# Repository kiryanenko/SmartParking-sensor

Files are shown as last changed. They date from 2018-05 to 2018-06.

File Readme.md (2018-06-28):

Система мониторинга парковочных мест
====================================
МК-подсистема регистрации свободных парковочных мест
----------------------------------------------------

### АННОТАЦИЯ

Дипломный проект посвящен разработке системы мониторинга парковочных
мест. При выполнении дипломного проекта, было проведено исследование IoT
технологий в сфере транспортной инфраструктуры. В рамках исследования
был проведен анализ существующих систем. На основании этого был
спроектирован недорогой относительно конкурентов аппаратно-программный
прототип системы мониторинга парковочных мест. Основное назначение
системы заключается в определении наличия свободных парковочных мест и
отображении этих данных пользователям. Данная система позволит
пользователям (водителям) в режиме реального времени получать актуальную
информацию о состоянии парковочных мест.

### ABSTRACT

The diploma project is devoted to the development of a monitoring system
for parking places. When carrying out the diploma project, was conducted
research IoT technologies in the field of transport infrastructure. As
part of the research, existing systems were analyzed. Based on this, the
hardware-software prototype of a monitoring system for parking places
was designed inexpensive with respect to competitors. The main purpose
of the system is to determine the availability of parking spaces and
display data for users. This system allows users (drivers) to receive
up-to-date information about status of parking places in real time.

РЕФЕРАТ
-------

Разработан проект «Система мониторинга парковочных мест». Основное
назначение системы заключается в определении наличия свободных
парковочных мест и отображении этих данных пользователям. Данная система
позволит пользователям (водителям) в режиме реального времени получать
актуальную информацию о состоянии парковочных мест. Данная система
состоит из: «МК-подсистемы регистрации свободных парковочных мест»,
вычислительного хаба и сервера.

«МК-подсистема регистрации свободных парковочных мест» фиксирует наличие
свободных парковочных мест. К микроконтроллеру подключаются сенсоры,
каждый из которых следит за своим парковочным местом. Через радиомодуль
RFM95W информация о состоянии парковочных мест (свободно / занято)
передается в вычислительный хаб, для последующей обработки. Реализована
функция оплаты парковочного места, с отображением на дисплее и
подтверждением оплаты с клавиатуры.

Основное назначение вычислительного хаба, состоит в осуществлении
взаимодействия сервера, датчиков «МК-подсистема регистрации свободных
парковочных мест» и других компонентов системы.

Сервер осуществляет сбор данных с датчиков «МК-подсистема регистрации
свободных парковочных», управление всеми компонентами системы и вывод
данных пользователям об актуальном состоянии парковочных мест

Материалы по дипломному проекту представлены в виде графической части,
приложения с отлаженным программным кодом и расчетно-пояснительной
записки.

ОПРЕДЕЛЕНИЯ, ОБОЗНАЧЕНИЯ И СОКРАЩЕНИЯ
-------------------------------------

- БС - беспроводная сеть
- БД - база данных
- МК - микроконтроллер
- МКПМ - модуль контроля парковочного места
- МКПРСПМ - МК-подсистема регистрации свободных парковочных мест
- ОС - операционная система
- ПМ - парковочное место
- ПО - программное обеспечение
- СМПМ - система мониторинга парковочных мест
- СУБД - система управления базами данных
- ТС - транспортное средство
- УГО - условно графическое обозначение.
- EEPROM - энергонезависимая перезаписываемая память
- IoT - internet of things
- LoRa - Long Range, метод модуляции в беспроводных сетях
- MQTT - message queue telemetry transport

СОДЕРЖАНИЕ
----------

[ВВЕДЕНИЕ](#ВВЕДЕНИЕ)

[Анализ требований к СМПМ](#Анализ-требований-к-СМПМ)

[Разработка диаграммы вариантов использований](#Разработка-диаграммы-вариантов-использований)

[Описание и структура СМПМ](#Описание-и-структура-СМПМ)

[Описание функциональной схемы СМПМ](#Описание-функциональной-схемы-СМПМ)

[Разработка МКПРСПМ](#Разработка-МКПРСПМ)

[Анализ требований к разрабатываемому устройству](#Анализ-требований-к-разрабатываемому-устройству)

[Разработка структурной схемы МКПРСПМ](#Разработка-структурной-схемы-МКПРСПМ)

[Разработка функциональной схемы МКПМ](#Разработка-функциональной-схемы-МКПМ)

[Разработка функциональной схемы МКПРСПМ](#Разработка-функциональной-схемы-МКПРСПМ)

[Разработка принципиальной схемы](#Разработка-принципиальной-схемы)

[Выбор элементной базы](#Выбор-элементной-базы)

[Микроконтроллер ATMEGA328](#Микроконтроллер-atmega328)

[Радиочастотный приёмопередатчика RFM95W](#Радиочастотный-приёмопередатчика-rfm95w)

[Расширитель портов PCF8574](#Расширитель-портов-pcf8574)

[Сравнение сенсоров присутствия автомобиля](#Сравнение-сенсоров-присутствия-автомобиля)

[Ультразвуковой датчик расстояния HC-SR04](#Ультразвуковой-датчик-расстояния-hc-sr04)

[Часы реального времени DS3231SN](#Часы-реального-времени-ds3231sn)

[Описание принципиальной схемы МКПМ](#Описание-принципиальной-схемы-МКПМ)

[Описание принципиальной схемы МКПРСПМ](#Описание-принципиальной-схемы-МКПРСПМ)

[Расчет потребляемой мощности](#Расчет-потребляемой-мощности)

[Описание разработанного программного обеспечения](#Описание-разработанного-программного-обеспечения)

[Описание схемы алгоритма](#Описание-схемы-алгоритма)

[Описание диаграммы классов](#Описание-диаграммы-классов)

[Описание системы сообщений МКПРСПМ](#Описание-системы-сообщений-МКПРСПМ)

[Тестирование СМПМ](#Тестирование-СМПМ)

[ЗАКЛЮЧЕНИЕ](#ЗАКЛЮЧЕНИЕ)

[Приложение В. Тестирование](/docs/Приложение%20В.%20Тестирование%20СMПМ.pdf)

[Приложение Е. Графическая документация](/docs/Приложение%20Е.%20Графическая%20документация.pdf)

ВВЕДЕНИЕ
--------

Дипломный проект «Система мониторинга парковочных мест» выполняется на
основании учебного плана кафедры ИУ6 с исходными данными, заданными в
техническом задании. Целью работы является проектирование системы
мониторинга парковочных мест.

Формирование специализированных зон для стоянки автотранспорта началось
почти одновременно с появлением первых автомобилей. Число машин
стремительно растет и для решения возникнувшей проблемы ограниченности
парковочных мест начали внедрять современные технологии.

Основным направлением развития являются «умные» датчики парковки. Такие
датчики встраиваются в дорожное полотно на места парковок и отслеживают
свободно ли машиноместо над ними, отдавая данные в общую систему.
Используя сеть таких датчиков, формируется карта парковок, состояния
которых рассылается пользователям на улицах с помощью специальных табло
или мобильного приложения.

Такая система позволяет решить следующие задачи:
-   сокращение очередей и времени поиска свободного места на парковке;
-   организация оптимального движения транспортных средств и пешеходов
    на парковке;
-   визуальное оповещение о количестве свободных мест в реальном времени
    с помощью информационных табло или на веб-портале;
-   оптимизация работы парковочного пространства.

В ходе данной работы была спроектирована «Система мониторинга
парковочных мест». Основное назначение системы заключается в определении
наличия свободных парковочных мест и отображении этих данных
пользователям. Данная система позволит пользователям (водителям) в
режиме реального времени получать актуальную информацию о состоянии
парковочных мест. Данная система состоит из: «МК-подсистемы регистрации
свободных парковочных мест», вычислительного хаба и сервера.

Анализ требований к СМПМ
========================

Разработка диаграммы вариантов использований
--------------------------------------------

Основное назначение СМПМ заключается в определении наличия свободных
парковочных мест и отображении этих данных пользователям. Данная система
позволяет пользователям (водителям) в режиме реального времени получать
актуальную информацию о состоянии парковочных мест.

Для уточнения требований к функционированию системы необходимо
определить варианты её использования при помощи диаграммы вариантов
использования. Система взаимодействует с двумя видами действующих лиц:
пользователь (водитель) и владелец стоянки. Соответствующие диаграммы
для этих лиц показаны на рисунках 5 и 6.

Диаграмма вариантов использований для пользователя

Рисунок 5 - Диаграмма вариантов использований для пользователя

Диаграмма вариантов использований для владельца стоянки

Рисунок 6 - Диаграмма вариантов использований для владельца стоянки

Описание и структура СМПМ
-------------------------

На рисунке 7 представлена структурная схема системы мониторинга
парковочных мест. Система мониторинга парковочных мест состоит из
следующих блоков:
-   МК-подсистема регистрирования свободных парковочных мест (МКПРСПМ),
-   вычислительный хаб,
-   сервер.

Датчики МКПРСПМ служат для фиксации наличия свободных парковочных мест и
оплаты. МКПРСПМ формирует пакеты с информацией о свободных парковочных
местах и передаёт их на вычислительный хаб по беспроводной сети LoRaWAN.

Вычислительный хаб, представленный в виде микрокомпьютера Raspberry Pi,
необходим для осуществления взаимодействия сервера, МКПРСПМ и других
компонентов системы. Хаб выполняет приём пакетов, переданных с МКПРСПМ,
формирует пакеты MQTT и передает их на сервер по сети интернет. Обратно
от сервера хаб получает команды управления МКПРСПМ, которые также
передаются по сети LoRaWAN, на МК-подсистемы.

Пользователь с мобильного устройства на платформе Android с
установленным приложением сможет посмотреть карту с указанием
местоположений свободных парковочных мест. Мобильное приложение получает
данные о парковочных местах с помощью API-сервисов, предоставляемых
сервером.

Структурная схема системы мониторинга парковочных мест

Рисунок 7 - Структурная схема системы мониторинга парковочных мест

Веб-клиент, предоставляет карту со свободными парковочными местами.
Также для владельцев стоянок, предоставляется возможность для управления
за парковочными местами: изменение тарифного плана, настройка параметров
МКПСРСПМ.

Описание функциональной схемы СМПМ
----------------------------------

На рисунке Рисунок 8 показана функциональная схема СМПМ. Система
работает следующим образом. В МКПРСПМ сигнал о состоянии парковочного
места приходит от сенсора присутствия автомобиля, после чего МК
ATMEGA328 формирует пакеты и отправляет их через радиомодуль RFM95 по
сети LoRaWAN на вычислительный хаб. Также по сети LoRaWAN МКРСППМ может
принять команды для изменения настроечных параметров.

Вычислительный хаб служит для осуществления взаимодействия сервера,
МКПРСПМ и других компонентов системы. Хаб через радиомодуль RFM95
принимает пакеты, переданные с МКПРСПМ, формирует MQTT пакеты и передает
их на сервер и на другие компоненты системы. Данные внутри MQTT пакетов
передаются в формате JSON. Обратно от сервера хаб получает команды
управления МКПРСПМ, которые также передаются по сети LoRaWAN, на
МК-подсистемы. ПО для вычислительного хаба написано с использованием
фреймворка Qt. На вычислительном хабе может быть установлено серверное
ПО, тем самым хаб сформирует локальную сеть, внутри которой сможет
работать как сервер. MQTT - это легкий протокол для передачи данных,
который идеально подходит для взаимодействия большого количества IoT
устройств. Таким образом, к вычислительному хабу возможно подключить
множество других устройств (например, табло индикации количества
свободных парковочных мест), позволяющие взаимодействовать по протоколу
MQTT.

Функциональная схема СМПМ

Рисунок 8 - Функциональная схема СМПМ

Сервер взаимодействует с вычислительным хабом по протоколу MQTT. Для
этого на сервере установлен MQTT брокер Mosquitto. Приложение на
фреймворке Ruby on Rails принимает данные о состоянии ПМ через MQTT
брокер и сохраняет в БД PostgreSQL. Также сервер может управлять
датчиками МКПРСПМ, отправляя команды по протоколу MQTT на вычислительный
хаб. Сервер Nginx является Frontend сервером, он осуществляет раздачу
статики и проксирование запросов на веб-сервер Puma, который уже
взаимодействует с веб-приложением на Ruby on Rails. Веб-приложение для
кэширования использует сервис кэширования Memcached. Для работы Action
Cable, который осуществляет взаимодействие с веб-клиентами по WebSocket,
необходима «key - value» хранилище данных Redis. Чтобы веб-клиент в
режиме реального времени получал данные о состоянии парковочных мест,
данные о парковочных местах в формате JSON периодически отправляются по
протоколу WebSocket.

Разработка МКПРСПМ
==================

Анализ требований к разрабатываемому устройству
-----------------------------------------------

Согласно техническому заданию, необходимо разработать МК-подсистему
регистрации свободных парковочных мест, выполненный на основе
микроконтроллера ATMEGA328. Данный регистратор фиксирует наличие
свободных парковочных мест. К микроконтроллеру подключаются сенсоры,
каждый из которых следит за своим парковочным местом. Через радиомодуль
информация о состоянии парковочных мест (свободно / занято) передается в
вычислительный хаб Raspberry Pi для последующей обработки. Должна быть
реализована функция оплаты парковочного места.

Проанализировав задание, можно заключить, что разрабатываемая система
должна представлять собой аппаратно-программный модуль, содержащий
непосредственно микроконтроллер ATMEGA328, запрограммированный
исполняющей программой. К микроконтроллеру через расширители портов
PCF8574 подключаются сенсоры, следящие за парковочными местами. Также,
расширитель портов PCF8574 используется для вывода информации о
состоянии закрепленного за ним парковочного места. Для коммуникации с
вычислительным хабом Raspberry Pi используется радиомодуль LoRa. Для
реализации функции оплаты парковочного места используется терминал
оплаты, состоящий из дисплея и клавиатуры. Работа с терминалом построена
в диалоговом режиме.

Разработка структурной схемы МКПРСПМ
------------------------------------

МКПРСПМ служит для фиксации наличия свободных парковочных мест и оплаты.
Данная подсистема состоит из следующих элементов (Рисунок 9):
-   микроконтроллер ATMEGA328,
-   модули контроля парковочного места (МКПМ),
-   терминал оплаты,
-   радиомодуль RFM95W.
-   Часы реального времени DS3231

Каждое парковочное место оборудовано МКПМ, состоящем из сенсора, который
определяет свободно ли парковочное место, и расширителем портов PCF8574,
для подсоединения сенсора к МК. Выводами «Free» и «Booked» служат для
отображения информации о текущем состоянии данного парковочного места.
Логическая «1» на выводе «Free» означает, что данное парковочное место
свободно, а «0» - занято. Логическая «1» на выводе «Booked» означает,
что данное место забронировано, а «0» - нет.

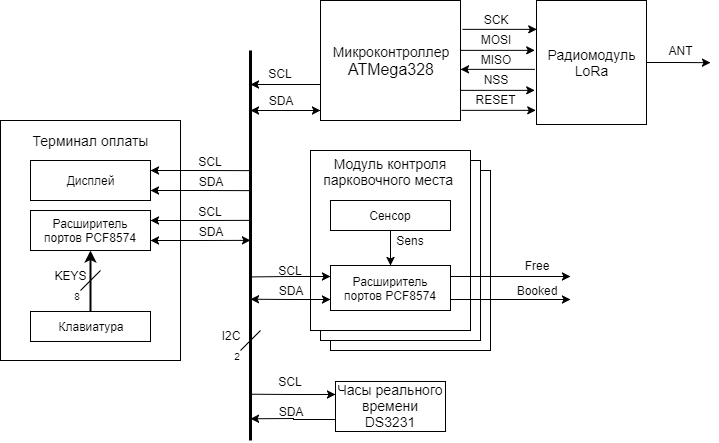
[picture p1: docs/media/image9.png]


Рисунок 9 - Структурная схема МКПРСПМ

Микроконтроллер ATMEGA328 с помощью модулей МКПМ считывает информацию о
состоянии парковочных мест и устанавливает на индикаторах МКПМ
соответствующие состояния. Далее микроконтроллер формирует пакеты с
информацией о свободных парковочных местах для передачи на
вычислительный хаб по беспроводной сети LoRaWAN.

Радиомодуль LoRa осуществляет приём / передачу данных по сети LoRaWAN.
Данный модуль подключён к МК по шине SPI.

Терминал оплаты осуществляет оплату парковочного места по заданному
тарифу. Он состоит из дисплея, для отображения информации для
пользователя, клавиатуры для ввода данных и расширителем портов PCF8574
для соединения клавиатуры с МК по шине I2C.

Часы реального времени DS3231 необходимы для постоянного учёта
хронометрических данных (дата, время) на микроконтроллере. Это позволяет
изменять тариф для оплаты парковочного места в зависимости от времени
суток. А также позволяет отображать текущее время на дисплее. Установка
заданного времени на часах происходит при приходе соответствующего
сообщения «Изменить время» (Описание системы сообщений МКПРСПМ).

Разработка функциональной схемы МКПМ
------------------------------------

Каждое парковочное место оборудованы МКПМ, который определяет свободно
ли данное парковочное место и выводит информацию о состоянии этого
парковочного места.

Была разработана функциональная схема МКПМ, представленная на рисунке Е.5. 
Данная схема описывает функциональный блок «PPCM» (Рисунок 10),
который используется при построении функциональной схемы МКПРСПМ.

УГО функционального блока PPCM

Рисунок 10 - УГО функционального блока PPCM

Ниже на рисунке Рисунок 11, показана функциональная схема МКПМ.

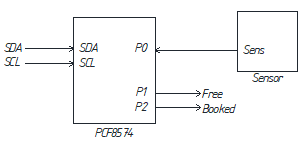
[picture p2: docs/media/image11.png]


Рисунок 11 - Функциональная схема МКПМ

Схема состоит из двух блоков:
-   Сенсор, который определяет свободно ли данное парковочное место.
-   Расширитель портов PCF8574, осуществляющий связь сенсора с МК, а
    также через выводы P1 и P2 выводит информацию о состоянии
    парковочного места. Расширитель подключен к МК по шине I2C. К выводу
    P0 подключается сенсор. Выход P1 выводит сигнал «Free», логическая
    «1» которого означает, что данное парковочное место свободно, а «0» - занято. 
    Выход P2 выводит сигнал «Booked», логическая «1» которого
    означает, что данное парковочное место забронировано, а «0» - нет.

Разработка функциональной схемы МКПРСПМ
---------------------------------------

Исходя из результатов анализа требований, можно выделить следующие функциональные блоки МКПРСПМ:
-   микроконтроллер ATMEGA328;
-   радиомодуль LoRa BEE;
-   USB-UART драйвер ATMEGA16U2
-   модулей МКПМ (PPCM) в количестве до 15 штук, устанавливаемых на каждое парковочное место;
-   клавиатура;
-   расширитель портов PCF8574 для подключения клавиатуры к микроконтроллеру;
-   дисплей;
-   часы реального времени DS3231.

В результате проведенного анализа, была спроектирована функциональная
схема взаимодействия элементов, приведенная на рисунке Е.6.

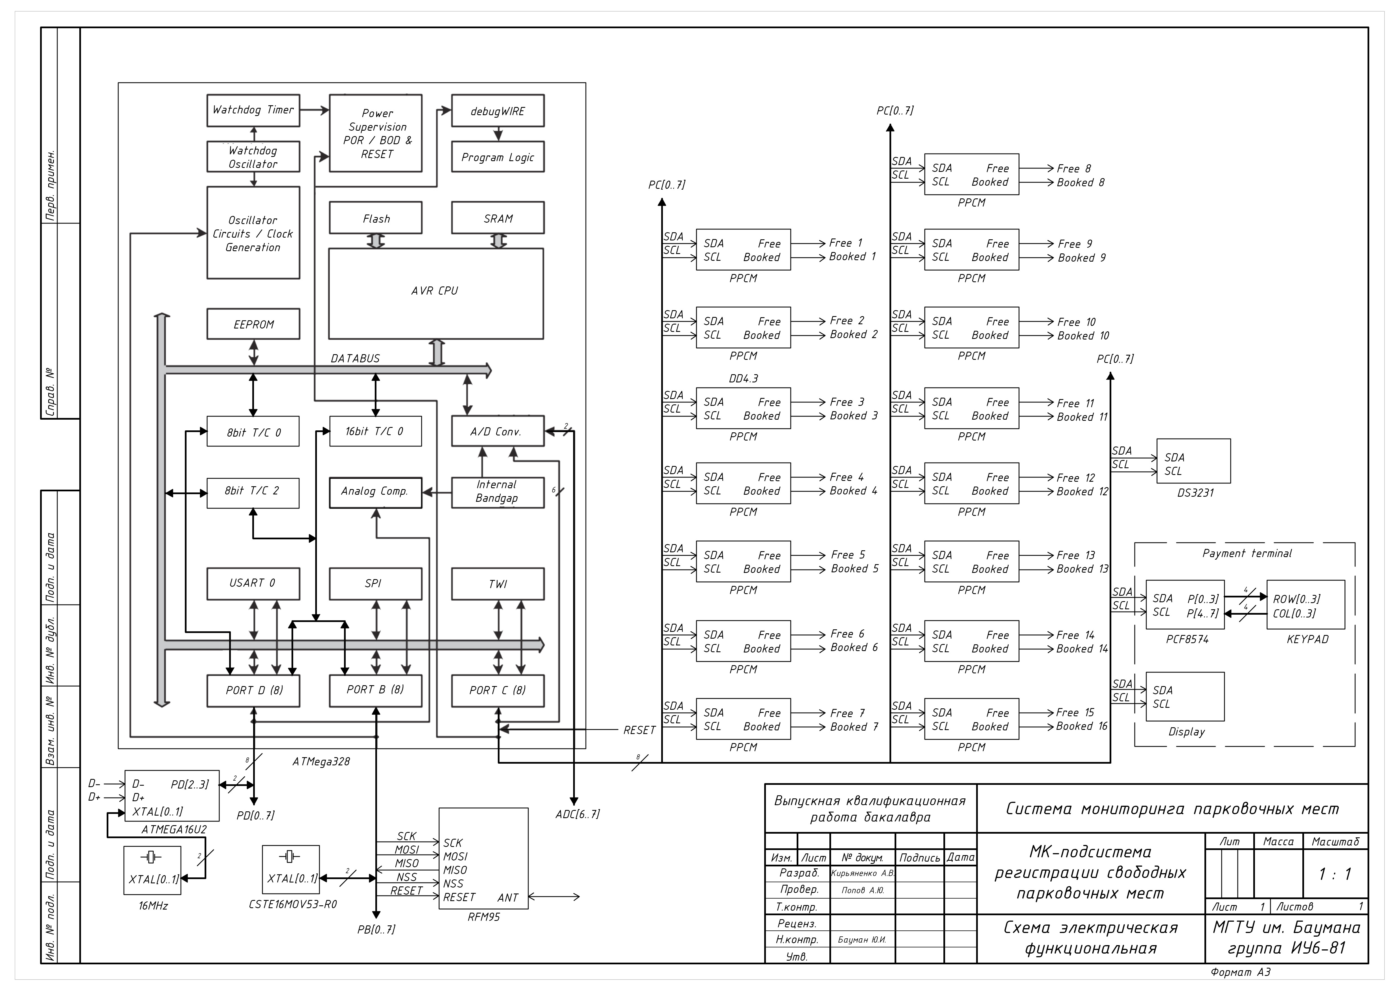
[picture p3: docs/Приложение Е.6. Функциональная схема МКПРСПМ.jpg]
Функциональная схема МКПРСПМ


Разберем структуру взаимодействия элементов на функциональной схеме. На
каждое парковочное место устанавливается МКПМ. Микроконтроллер ATMEGA328
с помощью модулей МКПМ, подключенных к МК по шине I2C, считывает
информацию о состоянии парковочных мест. После обработки данных,
микроконтроллер изменяет состояние парковочного места (свободно /
занято), установив выводы МКПМ в соответствующие состояния. Далее,
микроконтроллер формирует пакет с информацией о состоянии парковочного
места и отправляет его через шину SPI на радиомодуль LoRa BEE, который,
в последствии, передаёт на вычислительный хаб Raspberry Pi, для
последующей обработки.

Для осуществления оплаты заданного парковочного места используется
терминал оплаты, состоящий из дисплея, матричной клавиатуры и
расширителя портов PCF8574 для соединения клавиатуры с МК по шине I2C.
Дисплей подключается к МК по шине I2C. В диалоговом режиме на нём
отображается информация о текущем состоянии оплаты. МК через расширитель
портов опрашивает клавиатуру и определяет нажатые клавиши. Для опроса
клавиатуры подаются на выходы расширителя, подключенные к столбцам
клавиатуры, сканирующие импульсы, а на входах, подключенных к строкам,
определяется, какая клавиша из соответствующего столбца нажата. Далее МК
соответствующе обрабатывает нажатые клавиши и отображает результат
обработки на дисплей.

Разработка принципиальной схемы
-------------------------------

### Выбор элементной базы

#### Микроконтроллер ATMEGA328

В данной работе решено было использовать микроконтроллер семейства AVR,
так как он: широко распространен, имеет развитую систему команд,
удовлетворяет всем современным технологическим требованиям. Данное
семейство восьмиразрядных микроконтроллеров имеет обширное количество
различных моделей. Было решено использовать ATMEGA328 как широко
распространенный и недорогой микроконтроллер, позволяющий реализовать
все поставленные задачи. УГО данного МК показано на рисунке Рисунок 12.

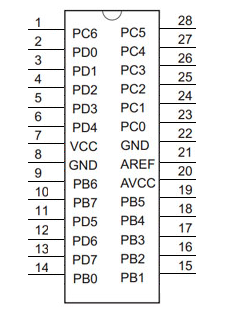
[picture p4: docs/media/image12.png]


Рисунок 12 - УГО ATMEGA328

Описание выводов микроконтроллера приведено в таблице 1.

Таблица 1 - Описание выводов МК ATMEGA328

| № вывода | Мнемоника | Назначение вывода |
|---|---|---|
| 7 | VCC | Питание +5В |
| 8 | GND | Земля |
| 17 | MOSI | Вход ведомого. Служит для передачи данных от ведущего устройства ведомому  |
| 18 | MISO | Выход ведомого. Служит для передачи данных от ведомого устройства ведущему |
| 19 | SCK | Последовательный тактовый сигнал |
| 3-6, 11-19 | PD1-PD6, PB0-PB5 | Цифровые входы/выходы |
| 23-28 | PC0-PC5 | Аналоговые входы/выходы |
| 1 | PC6 | Перезапуск МК |
| 2 | PD0 | Чтение (разъем для программатора) |
| 9 | PB6 | Подключение внешнего резонатора (вход) |
| 10 | PB7 | Подключение внешнего резонатора (выход) |

Микроконтроллер ATMEGA328 обладает следующими особенностями и
техническими характеристиками:
1.  расширенная архитектура RISC:
    -   мощная система команд со 131 инструкцией, большинство из которых выполняются за один машинный цикл,
    -   32 восьмиразрядных регистра общего назначения,
    -   производительность до 20 млн. оп./с на частоте 20МГц,
    -   встроенное умножение за 2 цикла;
2.  высокая износостойкость энергонезависимых сегментов памяти:
    -   32 КБ встроенной самопрограммируемой flash-памяти,
    -   1 КБ энергонезависимой памяти (EEPROM),
    -   2 КБ статической памяти (SRAM),
    -   10000/100000 циклов перезаписи для Flash/EEPROM,
    -   хранение данных в течение 20 лет при температуре 25${^\circ}$С,
3.  системы ввода-вывода: 23 программируемые линии ввода-вывода;
4.  рабочее напряжение: от 1.8 до 5.5 В;
5.  рабочая температура: от -40${^\circ}$ до 85${^\circ}$ С;
6.  рабочая частота (4.5 - 5.5В): 20 МГц;
7.  энергопотребление (1МГц, 1.8 В, 25${^\circ}$ С):
    -   активный режим: 0.2 мА,
    -   режим пониженного энергопотребления: 0.1 мкА.

#### Радиочастотный приёмопередатчика RFM95W

RFM95W - модуль радиочастотного приёмопередатчика, работающий на
частоте 868/915 МГц Работа приёмопередатчика основана на технологии
LoRa, которая позволяет добиться широкополосной передачи данных при
крайне низком энергопотреблении, а также высокой помехоустойчивости. 
Описание выводов RFM95W представлено в таблице 3.

Таблица 3 - Описание выводов RFM95W

  № Вывода                | Мнемоника                            | Описание
  ----------------------- | ------------------------------------ | --------------------------------------------
  1, 8, 10                | GND                                  | Земля
  2                       | MISO                                 | SPI выход последовательной передачи данных
  3                       | MOSI                                 | SPI вход последовательного приема данных
  4                       | SCK                                  | SPI вход синхронизации приема данных
  5                       | NSS                                  | SPI вход выбора подчиненного
  6                       | RESET                                | Вход сброса
  7, 11, 12, 14, 15, 16   | DIO5, DIO3, DIO4, DIO0, DIO1, DIO2   | Цифровой вход / выход конфигурации
  9                       | ANT                                  | Вход / выход на антенну
  13                      | 3,3V                                 | Питание 3,3В

**Технические характеристики:**
-   Максимальный размер канала связи 168 дБ.
-   Режим повышенной мощности, +20дБм/100мВт.
-   Стандартный режим +14 дБм.
-   Программируемая скорость передачи данных до 300 кбит / с.
-   Высокая чувствительность: до -148 дБм.
-   Низкий ток потребления пи приёме 10,3 мА.
-   Полностью интегрированный синтезатор с разрешением 61 Гц.
-   FSK, GFSK, MSK, GMSK, LoRaTM и OOK модуляции.
-   127 дБ динамический диапазон RSSI.
-   Пакетный движок до 256 байтов с CRC.
-   Встроенный датчик температуры и индикатор разряда батареи.
-   Размер модуля: 16x16 мм

#### Расширитель портов PCF8574

PCF8574 - кремневая ИС, выполненная по CMOS-технологии.
Посредством двухлинейной двунаправленной шины I2C она обеспечивает
дистанционное расширение порта ввода - вывода общего назначения в
большинстве серий микроконтроллеров. Устройство состоит из 8-битного
квазипорта ввода-вывода и интерфейса I2C-шины. PCF8574 имеет низкий
потребляемый ток. В устройстве установлена линия прерывания (INT),
которая может быть подключена к логике прерывания микроконтроллера.
Посылая сигнал прерывания по этой линии, дистанционный ввод - вывод
сообщает микроконтроллеру о поступающих на его порты данных, без
необходимости поддерживать связь через I2C-шину. Это значит, что PCF8574
может оставаться простым \"подчиненным\" устройством. На рисунке 14 приведено УГО модификаций PCF8574P и PCF8574AP.

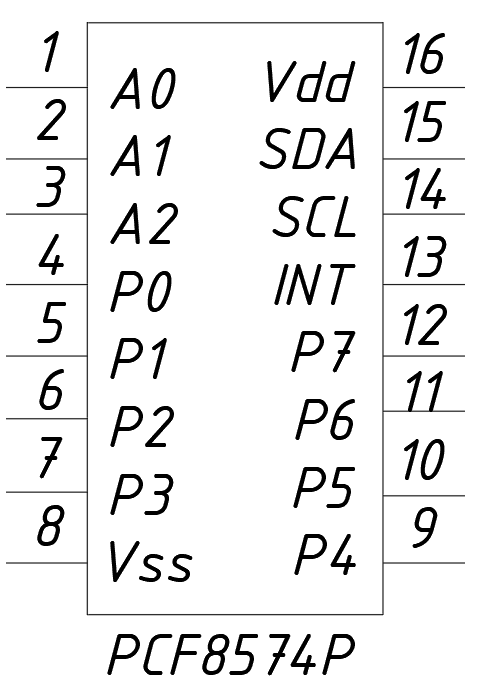
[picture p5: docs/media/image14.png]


Рисунок 14 - УГО расширителя портов PCF8574P и PCF8574AP

В таблице 4 приведено описание выводов PCF8574.

Таблица 4 - Описание выводов PCF8574P / PCF8574AP

  № Вывода          | Мнемоника            | Описание
  ----------------- | -------------------- | --------------------------------------
  1 - 3             | A0 - A2              | Адресные входы
  4 - 7, 9 - 12     | P0 - P3, P4 - P7     | Квази-двунаправленный ввод / вывод
  8                 | Vss                  | Земля
  13                | INT                  | Вывод прерывания
  14                | SCL                  | Последовательная линия синхронизации
  15                | SDA                  | Последовательная линия данных
  16                | Vdd                  | Питание 5 В

У данной микросхемы PCF8574 можно задавать адрес, под которым она будет
обозначаться на шине I2C. Всего имеется 8 вариантов адресации т.е. можно
подключить 8 модулей, что в сумме позволяет нарастить 64 входа/выхода,
используя 2 вывода контроллера. Для изменения адресации необходимо
установить на выводах A0, A1, A2 потенциал, соответствующий логическому «0» или «1».

Модификация PCF8574AP отличается от PCF8574P только базовым адресом: у
PCF8574P - 0x20, а у PCF8574AP - 0x38. Сделано это для того, чтобы к
одной шине можно было подключить до 16-ти расширителей с разными
адресами - максимум 8 штук PCF8574 и 8 штук PCF8574A.

**Технические характеристики:**
-   Рабочий режим питания - от 2.5 до 6 В
-   Низкий ток покоя - максимум 10 мА
-   I^2^C-шина для расширителя параллельного порта
-   Выход прерывания с открытым стоком
-   Дистанционный 8-битный расширитель ввода - вывода I^2^C-шины
-   Адресация на 3 вывода аппаратных адресов для использования до 8
    устройств (до 16 устройств при использовании PCF8574A)

В данной работе каждый расширитель портов закреплен за своим парковочным
местом. Они используются для считывания данных с сенсоров и для вывода
информации о состоянии парковочного места. Был выбран расширитель портов
PCF8574, представленный в форм-факторе PCF8574P и PCF8574АP.

#### Сравнение сенсоров присутствия автомобиля

Ниже в таблице Таблица 5 приведено сравнение сенсоров присутствия автомобиля:

Таблица 5 - Сравнение сенсоров присутствия автомобиля

Свойство                                               | HC-SR04           | E18-D80NK            | US-015            | JSN-SR04T
------------------------------------------------------ | ----------------- | -------------------- | ----------------- | -----------------
Тип                                                    | Ультразвук-овой   | Фотоэлектр-ический   | Ультразвук-овой   | Ультразвук-овой
Обнаружение прозрачных объектов                        | +                 | -                    | +                 | +
Невосприимчивость к бликам                             | +                 | -                    | +                 | +
Работоспособность в условиях недостаточной видимости   | +                 | -                    | +                 | +
Дальность обнаружения                                  | 500 см            | 80 см                | 700 см            | 450 см
Нижний порог обнаружения                               | 3 см              | 3 см                 | 2 см              | 25 см
Цена                                                   | 90 руб            | 280 руб              | 160 руб           | 730 руб

В результате проведенного сравнения (Таблица 5) В качестве сенсора,
следящего за состоянием парковочного места, был выбран ультразвуковой
датчик расстояния HC-SR04, т.к. данный ультразвуковой датчик имеет
следующие преимущества:
-   обнаружение прозрачных объектов;
-   невосприимчивость к световым вспышкам и бликам;
-   работоспособность в сложных условиях (туман, пыль, пар);
-   низкая цена.

#### Ультразвуковой датчик расстояния HC-SR04

Бесконтактный направленный датчик HC-SR04, используя
ультразвуковые волны, измеряет расстояние до объекта. На плате модуля
размещены пьезоизлучатель ультразвука и воспринимающий отраженную волну
микрофон. В отличие от инфракрасных дальномеров на ультразвуковой датчик
HC-SR04 не влияют источники света или цвет препятствия. 
Внешний вид данного датчика показан на рисунке 15.

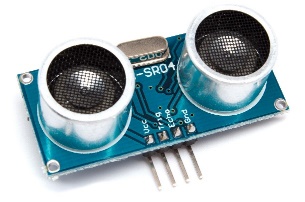
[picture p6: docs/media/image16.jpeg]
Внешний вид ультразвукового датчика расстояния HC-SR04 http://edusnab.ru/upload/iblock/d09/d09faf9a969df7717f0798c8ba945372.jpg


Рисунок 15 - Внешний вид ультразвукового датчика расстояния HC-SR04

Ниже в таблице Таблица 6 приводится описание выводов данного датчика.

Таблица 6 - Описание выводов ультразвукового датчика расстояния HC-SR04

  № Вывода   | Мнемоника   | Описание
  ---------- | ----------- | --------------------------------------------------------------------------------------------------------------------------------------------
  1          | VCC         | Питание +5В
  2          | GND         | Земля
  3          | Trig        | Цифровой вход для включения измерения
  4          | Echo        | Цифровой выход. После завершения измерения, на этот выход будет подана логическая единица на время, пропорциональное расстоянию до объекта

Технические характеристики:
-   Напряжение питания 5 В
-   Ток потребления в режимах
-   ожидания до 2 мА
-   работы 15 мА
-   Частота ультразвука 40 кГц
-   Угол обзора 15 градусов
-   Измеряемое расстояние
-   от 0,03 до 0,6 м с разрешающей способностью 3 мм
-   от 0,6 до 5 м погрешность увеличивается

**Принцип работы:**
1.  Подается импульс продолжительностью 10 мкс, на вывод `Trig`.
2.  Внутри дальномера входной импульс преобразуется в 8 импульсов
    частотой 40 КГц и посылается вперед через \"T глазик\"
3.  Дойдя до препятствия, посланные импульсы отражаются и принимаются
    \"R глазиком\" (Рисунок 17). Получаем выходной сигнал на выводе `Echo`.
4.  Непосредственно на стороне контроллера переводим полученный сигнал в
    расстояние.

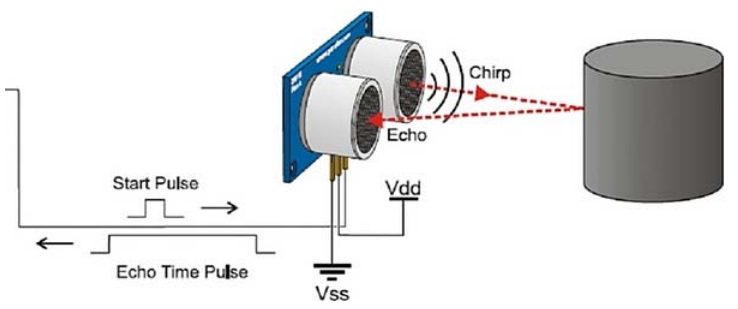
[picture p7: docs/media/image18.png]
Принцип работы ультразвукового датчика расстояния HC-SR04


Рисунок 17 - Принцип работы ультразвукового датчика расстояния HC-SR04

#### Часы реального времени DS3231SN

Для постоянного учёта хронометрических данных (дата, время) на
микроконтроллере используются часы реального времени DS3231SN. Внешний
вид модуля часов реального времени представлен на рисунке 18.

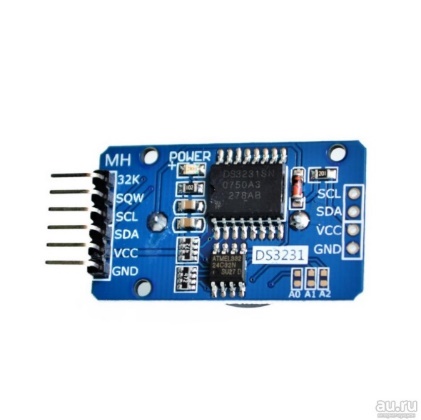
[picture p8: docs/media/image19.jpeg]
Внешний вид модуля часов реального времени DS3231SN https://media2.24aul.ru/imgs/583aea12231ede39d8a435ef/modul-chasov-realnogo-vremeni-zs042-arduino-rtc-2-8614799.jpg


Рисунок 18 - Внешний вид модуля часов реального времени DS3231SN

В таблице 7 приводится описание выводов часов.

Таблица 7 - Описание выводов часов реального времени DS3231SN

  № Вывода   | Мнемоника   | Описание
  ---------- | ----------- | -------------------------------------------
  1          | 32kHz       | Тактовый вывод с частотой 32кГц
  2          | VCC         | Питание +5В
  3          | SQW         | Программируемый выход Square-Wave сигнала
  4          | RST         | Сброс
  5 - 12     | N.C.        | Не соединения
  13         | GND         | Земля
  14         | V~BAT~      | Питание от батареи 3,3В
  15         | SDA         | Последовательная линия данных
  16         | SCL         | Последовательная линия синхронизации

**Технические характеристики:**
-   Рабочая температура -40°C \~ 85°C
-   Напряжение питания, батареи 2,3 V \~ 5,5 V
-   Напряжение питания 2,3 V \~ 5,5 V
-   Интерфейс подключения I²C

Микросхема DS3231 представляет собой высокоточные часы реального времени
RTC, которая обладает встроенным кварцевым генератором с температурной
компенсацией, благодаря чему уход времени составляет всего ±2 минуты за
год. Дополнительно реализована функция будильника, также имеется выход прерываний.

Микросхема использует интерфейс передачи данных I2C. Адрес микросхемы (7 бит) на шине I2C равен `1101000`.

### Описание принципиальной схемы МКПМ

Были спроектированы принципиальные схемы МКПМ на базе PCF8574P и
PCF8574АP, которые представлены на рисунках Е.8 и Д10 соответственно.
Данные схемы соответственно описывают блоки `PPCM` и `PPCM_A`. 
Данные модули отличаются от друг драга - модификацией расширителя порта PCF8574, на которой они построены.
Модуль PPCM построен на базе расширителя порта PCF8574P, а `PPCM_A` - на
базе PCF8574АP. Функциональная схема данных модулей представлена на
рисунке Е.5 и была описана в п.п. 0. В таблице Таблица 8 приведено
описание выводов МКПМ.

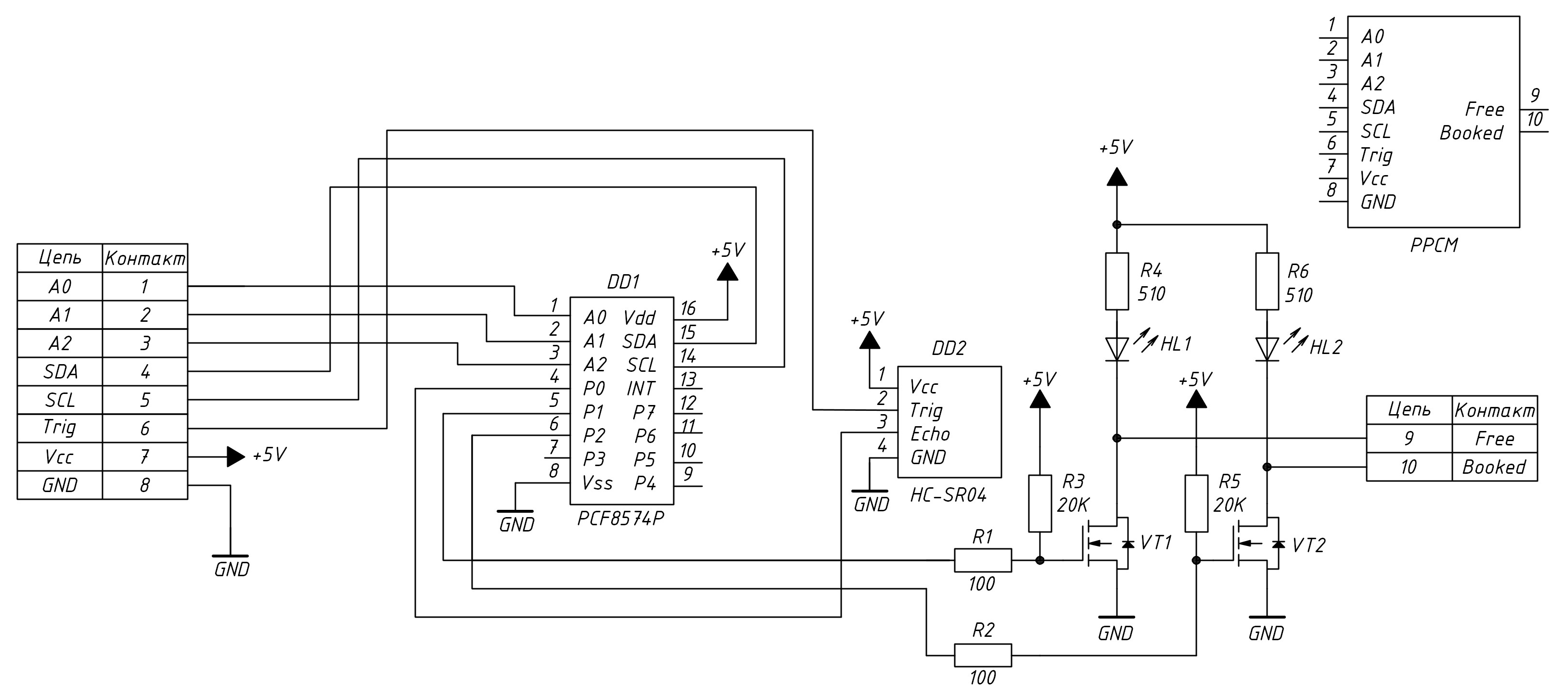
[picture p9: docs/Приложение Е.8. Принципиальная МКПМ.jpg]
Принципиальная схема МКПМ


Таблица 8 - Описание выводов модулей PPCM / PPCM_A

  № Вывода   | Мнемоника   | Описание
  ---------- | ----------- | ----------------------------------------------------------------------------------------------------------
  1 - 3      | A0 - A2     | Адресные входы
  4          | SDA         | Последовательная линия данных
  5          | SCL         | Последовательная линия синхронизации
  6          | Trig        | Цифровой вход для включения измерения
  7          | VCC         | Питание +5В
  8          | GND         | Земля
  9          | Free        | Выводит сигнал «Free» логическая «1» означает, что данное парковочное место свободно, а «0» - занято
  10         | Booked      | Выводит сигнал «Booked» логическая «1» означает, что данное парковочное место забронировано, а «0» - нет

За каждым парковочным местом закреплен свой МКПМ, состоящий из
расширителя портов PCF8574 (DD1) и сенсора HC-SR04 (DD2). Расширитель
портов осуществляет связь МК с сенсором и выводит информацию о состоянии
парковочного места. К выводам P1 и P2 расширителя соответственно
подключены светодиоды VD1 и VD2, которые наглядно показывают состояние
данного парковочного места. Данный расширитель портов подключены к МК по
шине I2C. PCF8574 имеет 3 адресных входа, таким образом, можно
подключить до 8 таких устройств, следовательно, МКПРСПМ может
обслуживать до 8 парковочных мест. Модификация PCF8574AP имеет другой
базовый адрес, следовательно, параллельно можно подключить еще 8
устройств PCF8574AP, тогда разрабатываемое устройство сможет обслуживать
до 15 парковочных мест + 1 расширитель для подключения клавиатуры к МК.
В таблице 9 приведено описание ролей выводов расширителя портов PCF8574 (DD2).

Таблица 9 - Роли выводов расширителя портов PCF8574P / PCF8574AP

  Контакт                 | Роль
  ----------------------- | ---------------------------------------------------------------------------------------
  1, 2, 3 - A0, A1, A2    | Адресные входы
  4 - P0                  | Выход на вывод Trig сенсора HC-SR04 для включения измерения
  5 - P1                  | Выводится логическая «1», в случае если парковочное место свободно, иначе - «0»
  6 - P2                  | Выводится логическая «1», в случае если парковочное место забронировано, иначе - «0»
  8 - Vss                 | Земля
  14 - SCL                | Последовательная линия синхронизации
  15 - SDA                | Последовательная линия данных
  16 - Vdd                | Питание +5В

Сенсор HC-SR04 (DD2) осуществляет мониторинг занятости данного
парковочного места. Вход Trig сенсора соединен с выводом P0 расширителя
портов PCF8574 (DD1). Для включения измерения сенсора МК подаёт сигнал
на вывод P0 соответствующего расширителя портов. После завершения
измерения на выходе Echo сенсора HC-SR04 будет подана логическая единица
на время, пропорциональное расстоянию до объекта. Выход Echo сенсора
соединён с МК через вход PD3. В таблице 10 приведено описание
ролей выводов данного сенсора.

Таблица 10 - Роли выводов сенсора HC-SR04

  Контакт     | Роль
  ----------- | -------------------------------------------------------------------------------------------------------------------------
  1 - VCC     | Питание +5В
  2 - GND     | Земля
  3 - Echo    | Цифровой вход для включения измерения.
  4 - Trig    | Цифровой выход, после завершения измерения, будет подана логическая единица на время, пропорциональное расстоянию до ТС

Расширители портов PCF8574 (DD1) выдают очень низкий ток 100 мкА,
поэтому были добавлены MOSFET-транзисторы (VT1, VT2) для усиления
выходных сигналов «Free» и «Booked». В цепь затвора транзисторов были
добавлены подтягивающие резисторы (R3, R5), чтобы гарантированно
удерживать высокий уровень на затворе мосфета при отсутствии сигнала
низкого уровня от расширителя (DD1). Это исключает самопроизвольное
выключение транзистора. В разрыв цепи затвора также установлены
резисторы (R1, R2) номиналом 100 Ом, для предотвращения кратковременных
выбросов тока и защиты вывода PCF8574.

### Описание принципиальной схемы МКПРСПМ

На основе описанной элементной базы была разработана
принципиальная схема МКПРСПМ для 15 парковочных мест, которая доступна
для ознакомления на рисунке Е.13.

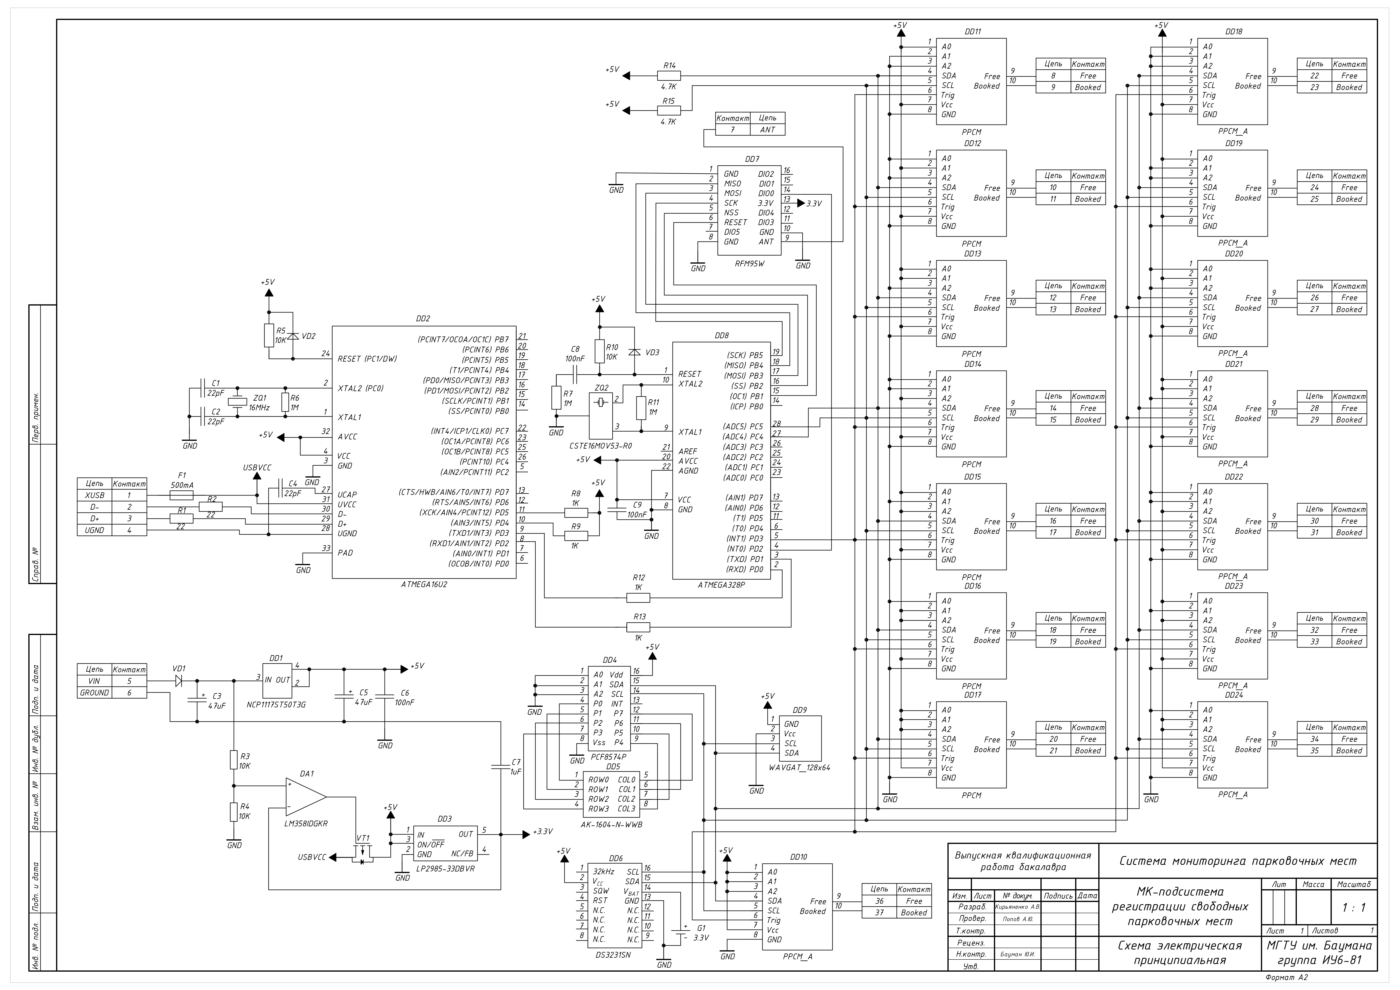
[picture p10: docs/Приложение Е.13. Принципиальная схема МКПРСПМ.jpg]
Принципиальная схема МКПРСПМ


Модуль RFM95W (DD7), осуществляющий передачу и приём данных по сети
LoRa, подключен к МК ATMEGA328P-PU (DD8) шине SPI. В таблице 11
приведено описание подключения модуля RFM95W к МК.

Таблица 11 - Подключение модуля RFM95W к МК ATMEGA328P

  Контакт RFM95W    | Контакт МК         | Роль
  ----------------- | ------------------ | -----------------------------------------------------------------------------------
  1, 8, 10 - GND    | -                  | Земля
  2 - MISO          | 18 - PB4 (MISO)    | Приём данных от модуля на МК
  3 - MOSI          | 17 - PB3 (MOSI)    | Передача данных от МК на модуль
  4 - SCK           | 19 - PB5 (SCK)     | Синхронизация передачи данных
  5 - NSS           | 16 - PB2 (SS)      | Выбор подчиненного устройства
  6 - RESET         | 15 - PB1           | Перезапуск модуля
  9 - ANT           | -                  | Вывод на антенну
  13 - 3,3V         | -                  | Питание +3,3В
  14 - DIO0         | 4 - PD2 (INT0)     | Возникновение прерывание на МК при успешном приёме / передачи пакета по сети LoRa

Микроконтроллер Arduino Uno R3 содержит встроенный драйвер USART-USB,
выполненный на ATMEGA16U2 (DD2), необходимый для передачи и приёма
данных на ПЭВМ по последовательному интерфейсу. Таким образом, с помощью
данного модуля можно, как альтернатива модулю RFM95, осуществлять приём / передачу данных.

Для работы шины I2C необходима внешняя подтяжка к питанию, состоящая из
двух резисторов. В данном проекте такими резисторами являются R14 и R15,
номинал которых равен 4,7КОм.

За каждым парковочным местом закреплен свой модуль МКПМ (DD10 - DD24),
которые разделяются на две модификации PPCM (DD11 - DD17) и PPCM_A
(DD10, DD18 - DD24). Данные модули подключаются к МК по шине I2C. PPCM
отличается от PPCM\_A только базовым адресом: у PPCM - `0x20`, а у
PPCM_A - `0x38`. Таким образом, можно подключить до 15 таких устройств,
что позволит МКПРСПМ обслуживать 15 парковочных мест. В таблице 12 приведено описание подключения модулей МКПМ к МК.

Таблица 12 - Подключение модуля PPCM / PPCM\_A к МК ATMEGA328P

  Контакт МКПМ            | Контакт МК   | Роль
  ----------------------- | ------------ | -----------------------------------------------------------------------------------------------------------
  1, 2, 3 - A0, A1, A2    | -            | Адресные входы
  4 - SDA                 | 27 - PC4     | Последовательная линия данных
  5 - SCL                 | 28 - PC5     | Последовательная линия синхронизации
  6 - Trig                | 5 - PD3      | Цифровой вход для включения измерения
  7 - V~CC\ ~             | -            | Питание +5В
  8 - GND                 | -            | Земля
  9 - Free                | -            | Выводит сигнал «Free» логическая «1» означает, что данное парковочное место свободно, а «0» - занято
  10 - Booked             | -            | Выводит сигнал «Booked» логическая «1» означает, что данное парковочное место забронировано, а «0» - нет

Часы реального времени DS3231SN (DD6), используются для учета
хронометрических параметров. Они подключаются к МК по шине I2C. Чтобы
при отключении питания МКПРСПМ время на часах не сбрасывалось, часы
дополнительно питаются от гальванического элемента G1, напряжение
питания которого равно +3,3В. В таблице 13 описывается подключение часов к МК.

Таблица 13 - Подключение часов реального времени DS3231SN к МК ATMEGA328P

  Контакт DS3231SN   | Контакт МК   | Роль
  ------------------ | ------------ | --------------------------------------
  2 - V~CC~          | -            | Питание +5В
  13 - GND           | -            | Земля
  14 - V~BAT~        | -            | Питание от батареи +3,3В
  15 - SDA           | 27 - PC4     | Последовательная линия данных
  16 - SCL           | 28 - PC5     | Последовательная линия синхронизации

Клавиатура AK-1604-N-WWB (DD5) подключается к МК посредством расширителя
портов PCF8574P (DD4). Строки клавиатуры (ROW0 - ROW3) подключаются к
выводам расширителя P0 - P3, а столбцы (COL0 - COL3) - к выводам P4 - P7. Таким образом, для подключения клавиатуры используются не 8
выводов МК, а 2, т.е. линии шины I2C. В таблице 14 приводится
описание подключения данного расширителя PCF8574P (DD4) к микроконтроллеру.

Таблица 10 - Подключение расширителя портов PCF8574P, отвечающего за клавиатуру, к МК ATMEGA328P

| Контакт PCF8574P | Контакт МК | Роль |
|---|---|---|
| 1, 2, 3 - A0, A1, A2 | - | Адресные входы |
| 4, 5, 6, 7 - P0, P1, P2, P3 | - | Выводы для подключения строк клавиатуры |
| 8 - Vss | - | Земля |
| 9, 10, 11, 12 - P4, P5, P6, P7 | - | Выводы для подключения столбцов клавиатуры |
| 14 - SCL | 28 - PC5 | Последовательная линия синхронизации |
| 15 - SDA | 27 - PC4 | Последовательная линия данных |
| 7 - VDD | - | Питание +5В |

Дисплей WAVGAT_128x64 (DD9) подключается к МК по шине I2C. Ниже в
таблице приведено описание подключения этого дисплея к МК.

Таблица 11 - Подключение дисплея WAVGAT\_128x64 к МК ATMEGA328P

  Контакт WAVGAT_128x64    | Контакт МК  | Роль
  ------------------------ | ----------- | --------------------------------------
  1 - GND                  | -           | Земля
  2 - V~CC~                | -           | Питание +5В
  3 - SCL                  | 28 - PC5    | Последовательная линия синхронизации
  4 - SDA                  | 27 - PC4    | Последовательная линия данных

В качестве драйвера USB-UART используется микроконтроллер ATMEGA16U2
(DD2), обеспечивающий связь микроконтроллера с USB-портом ПЭВМ. При
подключении к ПК Arduino UNO определяется как виртуальный COM-порт.
Заводская прошивка ATMEGA16U2 использует стандартные драйвера USB-COM - установка внешних драйверов не требуется, 
что делает принцип работы микросхемы удобным в эксплуатации. 
В таблице 12 приведено описание подключения драйвера к МК.

Таблица 12 - Описание выводов ATMEGA16U2

  Контакт ATMEGA16U2   | Мнемоника   | Назначение вывода
  -------------------- | ----------- | --------------------------------------------
  4 - VCC              | -           | Питание +5В
  3 - GND              | -           | Земля
  32 - AVCC            | -           | Питание для всех аналоговых устройств
  8 - PD2              | 2 - PD0     | Приём данных на МК
  8 - PD3              | 3 - PD1     | Передача данных от МК
  30 - D-              | -           | Порт USB с отрицательной обратной связью
  29 - D+              | -           | Порт USB с положительной обратной связью
  28 - UGND            | -           | USB земля
  27 - UCAP            | -           | USB регулятор выходного напряжения питания
  1 - XTAL1            | -           | Подключение внешнего резонатора (вход)
  2 - XTAL2            | -           | Подключение внешнего резонатора (выход)

USB-разъем, помимо предоставления интерфейса для последовательной
передачи данных к ПЭВМ, позволяет использовать компьютер, как источник
питания. Для токовой защиты установлен самовосстанавливающийся
предохранитель MF-MSMF050-2 (F1), защищающий порт USB компьютера от
токов короткого замыкания и сверхтоков. Хотя практически все компьютеры
имеют подобную защиту, тем не менее, данный предохранитель обеспечивает
дополнительный барьер. Предохранитель срабатывает при прохождении тока
более 500 мА через USB порт и размыкает цепь до тех пор, пока нормальные
значения токов не будут восстановлены.

Расчет потребляемой мощности
----------------------------

Суммарная мощность, которую потребляет устройство - есть сумма
мощностей элементов, из которых это устройство состоит. 
Мощность - произведение напряжения питания и тока, который протекает через микросхему.

Для расчета потребляемой мощности используем информацию из документации
используемых микросхем и других элементов. Информация о токах и
соответственно мощности, потребляемых микросхемами, приведена в таблице 17.

Таблица 17 - Расчет мощности компонентов

  **Наименование микросхемы**   | **Ток потребления, мА**   | **Напряжение питания**   | **Потребляемая мощность, мВт**
  ----------------------------- | ------------------------- | ------------------------ | --------------------------------
  **ATMEGA328P**                | 16                        | 5                        | 80
  **ATMEGA16U2**                | 50                        | 5                        | 250
  **LoRa BEE**                  | 10,3                      | 3,3                      | 40
  **PCF8574P**                  | 80                        | 5                        | 400
  **HC-SR04**                   | 15                        | 5                        | 75
  **DS3231SN**                  | 3                         | 5                        | 15
  **WAVGAT\_128x64**            | 16                        | 5                        | 80

Используя информацию из таблицы, рассчитаем суммарную потребляемую
мощность, для МКПРСПМ обслуживающего одно парковочное место:

    P = 80 + 250 + 40 + 400 + 75 + 400 + 15 + 80 = 1340 мВт

Для МКПРСПМ обслуживающего 15 парковочных мест, потребляющая мощность
будет составлять:

    P = 80 + 250 + 40 + ( 400 + 75 )*15 + 400 + 15 + 80 = 8710 мВт

Описание разработанного программного обеспечения
------------------------------------------------

### Описание схемы алгоритма

Для реализации указанных в задании функций было разработано программное
обеспечение, обеспечивающее взаимодействие элементов микроконтроллерной
системы и обработку поступающих данных.

Схема алгоритма основной программы представлена на рисунке 21.
Первоначально выполняется настройка и инициализация всех используемых
элементов, после чего программа переходит в бесконечный цикл опроса.

Схема алгоритма основной программы

Рисунок 21 - Схема алгоритма основной программы

Блок «Обработчик входящих сообщений» является составным для компактности
основной блок схемы. Блок схема этой процедуры представлена на рисунке 22.

Схема алгоритма процедуры «Обработчик входящих сообщений»

Рисунок 22 - Схема алгоритма процедуры «Обработчик входящих сообщений»

Ниже на рисунке 23 представлена блок схема процедуры «Обработчик платёжного терминала».

Схема алгоритма процедуры «Обработчик платёжного терминала»

Рисунок 23 - Схема алгоритма процедуры «Обработчик платёжного терминала»

### Описание диаграммы классов

При разработке программы применялся преимущественно объектный подход,
так как данный подход является наиболее удобным для дальнейшей
разработки и поддержки проекта. На рисунке Е.14 представлена диаграмма
классов разработанной программы. Как можно видеть из диаграммы классов
было реализовано два паттерна «Стратегия» и один «Одиночка».

Диаграмма классов

Паттерн «Стратегия» позволяет выбирать алгоритм путём определения
соответствующего класса. Класс `ReceiverTransmitter` является
интерфейсом для классов `RadioModule` и `SerialModule`. Это позволило в
основной программе реализовать процедуру выбора драйвера для приёма и
передачи данных. В случае отсутствия радиомодуля LoRa, то в качестве
драйвера будет выбран драйвер USB-UART.

При создании объекта класса `ReceiverTransmitter` в конструктор
передаётся обработчик входящих сообщений - объект, принадлежащий
абстрактному классу `AbstractReceiveMessageHandler`. Это позволяет
задавать различные обработчики входящих сообщений. Например, операция по
изменению ID устройства является небезопасной, и было принято решение
запретить выполнять данную операцию при приёме сообщений по беспроводной
связи, однако при подключении по UART интерфейсу операция разрешена.

Паттерн «Одиночка» - шаблон проектирования, гарантирующий, что в
однопроцессном приложении будет единственный экземпляр некоторого
класса, и предоставляющий глобальную точку доступа к этому экземпляру.
«Одиночкой» является класс `Parameters`, который содержит в себе
настроечные параметры, и осуществляющий запись параметров память EEPROM.
Определив этот класс «Одиночкой», позволило иметь доступ к единственному
экземпляру данного класса из любого места программы.

Описание системы сообщений МКПРСПМ
----------------------------------

Реализована система сообщений для приёма и передачи информации между
МКПРСПМ и вычислительным хабом. Каждое принимаемое и отправляемое
сообщение состоит из заголовка и тела сообщения.

Структура заголовка:
1.  1 байт - Тип сообщения
2.  4 байта - Идентификатор МКПРСПМ

Далее рассматривается структура тела сообщения для каждого типа
сообщений, отправляемых с МКПРСПМ
-   Инициализация МКПРСПМ:
    1.  2 байта - Период опроса датчиков
    2.  2 байта - Период отправки сообщений о состоянии парковочного места
    3.  2 байта - Дневной тариф
    4.  2 байта - Ночной тариф
    5.  4 байта - Время начала дневного тарифа
    6.  4 байта - Время начала ночного тарифа
    
    * **Пакет:**  
        ```
        uint8_t type | uint32_t ID | uint16_t samplingPeriod | uint16_t sendingPeriod | uint16_t dayCost | uint16_t nightCost | uint32_t dayStartTime | uint32_t nightStartTime
        \x49\x00\x00\x00\x01\x00\xFF\x10\x00\x00\xFF\x00\xFF\x00\x00\x00\xFF\x00\x00\x00\xFF
        ```
    * **UART пакет:**
        ```
        uint8_t len | uint8_t type | uint32_t ID | uint16_t samplingPeriod | uint16_t sendingPeriod | uint16_t dayCost | uint16_t nightCost | uint32_t dayStartTime | uint32_t nightStartTime
        \x15\x49\x00\x00\x00\x01\x00\xFF\x10\x00\x00\xFF\x00\xFF\x00\x00\x00\xFF\x00\x00\x00\xFF
        ```

-   Состояние парковочного места:
    1.  1 байт - Идентификатор парковочного места
    2.  1 байт - Булевое значение свободно ли парковочное место

    * **Пакет:**  
        ```
        uint8_t type | uint32_t ID | uint8_t placeId | uint8_t free  
        \x53\x00\x00\x00\x01\x01\x01
        ```
    * **UART пакет:**  
        ```
        uint8_t len | uint8_t type | uint32_t ID | uint8_t placeId | uint8_t free
        \x07\x53\x00\x00\x00\x01\x01\x01
        ```

-   Оплата парковочного места:
    1.  1 байт - Идентификатор парковочного места
    3.  4 байта - Время бронирования
    4.  2 байта - Внесенная сумма
    5.  2 байта - Итоговая стоимость
    
    * **Пакет:**  
        ```
        uint8_t type | uint32_t ID | uint8_t placeId | uint32_t time | uint16_t payment | uint16_t totalCost
        \x50\x00\x00\x00\x01\x01\x00\x00\x00\xFF\x00\xFF\x00\xFF
        ```
    * **UART пакет:**  
        ```
        uint8_t len | uint8_t type | uint32_t ID | uint8_t placeId | uint32_t time | uint16_t payment | uint16_t totalCost
        \x0E\x50\x00\x00\x00\x01\x01\x00\x00\x00\xFF\x00\xFF\x00\xFF
        ```

Структура тела сообщения для основных типов принимаемых сообщений:

-   Изменить идентификатор МКПРСПМ.
    1.  4 байта - Новый идентификатор МКПРСПМ
    
    * **Пакет:**  
        ```
        uint32_t ID | uint8_t type | uint32_t newID`  
        \x00\x00\x00\x01\x69\x00\x00\x00\x02`
        ```
    * **UART пакет:**  
        ```
        uint8_t len | uint32_t ID | uint8_t type | uint32_t newID`  
        \x09\x00\x00\x00\x01\x69\x00\x00\x00\x02`
        ```
    
-   Изменить период опроса сенсоров
    * **Пакет:**  
        ```
        uint32_t ID | uint8_t type | uint16_t period
        \x00\x00\x00\x01\x73\x00\x64
        ```
    * **UART пакет:**  
        ```
        uint8_t len | uint32_t ID | uint8_t type | uint16_t
        \x07\x00\x00\x00\x01\x73\x00\x64
        ```

-   Изменить период отправки сообщений о состоянии парковочного места:
    1.  2 байт - Период отправки сообщений о состоянии парковочного места
    * **Пакет:**
        ```
        uint32_t ID | uint8_t type | uint16_t period 
        \x00\x00\x00\x01\x70\x03\x00
        ```
    * **UART пакет:**  
        ```
        uint8_t len | uint32_t ID | uint8_t type | uint16_t period
        \x07\x00\x00\x00\x01\x70\x03\x00
        ```

-   Изменить время на часах реального времени:
    1.  4 байта - Время

-   Изменить дневной тариф
    1.  2 байта - Стоимость 1 часа в рублях
    
    * **Пакет:**  
        ```
        uint32_t ID | uint8_t type | uint16_t cost
        \x00\x00\x00\x01\x71\x01\x00
        ```
    * **UART пакет:**
        ```
        uint8_t len | uint32_t ID | uint8_t type | uint16_t cost
        \x07\x00\x00\x00\x01\x71\x01\x00
        ```

- Изменить ночной тариф
    * **Пакет:**  
        ```
        uint32_t ID | uint8_t type | uint16_t cost
        \x00\x00\x00\x01\x77\x01\x00
        ```
    * **UART пакет:**  
        ```
        uint8_t len | uint32_t ID | uint8_t type | uint16_t cost
        \x07\x00\x00\x00\x01\x77\x01\x00
        ```
        
-   Изменить параметры настройки
    1.  2 байта - Период опроса датчиков
    2.  2 байта - Период отправки сообщений о состоянии парковочного места
    3.  2 байта - Дневной тариф
    4.  2 байта - Ночной тариф
    5.  4 байта - Время начала дневного тарифа
    6.  4 байта - Время начала ночного тарифа
    
    * **Пакет:**  
        ```
        uint8_t type | uint32_t ID | uint16_t samplingPeriod | uint16_t sendingPeriod | uint16_t dayCost | uint16_t nightCost | uint32_t dayStartTime | uint32_t nightStartTime
        \x73\x00\x00\x00\x01\x00\xFF\x10\x00\x00\xFF\x00\xFF\x00\x00\x00\xFF\x00\x00\x00\xFF
        ```
    * **UART пакет:**  
        ```
        uint8_t len | uint8_t type | uint32_t ID | uint16_t samplingPeriod | uint16_t sendingPeriod | uint16_t dayCost | uint16_t nightCost | uint32_t dayStartTime | uint32_t nightStartTime
        \x15\x73\x00\x00\x00\x01\x00\xFF\x10\x00\x00\xFF\x00\xFF\x00\x00\x00\xFF\x00\x00\x00\xFF
        ```

-   Бронирование парковочного места
    1.  1 байт - Идентификатор парковочного места
    2.  2 байта - Время бронирования
    
    * **Пакет:**  
        ```
        uint32_t ID | uint8_t type | uint8_t placeId | uint32_t period 
        \x72\x00\x00\x00\x01\x01\x00\x00\x00\x14
        ```
    * **UART пакет:**  
        ```
        uint8_t len | uint32_t ID | uint8_t type | uint8_t placeId | uint32_t period
        \x08\x72\x00\x00\x00\x01\x01\x00\x00\x00\x14
        ```

-   Отмена бронирования парковочного места
    1.  1 байт - Идентификатор парковочного места
    
    * **Пакет:**  
        ```
        uint32_t ID | uint8_t type | uint8_t placeId
        \x00\x00\x00\x01\x63\x01
        ```
    * **UART пакет:**  
        ```
        uint8_t len | uint32_t ID | uint8_t type | uint8_t placeId
        \x06\x00\x00\x00\x01\x63\x01
        ```

При отправке сообщения через UART интерфейс перед заголовком добавляется
еще 1 байт - длина сообщения.

Тестирование СМПМ
=================

Для проверки требований, предъявленных в техническом задании, в
разработанной системе мониторинга парковочных мест были протестированы
все компоненты системы, а также было проведено комплексное тестирование
системы (Приложение В). Для тестирования МКПРСПМ был собран отладочный
макет, внешний вид которого изображен на рисунке 30.

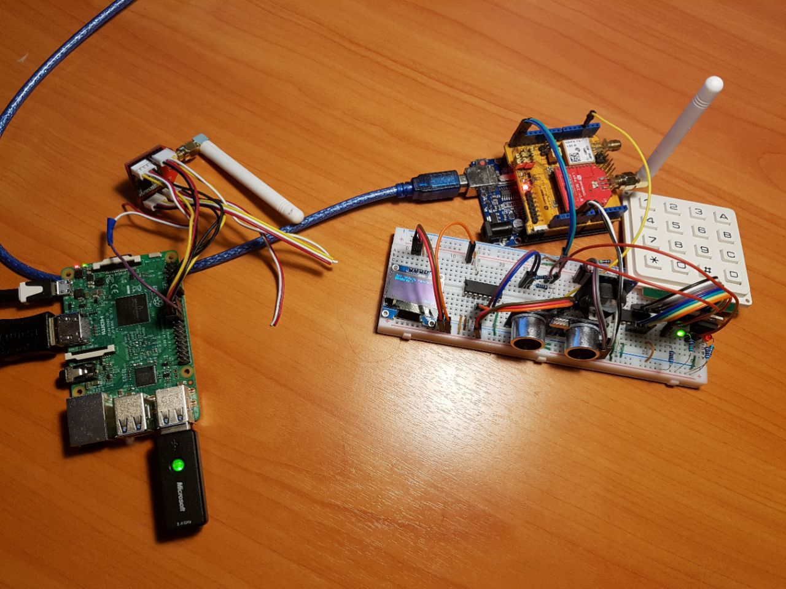
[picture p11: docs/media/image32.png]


Рисунок 30 - Внешний вид отладочного макета

Также для проверки и анализа данных работоспособности при большой
нагрузки было проведено нагрузочное тестирование. Так, например, RPS для
выдачи парковочных мест (п.п. 5.4) при заполненной БД (13582 записи)
составила 846 запросов в секунду (более подробнее см. в Приложение В).

Для обеспечения качества в ходе дальнейшей разработки для веб-приложения
были написаны 60 автоматизированных теста, покрывающие весь функционал.
Из них 14 модульных теста, 6 интеграционных теста и 40 функциональных
тестов контроллеров.

Результатом проведенного тестирования было установлено, что были
выполнены все предъявляемые требования к разработанному прототипу
системы мониторинга парковочных мест.

ЗАКЛЮЧЕНИЕ
==========

В результате выполнения выпускной квалификационной работы бакалавра был
спроектирован и реализован аппаратно-программный прототип «Системы
мониторинга парковочных мест». Такая система для водителей будет в
режиме реального времени предоставлять актуальные данные о состоянии
парковочных мест. Данная система состоит из МК-подсистемы регистрации
свободных парковочных мест, вычислительного хаба и центрального сервера.

Программное обеспечение для компонентов системы написано преимущественно
в объектном стиле, который обеспечивает интеграцию и удобство для
дальнейшей разработки командой разработчиков.

В ходе выполнения работы было проведено исследование IoTтехнологий в
транспортной инфраструктуре, а также анализ существующих систем.
Разработанная система экономически более выгодна относительно
конкурентных систем.

Все компоненты системы были отлажены и протестированы. Для
разработанного серверного ПО были написаны автоматизированные тесты для
обеспечения качества в ходе дальнейшей разработки. Также был проведен
анализ безопасности системы. Таким образом, разработанная система
соответствует всем требованиям, заявленных в техническом задании.

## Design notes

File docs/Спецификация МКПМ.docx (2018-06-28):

Система мониторинга парковочных мест

2

2

2

2

2

1

1

STP16NF06

Транзисторы

Резистор, 510 Ом

Резистор, 20 КОм

Резистор, 100 Ом

Резисторы

GNL-5013HD

Светодиоды

HC-SR04

PCF8574P

Схемы интегральные

Схема электрическая принципиальная

Документация

VT1, VT2

R4, R6

R1, R2

HL1, HL2

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
Приме-

чание

Наименование

Обозначение

А4

Кол.

Поз.

Формат

Зона

Модуль контроля парковочного места на базе PCF8574P

МГТУ им. Н.Э. Баумана, группа ИУ6-81

Инв. № дубл

Взаим. инв. №

2

1

Бауман

Попов

Кирьяненко

Подп. и дата

Инв. № подл.

Подп. и дата

Подп.

Листов

Лист

Лит.

Дата.

№ докум.

Лист.

Изм.

Утв.

Н.контр.

Пров.

Разраб.

R3, R5

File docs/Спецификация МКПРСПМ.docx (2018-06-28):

Система мониторинга парковочных мест

C1, C2, C4

Конденсатор, 22 пФ

1N4007

Конденсаторы

Транзисторы

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
Конденсатор, 1 мкФ

Конденсатор, 100 нФ

Конденсатор, 47 мкФ

КТ3102Е

Диоды

CSTCE16M0V53-R0

Кварцевые резонатор, 16 МГц

Кварцевые резонаторы

LM358IDGKR

Операционный усилители

PPCM_A

PPCM

WAVGAT_128x64

ATMEGA328P-PU

RFM95W

DS3231SN

AK-1604-N-WWB

NCP1117ST50T3G

PCF8574P

LP2985-33DBVR

ATMEGA16U2-MU (R)

Схемы интегральные

Схема электрическая принципиальная

Документация

C7

C6, C8, C9

C3, С5

VT1

VD1 – VD3

ZQ2

ZQ1

DA1

DD10, DD18 – DD24

DD11 – DD17

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
Приме-

чание

Наименование

Обозначение

А2

Кол.

Поз.

Формат

Зона

МК-подсистема регистрации свободных парковочных мест

МГТУ им. Н.Э. Баумана, группа ИУ6-81

Инв. № дубл

Взаим. инв. №

2

1

Бауман

Попов

Кирьяненко

Подп. и дата

Инв. № подл.

Подп. и дата

Подп.

Листов

Лист

Лит.

Дата.

№ докум.

Лист.

Изм.

Утв.

Н.контр.

Пров.

Разраб.

F1

Система мониторинга парковочных мест

1

1

2

4

3

4

2

MF-MSMF050-2

Предохранители

LIR2032

Гальванический элемент

Резистор, 4,7 КОм

Резистор, 1 КОм

Резистор, 1 МОм

Резистор, 10 КОм

Резистор, 22 Ом

Резисторы

G1

R14, R15

R8, R9, R12, R13

R6, R7, R11

R3 – R5, R10

R1, R2

1

1

5

4

3

2

1

Приме-

чание

Наименование

Обозначение

Кол.

Поз.

Формат

Зона

МК-подсистема регистрации свободных парковочных мест

МГТУ им. Н.Э. Баумана, группа ИУ6-81

Инв. № дубл

Взаим. инв. №

2

2

Попов

Кирьяненко

Подп. и дата

Инв. № подл.

Подп. и дата

Подп.

Листов

Лист

Лит.

Дата.

№ докум.

Лист.

Изм.

Утв.

Н.контр.

Пров.

Разраб.

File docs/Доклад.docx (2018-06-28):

# Доклад

# Лист 1. Цели и задачи

Здравствуйте, уважаемые члены государственной аттестационной комиссии. Вашему вниманию представляется выпускная квалификационная работа на тему «Система мониторинга парковочных мест». Данная система позволит пользователям в режиме реального времени получать актуальную информацию о состоянии парковок. А также реализована функция онлайн бронирования парковочного места. Владельцы же стоянок смогут удалённо управлять установленными датчиками МК-подсистемы.

В ходе выполнения работы были выполнены следующие задачи:

- Проведено исследование IoT технологий в сфере транспортной инфраструктуры. А также проведен анализ существующих систем.
- Спроектирована архитектура системы. А также разработана принципиальная схема МК-подсистемы.
- Разработано программное обеспечение для компонентов системы.
- А также проведено тестирование работоспособности всей системы.

Здесь показана структурная схема системы. Она состоит из: МК-подсистемы, вычислительного хаба и центрального сервера.

МК-подсистема представляет из себя микроконтроллер, которому подключаются до 15 сенсоров, каждый из которых следит за своим парковочным местом. Сенсоры крепятся к дорожному полотну под парковочным местом. Через радиомодуль LoRa информация о состоянии парковок передается в вычислительный хаб, для последующей обработки.

Основное назначение вычислительного хаба, состоит в осуществлении взаимодействия сервера, датчиков МК-подсистемы и других компонентов системы. Он с множества датчиков собирает дынные и отправляет центральному серверу.

Сервер осуществляет сбор данных с датчиков, управляет всеми компонентами системы и выводит данные пользователям о состоянии парковок.

# Лист 2. Исследование

В рамках ВКР было проведено исследование IoT технологий в сфере транспортной инфраструктуры.

Архитектура интернет вещей состоит из 4х уровней: уровня сети сенсоров, уровня шлюзов и сетей, сервисного уровня и уровня приложений.

Для передачи данных между вычислительном хабом и сервером использовался протокол MQTT. MQTT организован по принципу издатель/подписчик: издатель является отправителем сообщения, которое публикуется в брокере сообщений, а подписчик получает сообщение из брокера. Данный протокол обладает небольшими накладными расходами на стороне устройства, что позволяет сократить расход батареи и увеличивает количество передаваемых в единицу времени сообщений.

Данные от датчиков передаются по сети LoRaWAN. У LoRaWAN имеется преимущества:

- большая дальность передачи радиосигнала до 10 — 15 км.
- Низкое энергопотребление.
- Высокая проникающая способность радиосигнала.

Но имеет недостатки:

- Низкую пропускную способность.
- Большую задержку передачи данных.

# Лист 3. Функциональная схема системы

Здесь показана функциональная схема системы. Данные от датчиков о состоянии парковочных мест передаются по сети LoRaWAN на вычислительный хаб. Хаб преобразует принятый пакет в формат JSON и передаёт серверу по MQTT. Сервер принимает и сохраняет эти дынные в БД. Веб-приложение периодически отправляет данные о состояниях парковок пользователю по протоколу WebSockets.

Для реализации веб-приложения использовался фреймворк Ruby on Rails с веб-сервером Puma. Фронтенд-сервер Nginx осуществляет раздачу статики и проксирования запросов на веб-сервер. Данные о парковках хранятся в СУБД PostgreSQL. Для кэширования используется сервис Memcached. Key-value хранилище Redis применяется для реализации механизма Action Cable, позволяющий раздавать данные о парковках пользователям по протоколу WebSockets.

# Лист 4. Принципиальная схема

Здесь показана реализованная принципиальная схема МК-подсистемы. Она состоит из:

- радиомодуля LoRa, подключаемый по шине SPI
- множества сенсоров подключаемые по шине I2C через расширитель портов PCF8574
- терминала оплаты состоящего из дисплея и клавиатуры

# Лист 5. Диаграмма классов

Здесь показаны реализованные диаграммы классов для МК-подсистемы и вычислительного хаба. При разработке были использованы такие паттерны проектировании как СТРАТЕГИЯ и СИНГЛТОН. Например, абстрактный класс «Driver» у вычислительного хаба является базовым классом для «LoRaConnection» и «SerialConnection» и является интерфейсом для взаимодействия с датчиками. Потомки данного класса реализовывают подключение и приём-передачу данных, определяя соответствующие методы.

# Лист 6. Схема БД и алгоритмы

Здесь показана разработанная схема базы данных PostgreSQL для хранения данных о состояниях парковочных мест на сервере. Для работы с картографическими данными используется расширение PostGIS. В целях оптимизации производительности на каждое поле участвующее в запросах были созданы соответствующие индексы, а также была применена денормолизация данных.

Ниже показан алгоритм выдачи парковок. Т.к. проектируемая система является высоконагруженной, карта была поделена на взаимно пересекающиеся квадраты, число которых ограничено. Размеры их определяются экспоненциальной функцией относительно масштаба. Таким образом, появляется возможность для кэширования данных.

# Лист 7. Тестирование

Серверное ПО для тестирования было развернуто на облаке Heroku. Для нагрузочного тестирования была развернута соответствующая инфраструктура на облачной платформе Google Cloud, схема сети которой показана здесь. Она состоит из балансировщика Nginx, который распределяет нагрузку между множеством бекэнд-серверов.

На этих графиках показана распределение нагрузки при падении одного из бекэнд-сервера.

По результатам нагрузочного тестирования было выяснено, что при заполненной БД с 13 тыс. записями RPS для алгоритма выдачи парковок составил 846 запросов в секунду.

Для обеспечения качества для дальнейшей разработки были написаны 60 автоматизированных тестов серверного ПО.

Также было проведено комплексное тестирование системы, в ходе которого было выяснено, что все требования к системе были выполнены.

Спасибо за внимание!

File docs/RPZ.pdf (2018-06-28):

Министерство образования и науки Российской Федерации Федеральное государственное бюджетное образовательное учреждение высшего образования
«Московский государственный технический университет имени Н.Э. Баумана (национальный исследовательский университет)» (МГТУ им. Н.Э. Баумана)

ФАКУЛЬТЕТ «Информатика и системы управления»

КАФЕДРА «Компьютерные системы и сети»

# РАСЧЕТНО-ПОЯСНИТЕЛЬНАЯ ЗАПИСКА

## К ВЫПУСКНОЙ КВАЛИФИКАЦИОННОЙ РАБОТЕ

## НА ТЕМУ:

## Система мониторинга парковочных мест

Студент ___ИУ6(81)___ | ________________ | ___А.В. Кирьяненко__
(Группа) | (Подпись, дата) | (И.О.Фамилия)
Руководитель ВКР | ________________ | _____А.Ю. Попов____
| (Подпись, дата) | (И.О.Фамилия)
Консультант | ________________ | ____________________
| (Подпись, дата) | (И.О.Фамилия)
Нормоконтролер | ________________ | _____Ю.И. Бауман____
| (Подпись, дата) | (И.О.Фамилия)

2018 г.

АННОТАЦИЯ

Дипломный проект посвящен разработке системы мониторинга парковочных мест. При

выполнении дипломного проекта, было проведено исследование IoT технологий в сфере

транспортной инфраструктуры. В рамках исследования был проведен анализ существующих

систем. На основании этого был спроектирован недорогой относительно конкурентов

аппаратно-программный прототип системы мониторинга парковочных мест. Основное

назначение системы заключается в определении наличия свободных парковочных мест и

отображении этих данных пользователям. Данная система позволит пользователям

(водителям) в режиме реального времени получать актуальную информацию о состоянии

парковочных мест.

ABSTRACT

The diploma project is devoted to the development of a monitoring system for parking places.

When carrying out the diploma project, was conducted research IoT technologies in the field of

transport infrastructure. As part of the research, existing systems were analyzed. Based on this, the

hardware-software prototype of a monitoring system for parking places was designed inexpensive

with respect to competitors. The main purpose of the system is to determine the availability of parking

spaces and display data for users. This system allows users (drivers) to receive up-to-date information

about status of parking places in real time.

РЕФЕРАТ

Записка 70 с., 30 рис., 18 табл., 7 лист., 15 источников, 6 прил.

МКРОКОТРОЛЛЕР, МК-СИСТЕМА, ОПРОС ДАТЧИКОВ, ЭЛЕКТРОПРИБОР,

БЕСПРОВОНАЯ СЕТЬ, МОНИТОРИНГ, ПАРКОВОЧНЫЕ МЕСТА, IOT, ИНТЕРНЕТ ВЕЩЕЙ, РАНСПОРТ, ТРАНСПОРТНАЯ ИНФРАСТРУКТУРА, MQTT

Разработан проект «Система мониторинга парковочных мест». Основное назначение

системы заключается в определении наличия свободных парковочных мест и отображении

этих данных пользователям. Данная система позволит пользователям (водителям) в режиме

реального времени получать актуальную информацию о состоянии парковочных мест. Данная

система состоит из: «МК-подсистемы регистрации свободных парковочных мест»,

вычислительного хаба и сервера.

«МК-подсистема регистрации свободных парковочных мест» фиксирует наличие

свободных парковочных мест. К микроконтроллеру подключаются сенсоры, каждый из

которых следит за своим парковочным местом. Через радиомодуль RFM95W информация о

состоянии парковочных мест (свободно / занято) передается в вычислительный хаб, для

последующей обработки. Реализована функция оплаты парковочного места, с отображением

на дисплее и подтверждением оплаты с клавиатуры.

Основное назначение вычислительного хаба, состоит в осуществлении взаимодействия

сервера, датчиков «МК-подсистема регистрации свободных парковочных мест» и других

компонентов системы.

Сервер осуществляет сбор данных с датчиков «МК-подсистема регистрации свободных

парковочных», управление всеми компонентами системы и вывод данных пользователям об

актуальном состоянии парковочных мест

Материалы по дипломному проекту представлены в виде графической части,

приложения с отлаженным программным кодом и расчетно-пояснительной записки.

ОПРЕДЕЛЕНИЯ, ОБОЗНАЧЕНИЯ И СОКРАЩЕНИЯ

БС – беспроводная сеть

БД – база данных

МК – микроконтроллер

МКПМ – модуль контроля парковочного места

МКПРСПМ – МК-подсистема регистрации свободных парковочных мест

ОС – операционная система

ПМ – парковочное место

ПО – программное обеспечение

ПЭВМ – персональная электронно-вычислительная машина

СМПМ – система мониторинга парковочных мест

СУБД – система управления базами данных

ТС – транспортное средство

УГО – условно графическое обозначение.

EEPROM – энергонезависимая перезаписываемая память

IoT – internet of things

ITS – intelligent transportation system

LoRa – Long Range, метод модуляции в беспроводных сетях

MQTT – message queue telemetry transport

PPCM – parking place control module

RoR – Ruby on Rails

СОДЕРЖАНИЕ

3.5.1.2 Радиочастотный приёмопередатчика RFM95W | 30
3.5.1.3 Расширитель портов PCF8574 | 31
3.5.1.4 Сравнение сенсоров присутствия автомобиля | 33
3.5.1.5 Ультразвуковой датчик расстояния HC-SR04 | 33
3.5.1.6 Часы реального времени DS3231SN | 35
3.5.2 Описание принципиальной схемы МКПМ | 36
3.5.3 Описание принципиальной схемы МКПРСПМ | 39
3.6 Расчет потребляемой мощности | 42
3.7 Описание разработанного программного обеспечения | 43
3.7.1 Описание схемы алгоритма | 43
3.7.2 Описание диаграммы классов | 47
3.8 Описание системы сообщений МКПРСПМ | 47
4 Разработка вычислительного хаба | 49
4.1 Анализ требований | 49
4.2 Подключение радиомодуля RFM95 | 50
4.3 Описание диаграммы классов | 50
4.4 Описание файла настроек | 51
5 Разработка сервера | 52
5.1 Анализ задания и выбор технологий | 52
5.2 Анализ способа хранения данных | 54
5.3 Формы интерфейса | 55
5.4 Алгоритм выдачи парковочных мест | 56
5.5 Автоматизация развертывания серверного ПО | 60
5.6 Балансировка нагрузки | 62
6 Обеспечение безопасности в СМПМ | 65
6.1 Обеспечение защищённой передачи данных между узлами | 65
6.2 Защита от межсайтового скриптинга (XSS) | 66
6.3 Защита от SQL-инъекции | 66
6.4 Защита от межсайтовой подделки запрос (CSRF) | 66
7 Тестирование СМПМ | 68
ЗАКЛЮЧЕНИЕ | 69
СПИСОК ИСПОЛЬЗОВАННЫХ ИСТОЧНИКОВ | 70
Приложение А. Техническое задание | 71
Приложение Б. Формы интерфейсов | 84

Приложение В. Тестирование системы.. | 99
Приложение Г. Руководство пользователя | 124
Приложение Д. Листинг программного кода | 135
Приложение Е. Графическая документация | 158

ВВЕДЕНИЕ

Дипломный проект «Система мониторинга парковочных мест» выполняется на

основании учебного плана кафедры ИУ6 с исходными данными, заданными в техническом

задании. Целью работы является проектирование системы мониторинга парковочных мест.

Формирование специализированных зон для стоянки автотранспорта началось почти

одновременно с появлением первых автомобилей. Число машин стремительно растет и для

решения возникнувшей проблемы ограниченности парковочных мест начали внедрять

современные технологии.

Основным направлением развития являются «умные» датчики парковки. Такие датчики

встраиваются в дорожное полотно на места парковок и отслеживают свободно ли

машиноместо над ними, отдавая данные в общую систему. Используя сеть таких датчиков,

формируется карта парковок, состояния которых рассылается пользователям на улицах с

помощью специальных табло или мобильного приложения.

Такая система позволяет решить следующие задачи:

- сокращение очередей и времени поиска свободного места на парковке;
- организация оптимального движения транспортных средств и пешеходов на

парковке;

- визуальное оповещение о количестве свободных мест в реальном времени с

помощью информационных табло или на веб-портале;

- оптимизация работы парковочного пространства.

В ходе данной работы была спроектирована «Система мониторинга парковочных

мест». Основное назначение системы заключается в определении наличия свободных

парковочных мест и отображении этих данных пользователям. Данная система позволит

пользователям (водителям) в режиме реального времени получать актуальную информацию о

состоянии парковочных мест. Данная система состоит из: «МК-подсистемы регистрации

свободных парковочных мест», вычислительного хаба и сервера.

### 1 Исследование IoT технологий в сфере транспортной

инфраструктуры

### 1.1 Интернет вещей

### 1.1.1 Базовые принципы IoT

Интернет вещей базируется на 3-х базовых принципах:

1) повсеместно распространенную коммуникационную инфраструктуру,
2) глобальную идентификацию любого объекта,
3) возможность любого объекта отправлять и принимать данные через персональную

сеть или через сеть Интернет.

Наиболее важными отличиями Интернета вещей от существующего интернета людей

являются:

- фокус на вещах, а не на человеке;
- существенно большее число подключенных объектов;
- существенно меньшие размеры объектов и невысокие скорости;
- фокус на считывании данных, а не на коммуникациях;
- потребность формирования новой инфраструктуры и новых стандартов.

Официальное определение Интернета вещей приведено в Рекомендации МСЭ-ТY.2060

[1], согласно которому IoT – глобальная инфраструктура информационного общества,

обеспечивающая передовые услуги за счет организации связи между вещами (физическими

или | виртуальными) | на | основе | существующих | и | развивающихся | совместимых

информационных и коммуникационных технологий. Под «вещами» (things) здесь понимается

физический объект или же виртуальный объект (например, мультимедийный контент или

прикладная программа), которые идентифицированы и связаны через сеть. МСЭ-Т использует

понятие «устройство» (device) – часть оборудования с обязательным требованием по

коммуникации и необязательным возможностью по сбору, обработке и хранению данных.

Любой узел сети интернет-вещей предоставляет свой сервис, оказывающий некую

услугу поставки данных. Также узел может принимать команды от других узлов. Таким

образом, все интернет-вещи могут взаимодействовать друг с другом и решать совместные

вычислительные задачи. [2]

### 1.1.2 Архитектура IoT

Архитектура интернет вещей во многом схожа с четырехслойной архитектурой NGN.

Она включает четыре функциональных уровня (Рисунок 1):

1) Приложения
2) Сервисный
3) Шлюзы и сети
4) Сеть датчиков

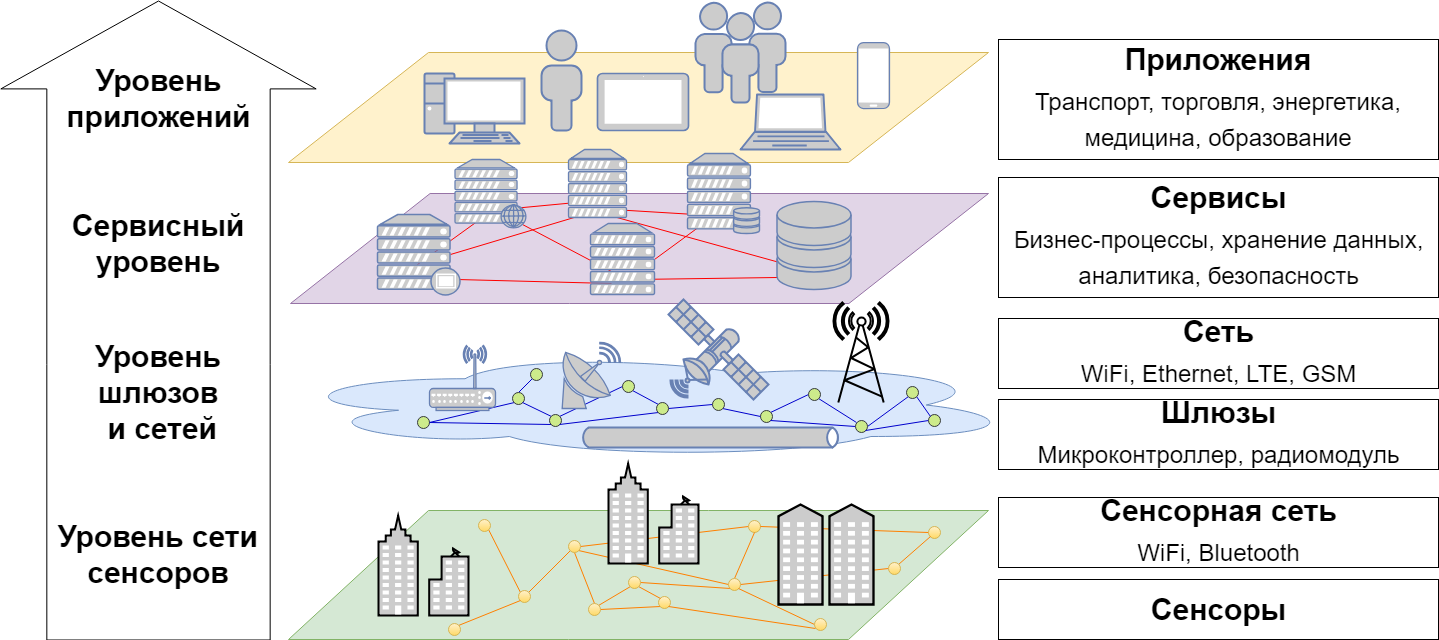
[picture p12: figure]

Рисунок 1 – Архитектура IoT

Далее снизу-вверх идёт описание каждого уровня IoT архитектуры [2].

1.1.2.1 Уровень сенсоров и сенсорных сетей.

Нижний уровень архитектуры IoT состоит из «умных» (smart) объектов,

интегрированных с сенсорами. Сенсоры обеспечивают сбор и обработку данных в реальном

времени. Существуют различные типы сенсоров для соответствующих задач, например, для

измерения температуры, давления, скорости, местоположения и др. Как правило, сенсоры

требуют соединения с агрегатором сенсоров (шлюзом), которые реализуются с

использованием локальной сети (LAN, Local Area Network), таких как Ethernet и Wi-Fi или

персональной | сети | (PAN, | Personal | Area | Network), | таких | как | Bluetooth | и

ультраширокополосной беспроводной связи на малых расстояниях (UWB, Ultra-Wide Band).

Для сенсоров, не требующих подключения к агрегатору, их связь с серверами/приложениями

может предоставляться с использованием глобальных беспроводных сетей WAN, таких как

GSM, GPRS и LTE.

Сенсоры с низким энергопотреблением и низкой скоростью передачи данных,

образуют беспроводные сенсорные сети (WSN, Wireless Sensor Network). WSN набирают все

большую популярность, т. к. они могут содержать огромное количество сенсоров и

охватывают большие площади.

1.1.2.2 Уровень шлюзов и сетей.

Огромный объем данных, создаваемых на нижнем уровне IoT множеством сенсоров,

требует надежной и высокопроизводительной проводной или беспроводной сетевой

инфраструктуры в качестве транспортной среды. Для реализации широкого спектра услуг и

приложений в IoT необходимо обеспечить совместную работу множества сетей различных

технологий и протоколов доступа. Эти сети должны обеспечивать требуемые значения

качества передачи информации, и прежде всего по задержке пропускной способности и

безопасности. Этот уровень состоит из сетевой инфраструктуры, реализуемой с помощью

интеграции разнородных сетей в единую сетевую платформу. Абстрактный сетевой уровень в

IoT позволяет через соответствующие шлюзы нескольким клиентам использовать ресурсы в

одной сети независимо и совместно без ущерба для конфиденциальности, безопасности и

производительности.

### 1.1.2.3 Сервисный уровень

Сервисный уровень содержит набор информационных услуг для автоматизации

технологических и бизнес операции в IoT: поддержка операционной и бизнес деятельности

различной | аналитической | обработки | информации, | хранения данных, | обеспечения
информационной | безопасности, | управления | бизнес-правилами, | управления | бизнес-

процессами и др.

### 1.1.2.4 Уровень приложений

На верхнем уровне архитектуры IoT существуют различные типы приложений для

соответствующих сфер деятельности (транспорт, торговля, энергетика, медицина,

образование и др.).

### 1.2 Протокол MQTT

MQTT (Message Queue Telemetry Transport) – упрощенный протокол сетевого уровня

для обмена сообщениями между устройствами. Этот протокол работает поверх стека TCP/IP

и разработан для преодоления проблем, связанных с подключением быстро растущего числа

датчиков, микрокомпьютеров, приводов, телефонов, планшетов. В настоящее время MQTT

является наиболее распространенным протоколом для организации IoT инфраструктуры. [3]

MQTT организован по принципу издатель/подписчик (publisher/subscriber): издатель

(устройства типа publishers) является отправителем сообщения, которое публикуется в

централизованном сервисе (брокере сообщений), а подписчик (устройства типа subscriber)

получает сообщение из брокера. Для использования брокера MQTT необходимо пройти

процедуру подписки на определенные темы публикуемых сообщений (Рисунок 2).

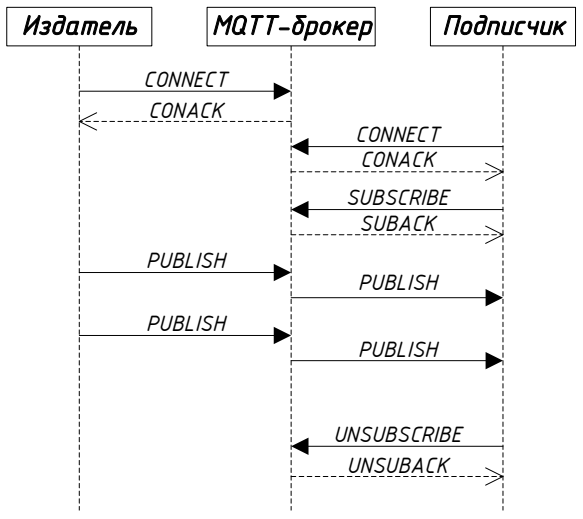
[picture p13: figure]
Издатель; MQTT-брокер; Подписчик; CONNECT; CONACK; CONNECT CONACK; SUBSCRIBE SUBACK; PUBLISH; UNSUBSCRIBE; UNSUBACK

Рисунок 2 – Диаграмма последовательностей MQTT протокола

В процессе работы издатель передает данные с указанной темой сообщения, которое

сопоставляется брокером с темами подписчиков. В случае совпадения, каждый из них

получает экземпляр данных.

Таблица 1 – Сравнение протоколов MQTT и HTTPS

| 3G | WiFi
HTTP | MQTT | HTTP | MQTT
Приём | Сообщения / час | 1,708 | 160,278 | 3,628 | 263,314
| % батареи / сообщение | 0.01709 | 0.0001 | 0,00095 | 0,00002
Отдача | Сообщения / час | 1,926 | 21,685 | 5,229 | 23,184
| % батареи / сообщение | 0,00975 | 0,00082 | 0,00104 | 0,00016

Небольшие накладные расходы, связанные с хорошо продуманным форматом

заголовков, позволяют эффективно применять этот протокол для решений Интернета вещей.

В таблице 1 показаны результаты экспериментального сравнения протоколов MQTT и HTTP

[3]. Эксперименты показывают, что данный протокол обладает небольшими накладными

расходами на стороне устройства, что позволяет сократить расход энергии аккумуляторной

батареи и увеличивает количество передаваемых в единицу времени сообщений.

### 1.3 Архитектора сетей LoRa

Модуляция LoRa [4] определяет физический уровень, который может использоваться в

сетях с различной архитектурой – mesh-сети, звезда, точка-точка и другие. Благодаря своей

высокой чувствительности (-148dbm) LoRa идеально подходит к устройствам с требованиями

низкого потребления электроэнергии и высокой устойчивости связи на больших расстояниях

до 20 км.

LoRaWAN – это открытый протокол для высокоёмких (до 1 000 000 устройств в одной

сети) сетей с большим радиусом действия и низким энергопотреблением. Сеть LoRaWAN

состоит из следующих элементов (Рисунок 3): конечное устройство, шлюзы, сетевой сервер и

сервер приложений.

Конечное устройство – предназначено для осуществления управляющих или

измерительных функций. Содержит набор необходимых датчиков и управляющих элементов.

Шлюз – устройство, принимающее данные от конечных устройств с помощью

радиоканала и передающее их в транзитную сеть (например, Ethernet или WiFi). Шлюз и

конечные устройства образуют сетевую топологию типа звезда. Обычно данное устройство

содержит многоканальные приёмопередатчики для обработки сигналов в нескольких каналах

одновременно или даже, нескольких сигналов в одном канале. Соответственно, несколько

таких устройств обеспечивает зону радиопокрытия сети и двунаправленную передачу данных

между конечными устройствами и сервером.

Сетевой сервер - предназначен для управления сетью.

Сервер приложений - может удаленно контролировать работу конечных устройств и

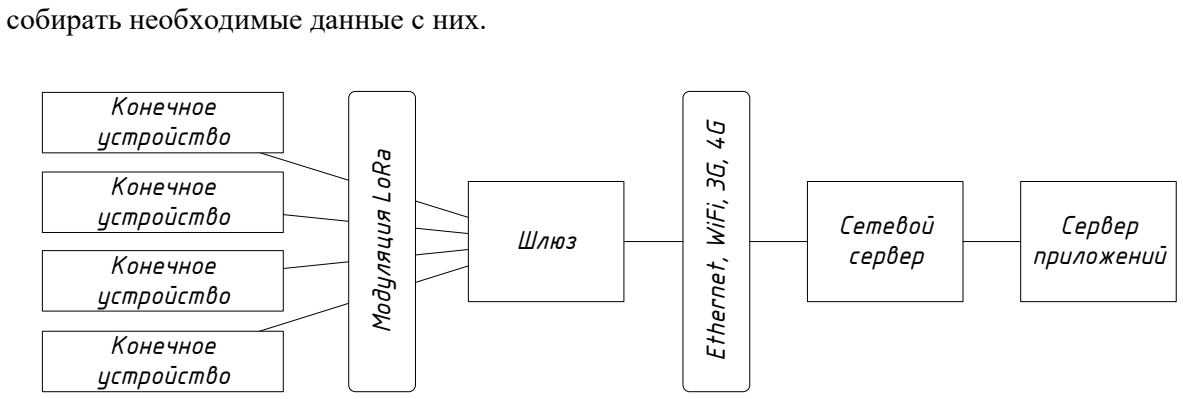
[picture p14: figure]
собирать необходимые данные с них.; Ethernet, WiFi, 3G, 4G; Сетевой сервер; Сервер приложений; Конечное устройство; Конечное; устройство; Модуляция LoRa; Шлюз

Рисунок 3 – Архитектура сети LoRaWAN

Преимущества LoRaWAN:

- Большая дальность передачи радиосигнала достигает 10 — 15 км.
- Низкое энергопотребление у конечных устройств, благодаря минимальным

затратам энергии на передачу небольшого пакета данных.

- Высокая проникающая способность радиосигнала в городской застройке.
- Высокая масштабируемость сети на больших территориях.
- Отсутствие необходимости получения частотного разрешения и платы за

радиочастотный спектр, из-за использования нелицензируемых частот (ISM band).

Недостатки LoRaWAN:

- Низкая пропускная способность, составляет от нескольких сотен бит/с до

нескольких десятков кбит/с.

- Задержка передачи данных от датчика до конечного приложения, связанная с

временем передачи радиосигнала, может достигать от нескольких секунд до

нескольких десятков секунд.

- Отсутствие единого стандарта, который определяет физический слой и управление

доступом к среде для беспроводных LPWAN-сетей.

- Риски зашумленности спектра нелицензированного диапазона частот.
- Проприетарная технология модуляции LoRa, «закрытая» патентом Semetech.
- Ограничение мощности сигнала.

### 1.4 Умный транспорт

Интеллектуальные транспортные системы ITS на основе IoT технологий дают

возможность | реализовывать | автоматическое | взаимодействие | между | объектами

инфраструктуры и ТС V2I (Vehicle to Infrastructure) или между различными ТС V2V (Vehicle

to Vehicle). Системы V2V реализовывают обмен данными по беспроводной связи между ТС

на дистанции до нескольких сот метров. Системы V2I реализовывают обмен между ТС и

центрами управления дорожным движением. | Информация, переданная | объектами

инфраструктуры, отправляется в общую систему и передаётся близлежащим ТС. Технологии

обеих групп могут существенно повысить безопасность и эффективность транспорта.

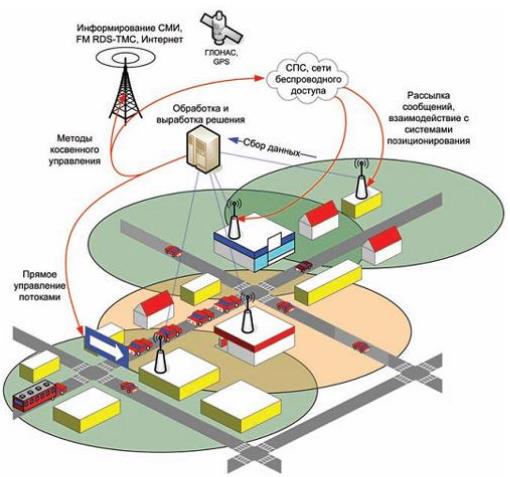
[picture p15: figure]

Рисунок 4 – Система интеллектуального управления транспортом

Как пример использования IoT технологий в населенных пунктах можно привести

систему управления авто трафиком (Рисунок 4), которая, анализируя пропускную способность

дорог, самостоятельно управляет трафиком с помощью перенастройки светофоров и в

реальном времени публикует информацию о текущем состоянии, которая доступна другим

устройствам и сервисам, например, ГЛОНАСС/GPS-навигатор, мобильный телефон или

специализированные веб-сайты.

Применение IoT технологий в транспортной сфере позволяет отслеживать оповещения

об опасных ситуациях, а также перенаправлять маршруты движения в режиме реального

времени. Помимо этого, благодаря установленным на улицах датчикам появится возможность

публикации информации об загруженности дорог и автострад. Например, среди таких

«умных» транспортных систем IoT можно упомянуть:

- системы предотвращения столкновений;
- системы «боковой поддержки», указывающие водителю на пересечение дорожных

полос или опасные маневры;

- системы ночного видения;
- системы автоматического управления автомобилем и движения в группах

автомобилей

- системы мониторинга авто трафика
- системы мониторинга парковочных мест
- системы, контролирующие состояние водителя (например, не позволяющие ему

заснуть);

- системы превентивного реагирования на аварийную ситуацию (в частности,
системы, | которые | осуществляют | предварительное | натягивание | ремней

безопасности перед неизбежным столкновением).

Система информирования водителей при помощи встраиваемых в машины устройств

VICS (Vehicle Information and Communication System) [5] собирает информацию с сенсоров,

установленных на объектах дорожной инфраструктуры (дорожном полотне, камерах

наблюдения и пр.), с использованием «машин-зондов» (мобильных пунктов наблюдения за

дорожным движением), а также с уже установленных бортовых систем, собирающие данные

о скорости движения транспортного потока. Эти данные системой VICS обрабатывается и

рассылается по бортовым навигационным системам. Пользователи системы могут получать

информацию в различных видах - в виде текста, простой графики, карт. Бортовые системы

динамически обрабатывают данные и предлагают водителю оптимальный маршрут.

### 1.5 Обзор существующих СМПМ

Система мониторинга парковочных мест предоставляет в режиме реального времени

все необходимые данные о работоспособности парковок, наличии свободных мест участникам

дорожного движения (водителям и операторам), позволяет организовать контроль времени

парковки автомобилей. В данном направлении сейчас активно ведутся разработки. Например,

сейчас работают такие сервисы как: «Яндекс. Парковки» и «Парковки Москвы». Рассмотри их

более подробно.

«Яндекс. Парковки» [6] – это мобильное приложение, которое показывает на карте,

свободные парковочные места, помогает построить удобный маршрут до ближайшего из них

и узнать о степени загруженности парковок. Также имеется возможность оплаты на городские

и некоторые коммерческие парковки. Данный сервис работает только на территории Москвы.

«Московский паркинг» [7] – это сервис, который содержит базу парковок при торговых

центрах, вокзалах и аэропортах, а также платных и бесплатных стоянок Москвы. Проект

призван справиться с проблемой «хаотичного паркования» на улицах Москвы и создать

возможность для комфортного передвижения пешеходов, средств общественного транспорта

и автомобилей. Имеется возможность оплаты парковки через мобильное приложение.

Как правило СМПМ содержит подсистему фотовидеофиксации ТС и подсистему

мониторинга занятости парковочного пространства, при этом система также содержит

центральный сервер, отвечающий за синхронизацию и обрабатывание данных от обеих

подсистем. Подсистема фотовидеофиксации включает, как минимум, одну видеокамеру,

модуль памяти и сервер обработки фотовидеоинформации, соединенный каналами передачи

данных с центральным сервером системы. А подсистема мониторинга занятости парковочного

пространства включает минимум один детектор занятости парковочного места и сервер

мониторинга занятости ПМ, соединенный каналами передачи данных с центральным

сервером системы. [8]

Известна система определения занятости парковочных мест (патент RU 103120 U1,

МПК: E04H 6/00) [9], включающая по меньшей мере одну камеру, установленную рядом с

парковочными местами и средство отображения информации о занятости парковочных мест.

Отличается тем, что в качестве камеры используют стереокамеру, установленную с

возможностью получения стереоизображения зоны ее наблюдения, включающей несколько

парковочных мест. При этом камера снабжена вычислительным модулем, выполненным с

возможностью определения занятости парковочных мест по стереоизображению указанной

зоны наблюдения и передачи сигнала на средство отображения информации о занятости

парковочных мест.

Минусом системы является ее ограниченная функциональность и потребность в

установки в зоне парковки большого количества стереокамер, что существенно увеличивает

стоимость установки и обслуживания, кроме того потребуются дополнительные технические

средства для обрабатывания огромного объема видеоинформации от множества стереокамер.

Это делает низкоэффективным использование такой системы в масштабах крупного города с

большим количеством парковочных мест.

### 1.6 Выбор сенсора присутствия автомобиля

Датчик присутствия — электронный прибор, регистрирующий бесконтактными

методами объекты определенного класса на территории своего контроля. В зависимости от

результатов регистрации он может коммутировать электрические импульсы, по сигналам

которых другие устройства выполняют различного рода действия. [10]

По принципу действия различают датчики присутствия:

- ультразвуковые: барьерные, диффузионные;
- фотоэлектрические;
- емкостные;

- датчики нагрузки;
- комбинированные.

Рассмотрим подробно каждый из видов, определим области их применения, оценим

достоинства и недостатки.

### 1.6.1 Ультразвуковые датчики присутствия

Ультразвуковые сенсоры присутствия испускают и принимают волны, не

улавливаемые человеческим ухом (частотой порядка 200 кГц).

Возможны два режима работы:

- Барьерный: между датчиками, расположенными друг напротив друга, проходит

ультразвуковая волна. Она не попадет в приемник, если в зоне действия появится

посторонний предмет (барьер).

- Диффузионный: с использованием датчика, который испускает волну, а затем

улавливает её, отраженную от объекта, оказавшегося на пути луча.

В обоих случаях при появлении постороннего предмета коммутируется сигнал,

передаваемый на исполняющие устройства.

Преимущества:

- обнаружение прозрачных объектов;
- невосприимчивость к световым вспышкам и бликам;
- работоспособность в сложных условиях (туман, пыль, пар).

Недостатки:

- низкая дальность (верхний порог) фиксации;
- ненадежность регистрации объектов из мягких материалов;
- наличие “слепой зоны” (нижнего порога обнаружения).
Примеры | использования | ультразвуковых | датчиков: | парковочные | системы

современных автомобилей, подсчет количества единиц готовой продукции на конвейере.

### 1.6.2 Фотоэлектрические датчики присутствия

Фотоэлектрические датчики работают по схожей с ультразвуковой схемы. Отличие

заключается в использовании оптического излучения вместо ультразвукового.

Преимущества:

- высокий порог фиксации (до 150 метров у барьерных датчиков);

- быстродействие;
- отсутствие слепой зоны.

Недостатки:

- невозможность регистрации прозрачных объектов;
- сбои в условиях тумана, пыли, при проявлении световых вспышек и бликов.

Фотоэлектрические датчики используются для контроля за упаковочными и

производственными | линиями, | проверки | уровня | наполнения | прозрачной | тары,

предотвращения несанкционированного доступа на закрытые территории, остановки

промышленного оборудования при попадании человека в опасные зоны.

### 1.6.3 Ёмкостные датчики присутствия

Конструктивно представляют собой цилиндрические или плоскопараллельные

конденсаторы. При появлении объекта в зоне действия изменяется их диэлектрическая

проницаемость, а значит и емкость, что вызывает срабатывание.

Преимущества:

- низкая инерционность;
- высокий порог чувствительности.

Недостаток — вероятность сбоев в работе под влиянием внешних электромагнитных

полей.

Приборы применяются для контроля за заполнением резервуаров жидкостями и

сыпучими материалами, как счетчики единиц готовой продукции и элементы противоугонных

систем автомобилей.

### 1.6.4 Датчики нагрузки

Это конвертеры, преобразовывающие механическое усилие в электрический ток.

Конструктивно датчик представляет собой тензорезистор в виде тонкой проволоки,

зигзагообразно закрепленный на эластичной подложке. Как упругий элемент используется

ткань, резина, полимерная пленка. Под действием силы проводник деформируется,

сопротивление его меняется, что генерирует электрический сигнал.

Преимущества:

- малая толщина, обеспечивающая скрытую установку;
- легкость монтажа.

Недостатки:

- необходимость использования усилителя сигнала;
- подверженность многократно повторяющимся механическим нагрузкам, что

приводит к выходу из строя;

- снижение чувствительности при перепадах температур

### 1.7 Выводы

Согласно проведенному исследованию IoT технологии идеально подходят для

реализаций в проектах в сфере транспортной инфраструктуры. Это позволит:

- развить новые подходы по планированию и управлению транспортных потоков;
- повысить эффективность системы хранения ТС в городе;
- анализировать огромные массивы данных, и на их основании делать города более

удобными, экономичными и прекрасными.

Внедрение высоких технологий в паркинг городов поможет:

- сократить очередь и время поиска свободного места на парковке;
- организации оптимального движения ТС и пешеходов;
- оптимизации работы парковочного пространства.

Были рассмотрены существующие СМПМ (п.п. 1.5.), основными недостатками

которых являются: ограниченная область действия, высокая стоимость внедрения.

На основании этого принято решение проектирования системы мониторинга

парковочных мест. Данная система должна состоять из «МК-подсистемы регистрации

свободных парковочных мест», вычислительного хаба и центрального сервера.

### 2 Анализ требований к СМПМ

### 2.1 Разработка диаграммы вариантов использований

Основное назначение СМПМ заключается в определении наличия свободных

парковочных мест и отображении этих данных пользователям. Данная система позволяет

пользователям (водителям) в режиме реального времени получать актуальную информацию о

состоянии парковочных мест.

Для уточнения требований к функционированию системы необходимо определить

варианты её использования при помощи диаграммы вариантов использования. Система взаимодействует с двумя видами действующих лиц: пользователь (водитель) и владелец

стоянки. Соответствующие диаграммы для этих лиц показаны на рисунках 5 и 6.

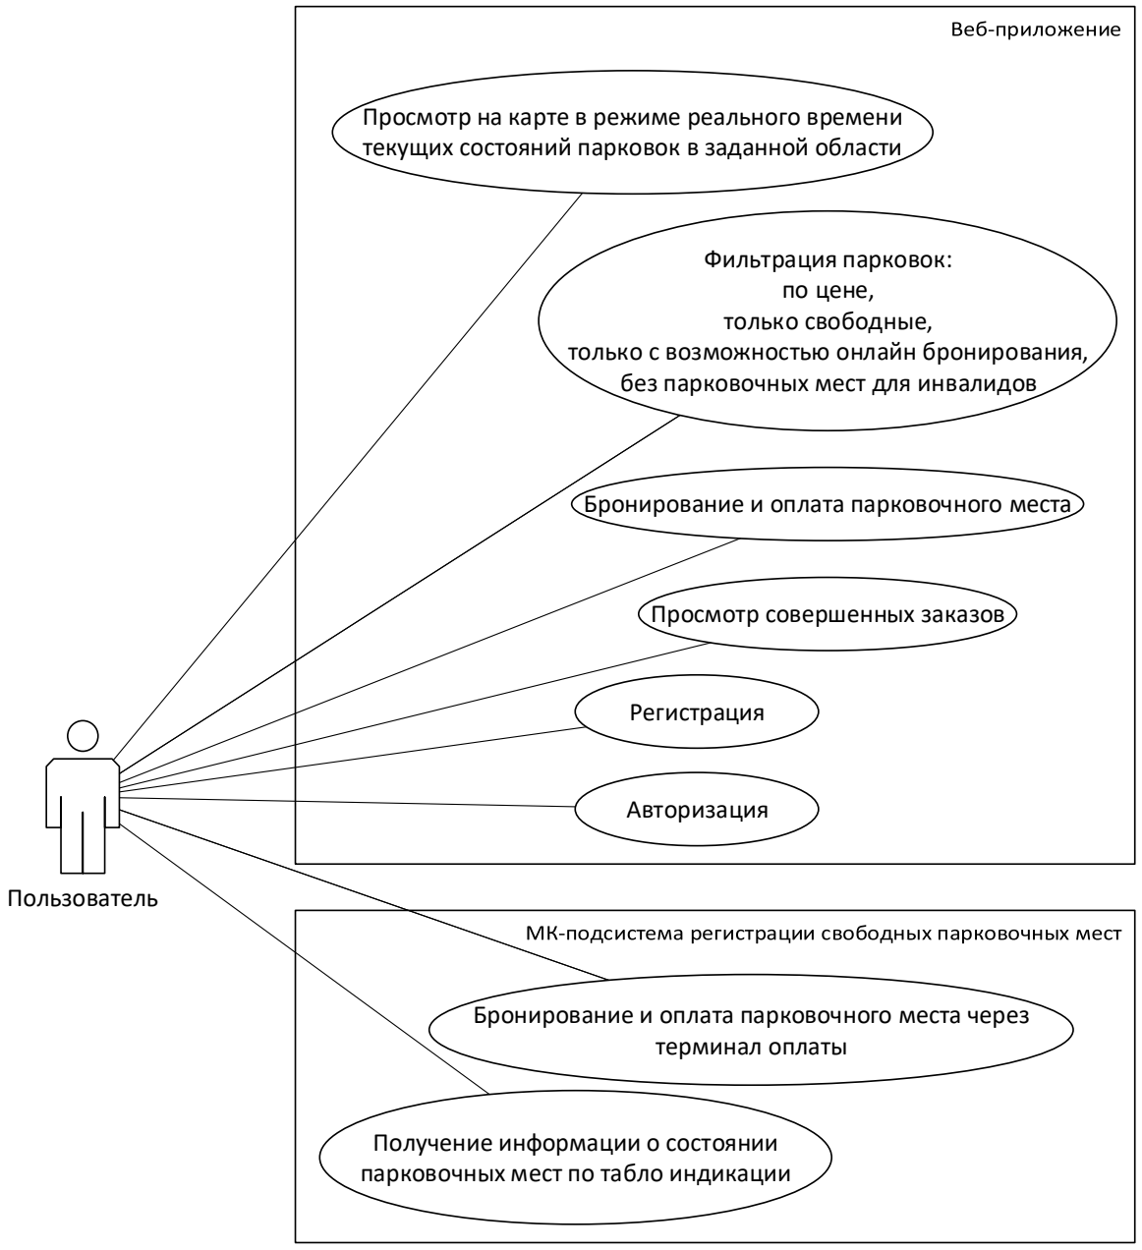
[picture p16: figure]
Пользователь; Фильтрация парковок: по цене, только свободные, только с возможностью онлайн бронирования, без парковочных мест для инвалидов; Бронирование и оплата парковочного места; Регистрация; Авторизация; Просмотр совершенных заказов; терминал оплаты; Получение информации о состоянии парковочных мест по табло индикации

Просмотр на карте в режиме реального времени текущих состояний парковок в заданной области

Бронирование и оплата парковочного места через

Рисунок 5 – Диаграмма вариантов использований для пользователя

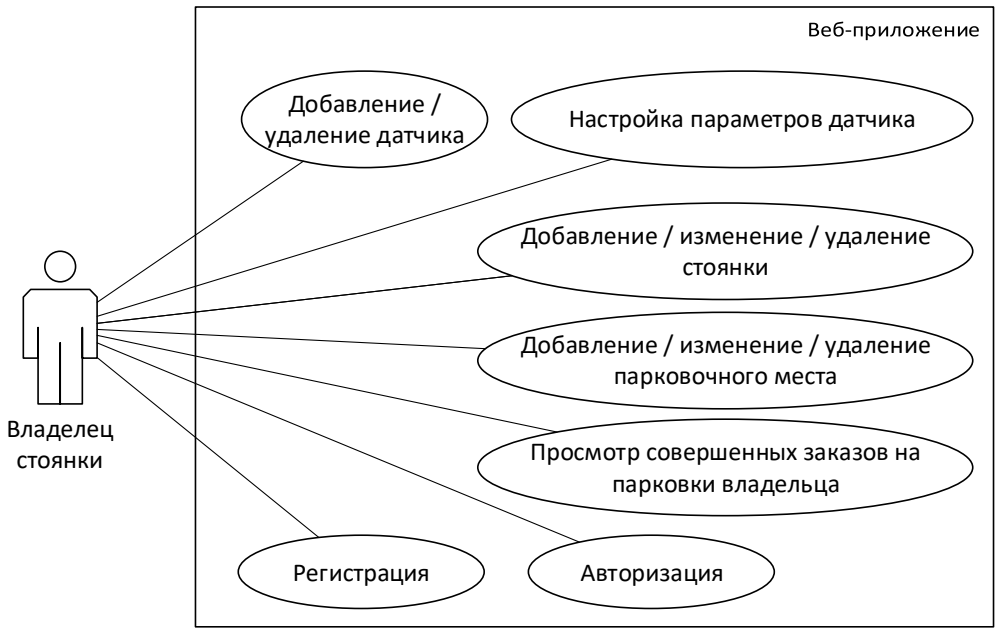
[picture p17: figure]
Владелец стоянки; Добавление / удаление датчика; Добавление / изменение / удаление стоянки; Добавление / изменение / удаление парковочного места; Регистрация; Авторизация; Просмотр совершенных заказов на парковки владельца; Настройка параметров датчика

Рисунок 6 – Диаграмма вариантов использований для владельца стоянки

### 2.2 Описание и структура СМПМ

На рисунке 7 представлена структурная схема системы мониторинга парковочных

мест. Система мониторинга парковочных мест состоит из следующих блоков:

- МК-подсистема регистрирования свободных парковочных мест (МКПРСПМ),
- вычислительный хаб,
- сервер.

Датчики МКПРСПМ служат для фиксации наличия свободных парковочных мест и

оплаты. МКПРСПМ формирует пакеты с информацией о свободных парковочных местах и

передаёт их на вычислительный хаб по беспроводной сети LoRaWAN (Описание системы

сообщений МКПРСПМ п.п. 3.8.).

Вычислительный хаб, представленный в виде микрокомпьютера Raspberry Pi,

необходим для осуществления взаимодействия сервера, МКПРСПМ и других компонентов

системы. Хаб выполняет приём пакетов, переданных с МКПРСПМ, формирует пакеты MQTT

и передает их на сервер по сети интернет. Обратно от сервера хаб получает команды

управления МКПРСПМ, которые также передаются по сети LoRaWAN, на МК-подсистемы.

Пользователь с мобильного устройства на платформе Android с установленным

приложением сможет посмотреть карту с указанием местоположений свободных парковочных

мест. Мобильное приложение получает данные о парковочных местах с помощью API-

сервисов, предоставляемых сервером.

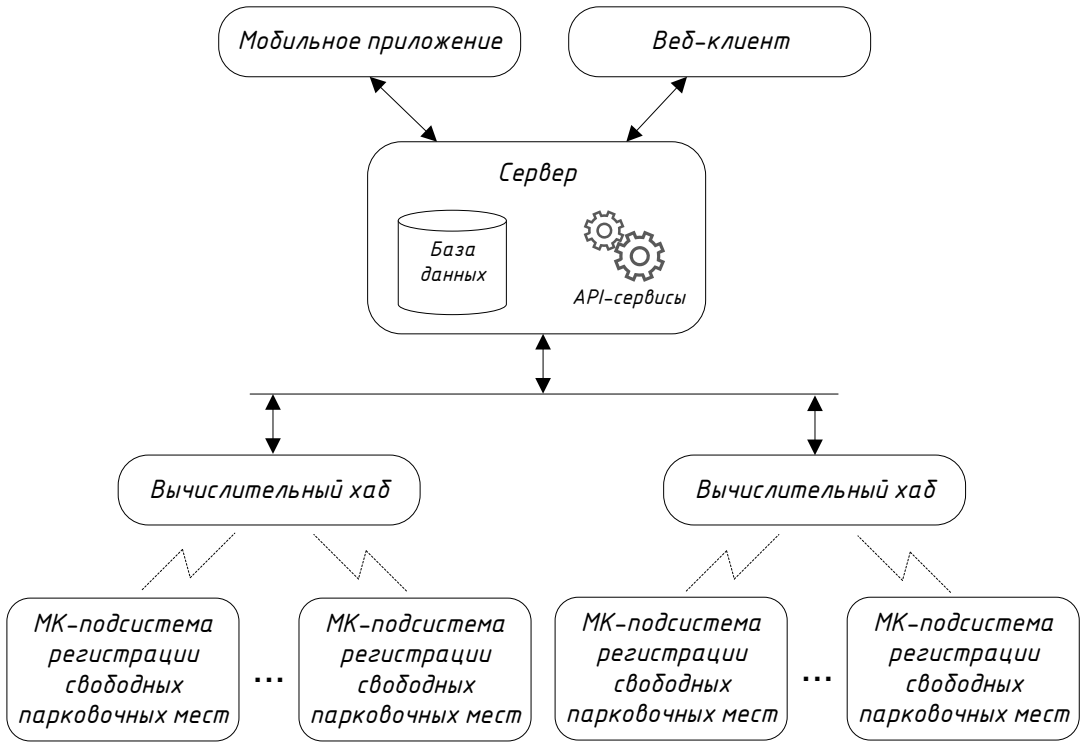
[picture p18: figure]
Мобильное приложение; Веб-клиент; База данных; Сервер; API-сервисы; Вычислительный хаб; МК-подсистема регистрации свободных парковочных мест

Рисунок 7 – Структурная схема системы мониторинга парковочных мест

Веб-клиент, предоставляет карту со свободными парковочными местами. Также для

владельцев стоянок, предоставляется возможность для управления за парковочными местами:

изменение тарифного плана, настройка параметров МКПСРСПМ.

### 2.3 Описание функциональной схемы СМПМ

На рисунке 8 показана функциональная схема СМПМ. Система работает следующим

образом. В МКПРСПМ сигнал о состоянии парковочного места приходит от сенсора

присутствия автомобиля, после чего МК ATMEGA328 формирует пакеты и отправляет их

через радиомодуль RFM95 по сети LoRaWAN на вычислительный хаб. Также по сети

LoRaWAN МКРСППМ может принять команды для изменения настроечных параметров.

Вычислительный хаб служит для осуществления взаимодействия сервера, МКПРСПМ

и других компонентов системы. Хаб через радиомодуль RFM95 принимает пакеты,

переданные с МКПРСПМ, формирует MQTT пакеты и передает их на сервер и на другие

компоненты системы. Данные внутри MQTT пакетов передаются в формате JSON. Обратно

от сервера хаб получает команды управления МКПРСПМ, которые также передаются по сети

LoRaWAN, на МК-подсистемы. ПО для вычислительного хаба написано с использованием

фреймворка Qt. На вычислительном хабе может быть установлено серверное ПО, тем самым

хаб сформирует локальную сеть, внутри которой сможет работать как сервер. MQTT – это легкий протокол для передачи данных, который идеально подходит для взаимодействия

большого количества IoT устройств. Таким образом, к вычислительному хабу возможно

подключить множество других устройств (например, табло индикации количества свободных

парковочных мест), позволяющие взаимодействовать по протоколу MQTT.

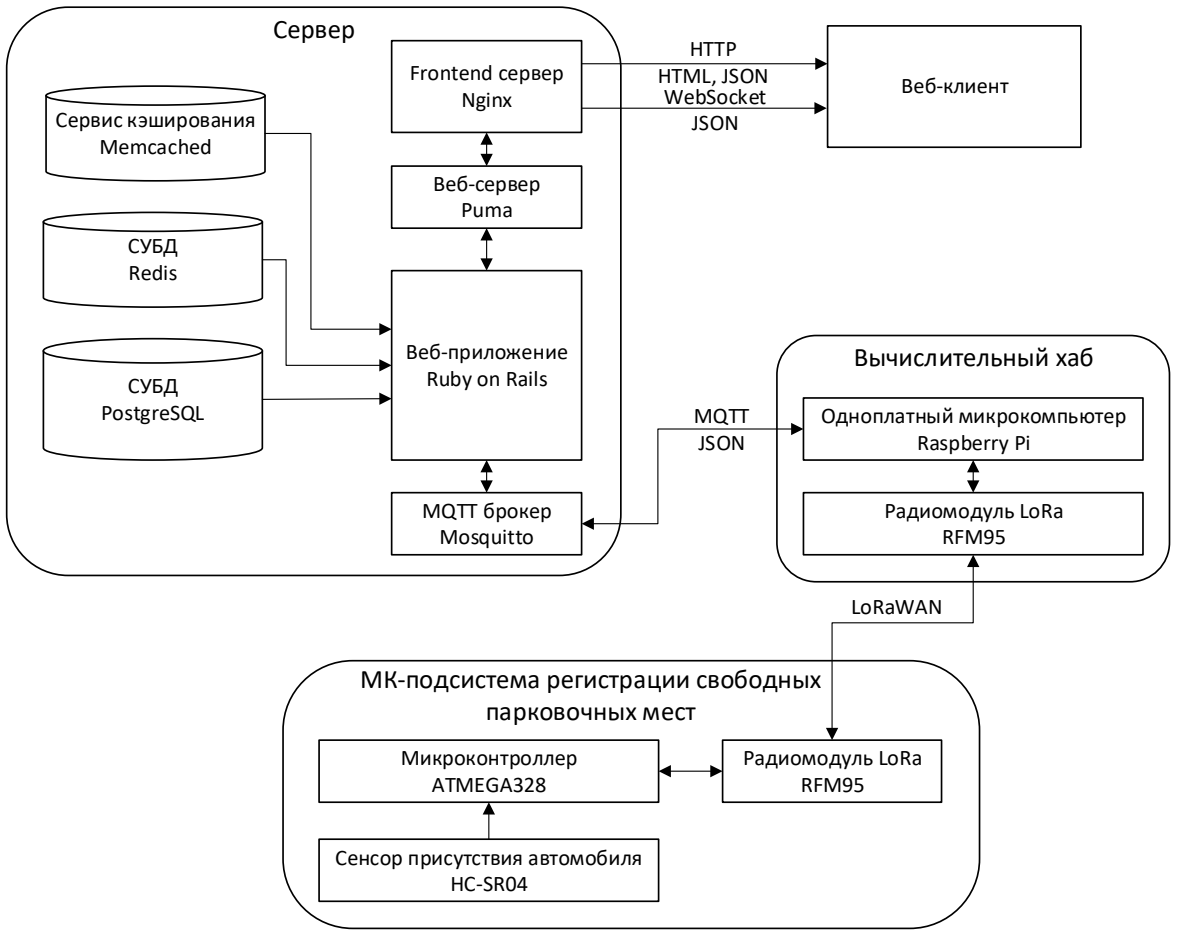
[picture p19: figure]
Frontend сервер Nginx; Веб-сервер Puma; Веб-приложение Ruby on Rails СУБД; PostgreSQL; СУБД Redis; Сервис кэширования Memcached; MQTT брокер Mosquitto; Веб-клиент; HTTP HTML, JSON WebSocket JSON; Сервер; Одноплатный микрокомпьютер Raspberry Pi; Радиомодуль LoRa RFM95; Вычислительный хаб; MQTT JSON; Микроконтроллер ATMEGA328; Сенсор присутствия автомобиля HC-SR04; МК-подсистема регистрации свободных парковочных мест; LoRaWAN

Рисунок 8 – Функциональная схема СМПМ

Сервер взаимодействует с вычислительным хабом по протоколу MQTT. Для этого на

сервере установлен MQTT брокер Mosquitto. Приложение на фреймворке Ruby on Rails

принимает данные о состоянии ПМ через MQTT брокер и сохраняет в БД PostgreSQL. Также

сервер может управлять датчиками МКПРСПМ, отправляя команды по протоколу MQTT на

вычислительный хаб. Сервер Nginx является Frontend сервером, он осуществляет раздачу

статики и проксирование запросов на веб-сервер Puma, который уже взаимодействует с веб-

приложением на Ruby on Rails. Веб-приложение для кэширования использует сервис

кэширования Memcached. Для работы Action Cable, который осуществляет взаимодействие с

веб-клиентами по WebSocket, необходима «key - value» хранилище данных Redis. Чтобы веб-

клиент в режиме реального времени получал данные о состоянии парковочных мест, данные

о парковочных местах в формате JSON периодически отправляются по протоколу WebSocket.

### 3 Разработка МКПРСПМ

### 3.1 Анализ требований к разрабатываемому устройству

Согласно | техническому | заданию, | необходимо | разработать | МК-подсистему

регистрации свободных парковочных мест, выполненный на основе микроконтроллера

ATMEGA328. Данный регистратор фиксирует наличие свободных парковочных мест. К

микроконтроллеру подключаются сенсоры, каждый из которых следит за своим парковочным

местом. Через радиомодуль информация о состоянии парковочных мест (свободно / занято)

передается в вычислительный хаб Raspberry Pi для последующей обработки. Должна быть

реализована функция оплаты парковочного места.

Проанализировав задание, можно заключить, что разрабатываемая система должна

представлять собой аппаратно-программный модуль, содержащий непосредственно

микроконтроллер ATMEGA328, запрограммированный исполняющей программой. К

микроконтроллеру через расширители портов PCF8574 подключаются сенсоры, следящие за

парковочными местами. Также, расширитель портов PCF8574 используется для вывода

информации о состоянии закрепленного за ним парковочного места. Для коммуникации с

вычислительным хабом Raspberry Pi используется радиомодуль LoRa. Для реализации

функции оплаты парковочного места используется терминал оплаты, состоящий из дисплея и

клавиатуры. Работа с терминалом построена в диалоговом режиме.

### 3.2 Разработка структурной схемы МКПРСПМ

МКПРСПМ служит для фиксации наличия свободных парковочных мест и оплаты.

Данная подсистема состоит из следующих элементов (Рисунок 9):

- микроконтроллер ATMEGA328,
- модули контроля парковочного места (МКПМ),
- терминал оплаты,
- радиомодуль RFM95W.
- Часы реального времени DS3231

Каждое парковочное место оборудовано МКПМ, состоящем из сенсора, который

определяет свободно ли парковочное место, и расширителем портов PCF8574, для

подсоединения сенсора к МК. Выводами «Free» и «Booked» служат для отображения

информации о текущем состоянии данного парковочного места. Логическая «1» на выводе

«Free» означает, что данное парковочное место свободно, а «0» – занято. Логическая «1» на

выводе «Booked» означает, что данное место забронировано, а «0» – нет.

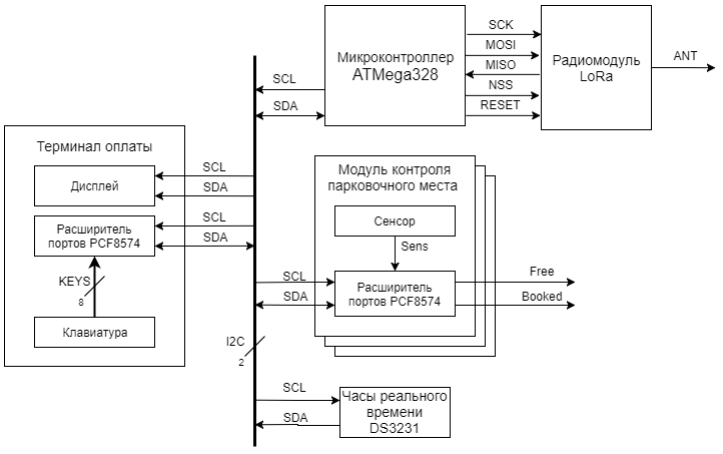
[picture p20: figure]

Рисунок 9 – Структурная схема МКПРСПМ

Микроконтроллер ATMEGA328 с помощью модулей МКПМ считывает информацию о

состоянии парковочных мест и устанавливает на индикаторах МКПМ соответствующие

состояния. Далее микроконтроллер формирует пакеты с информацией о свободных

парковочных местах для передачи на вычислительный хаб по беспроводной сети LoRaWAN.

Радиомодуль LoRa осуществляет приём / передачу данных по сети LoRaWAN. Данный

модуль подключён к МК по шине SPI.

Терминал оплаты осуществляет оплату парковочного места по заданному тарифу. Он

состоит из дисплея, для отображения информации для пользователя, клавиатуры для ввода

данных и расширителем портов PCF8574 для соединения клавиатуры с МК по шине I2C.

Часы | реального | времени | DS3231 | необходимы | для | постоянного | учёта

хронометрических данных (дата, время) на микроконтроллере. Это позволяет изменять тариф

для оплаты парковочного места в зависимости от времени суток. А также позволяет

отображать текущее время на дисплее. Установка заданного времени на часах происходит при

приходе соответствующего сообщения «Изменить время» (Описание системы сообщений

МКПРСПМ п.п. 3.8.).

### 3.3 Разработка функциональной схемы МКПМ

Каждое парковочное место оборудованы МКПМ, который определяет свободно ли

данное парковочное место и выводит информацию о состоянии этого парковочного места.

Была разработана функциональная схема МКПМ, представленная на рисунке Е.5.

Данная схема описывает функциональный блок «PPCM» (Рисунок 10), который используется

при построении функциональной схемы МКПРСПМ (п.п. 3.4.).

Free
Booked

SDA
SCL

PPCM
Рисунок 10 – УГО функционального блока PPCM

Ниже на рисунке 11, показана функциональная схема МКПМ.

P0

P1
P2

SDA
SCL

Sens

PCF8574

Sensor
Free
Booked

SDA
SCL

Рисунок 11 – Функциональная схема МКПМ

Схема состоит из двух блоков:

- Сенсор, который определяет свободно ли данное парковочное место.
- Расширитель портов PCF8574, осуществляющий связь сенсора с МК, а также через

выводы P1 и P2 выводит информацию о состоянии парковочного места.

Расширитель подключен к МК по шине I2C. К выводу P0 подключается сенсор.

Выход P1 выводит сигнал «Free», логическая «1» которого означает, что данное

парковочное место свободно, а «0» – занято. Выход P2 выводит сигнал «Booked»,

логическая «1» которого означает, что данное парковочное место забронировано, а

«0» – нет.

### 3.4 Разработка функциональной схемы МКПРСПМ

Исходя из результатов анализа требований (п.п. 3.1.), можно выделить следующие

функциональные блоки МКПРСПМ:

- микроконтроллер ATMEGA328;
- радиомодуль LoRa BEE;
- USB-UART драйвер ATMEGA16U2
- модулей МКПМ (PPCM) в количестве до 15 штук, устанавливаемых на каждое

парковочное место;

- клавиатура;
- расширитель портов PCF8574 для подключения клавиатуры к микроконтроллеру;
- дисплей;
- часы реального времени DS3231.

В результате проведенного анализа, была спроектирована функциональная схема

взаимодействия элементов, приведенная на рисунке Е.6.

Разберем структуру взаимодействия элементов на функциональной схеме. На каждое

парковочное место устанавливается МКПМ. Микроконтроллер ATMEGA328 с помощью

модулей МКПМ, подключенных к МК по шине I2C, считывает информацию о состоянии

парковочных мест. После обработки данных, микроконтроллер изменяет состояние

парковочного места (свободно / занято), установив выводы МКПМ в соответствующие

состояния. Далее, микроконтроллер формирует пакет с информацией о состоянии

парковочного места и отправляет его через шину SPI на радиомодуль LoRa BEE, который, в

последствии, передаёт на вычислительный хаб Raspberry Pi, для последующей обработки.

Для осуществления оплаты заданного парковочного места используется терминал

оплаты, состоящий из дисплея, матричной клавиатуры и расширителя портов PCF8574 для

соединения клавиатуры с МК по шине I2C. Дисплей подключается к МК по шине I2C. В

диалоговом режиме на нём отображается информация о текущем состоянии оплаты. МК через

расширитель портов опрашивает клавиатуру и определяет нажатые клавиши. Для опроса

клавиатуры подаются на выходы расширителя, подключенные к столбцам клавиатуры,

сканирующие импульсы, а на входах, подключенных к строкам, определяется, какая клавиша

из соответствующего столбца нажата. Далее МК соответствующе обрабатывает нажатые

клавиши и отображает результат обработки на дисплей.

### 3.5 Разработка принципиальной схемы

### 3.5.1 Выбор элементной базы

### 3.5.1.1 Микроконтроллер ATMEGA328

В данной работе решено было использовать микроконтроллер семейства AVR, так как

он: широко распространен, имеет развитую систему команд, удовлетворяет всем современным

технологическим требованиям. Данное семейство восьмиразрядных микроконтроллеров

имеет обширное количество различных моделей. Было решено использовать ATMEGA328 как

широко распространенный и недорогой микроконтроллер, позволяющий реализовать все

поставленные задачи. УГО данного МК показано на рисунке 12.

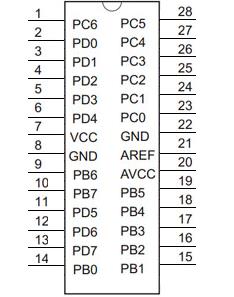
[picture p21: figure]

Рисунок 12 – УГО ATMEGA328

Описание выводов микроконтроллера приведено в таблице 1.

Таблица 2 – Описание выводов МК ATMEGA328

№ вывода | Мнемоника | Назначение вывода
7 | VCC | Питание +5В
8 | GND | Земля
17 | MOSI | Вход ведомого. Служит для передачи данных от ведущего устройства ведомому
18 | MISO | Выход ведомого. Служит для передачи данных от ведомого устройства ведущему
19 | SCK | Последовательный тактовый сигнал
3-6, 11-19 | PD1-PD6, PB0-PB5 | Цифровые входы/выходы
23-28 | PC0-PC5 | Аналоговые входы/выходы
1 | PC6 | Перезапуск МК
2 | PD0 | Чтение (разъем для программатора)
9 | PB6 | Подключение внешнего резонатора (вход)
10 | PB7 | Подключение внешнего резонатора (выход)

Микроконтроллер ATMEGA328 обладает следующими особенностями и техническими

характеристиками [11]:

1) расширенная архитектура RISC:
- мощная система команд со 131 инструкцией, большинство из которых

выполняются за один машинный цикл,

- 32 восьмиразрядных регистра общего назначения,
- производительность до 20 млн. оп./с на частоте 20МГц,
- встроенное умножение за 2 цикла;
2) высокая износостойкость энергонезависимых сегментов памяти:
- 32 КБ встроенной самопрограммируемой flash-памяти,
- 1 КБ энергонезависимой памяти (EEPROM),
- 2 КБ статической памяти (SRAM),
- 10000/100000 циклов перезаписи для Flash/EEPROM,
- хранение данных в течение 20 лет при температуре 25°С,
3) системы ввода-вывода: 23 программируемые линии ввода-вывода;
4) рабочее напряжение: от 1.8 до 5.5 В;
5) рабочая температура: от -40° до 85° С;
6) рабочая частота (4.5 - 5.5В): 20 МГц;
7) энергопотребление (1МГц, 1.8 В, 25° С):
- активный режим: 0.2 мА,
- режим пониженного энергопотребления: 0.1 мкА.

### 3.5.1.2 Радиочастотный приёмопередатчика RFM95W

RFM95W — модуль радиочастотного приёмопередатчика, работающий на частоте

868/915 МГц Работа приёмопередатчика основана на технологии LoRa, которая позволяет

добиться широкополосной передачи данных при крайне низком энергопотреблении, а также

высокой помехоустойчивости. УГО RFM95W представлено на рисунке 13, а описание

выводов – в таблице 3.

DIO2
DIO1
DIO0
3.3V
DIO4
DIO3
GND
ANT

GND
MISO
MOSI
SCK
NSS
RESET
DIO5
GND

RFM95W

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
Рисунок 13 – УГО приёмопередатчика RFM95W

Таблица 3 – Описание выводов RFM95W

№ Вывода | Мнемоника | Описание
1, 8, 10 | GND | Земля
2 | MISO | SPI выход последовательной передачи данных
3 | MOSI | SPI вход последовательного приема данных
4 | SCK | SPI вход синхронизации приема данных
5 | NSS | SPI вход выбора подчиненного
6 | RESET | Вход сброса
7, 11, 12, 14, 15, 16 | DIO5, DIO3, DIO4, DIO0, DIO1, DIO2 | Цифровой вход / выход конфигурации
9 | ANT | Вход / выход на антенну
13 | 3,3V | Питание 3,3В

Технические характеристики:

- Максимальный размер канала связи 168 дБ.
- Режим повышенной мощности, +20дБм/100мВт.
- Стандартный режим +14 дБм.
- Программируемая скорость передачи данных до 300 кбит / с.
- Высокая чувствительность: до -148 дБм.
- Низкий ток потребления пи приёме 10,3 мА.
- Полностью интегрированный синтезатор с разрешением 61 Гц.
- FSK, GFSK, MSK, GMSK, LoRaTM и OOK модуляции.
- 127 дБ динамический диапазон RSSI.
- Пакетный движок до 256 байтов с CRC.
- Встроенный датчик температуры и индикатор разряда батареи.
- Размер модуля: 16x16 мм

### 3.5.1.3 Расширитель портов PCF8574

PCF8574 [12] – кремневая ИС, выполненная по CMOS-технологии. Посредством

двухлинейной двунаправленной шины I2C она обеспечивает дистанционное расширение

порта ввода - вывода общего назначения в большинстве серий микроконтроллеров.

Устройство состоит из 8-битного квазипорта ввода-вывода и интерфейса I2C-шины. PCF8574

имеет низкий потребляемый ток. В устройстве установлена линия прерывания (INT), которая

может быть подключена к логике прерывания микроконтроллера. Посылая сигнал прерывания

по этой линии, дистанционный ввод - вывод сообщает микроконтроллеру о поступающих на

его порты данных, без необходимости поддерживать связь через I2C-шину. Это значит, что

PCF8574 может оставаться простым "подчиненным" устройством. На рисунке 14 приведено

УГО модификаций PCF8574P и PCF8574AP.

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
PCF8574AP

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
Рисунок 14 – УГО расширителя портов PCF8574P и PCF8574AP

В таблице 4 приведено описание выводов PCF8574.

Таблица 4 – Описание выводов PCF8574P / PCF8574AP

№ Вывода | Мнемоника | Описание
1 – 3 | A0 – A2 | Адресные входы
4 – 7, 9 – 12 | P0 – P3, P4 – P7 | Квази-двунаправленный ввод / вывод
8 | Vss | Земля
13 | INT | Вывод прерывания
14 | SCL | Последовательная линия синхронизации
15 | SDA | Последовательная линия данных
16 | Vdd | Питание 5 В

У данной микросхемы PCF8574 можно задавать адрес, под которым она будет

обозначаться на шине I2C. Всего имеется 8 вариантов адресации т.е. можно подключить 8

модулей, что в сумме позволяет нарастить 64 входа/выхода, используя 2 вывода контроллера.

Для изменения адресации необходимо установить на выводах A0, A1, A2 потенциал,

соответствующий логическому «0» или «1».

Модификация PCF8574AP отличается от PCF8574P только базовым адресом: у

PCF8574P – 0x20, а у PCF8574AP – 0x38. Сделано это для того, чтобы к одной шине можно

было подключить до 16-ти расширителей с разными адресами — максимум 8 штук PCF8574

и 8 штук PCF8574A.

Технические характеристики:

- Рабочий режим питания - от 2.5 до 6 В
- Низкий ток покоя – максимум 10 мА
- I

2C-шина для расширителя параллельного порта

- Выход прерывания с открытым стоком
- Дистанционный 8-битный расширитель ввода – вывода I²C-шины
- Адресация на 3 вывода аппаратных адресов для использования до 8 устройств (до

16 устройств при использовании PCF8574A)

В данной работе каждый расширитель портов закреплен за своим парковочным местом.

Они используются для считывания данных с сенсоров и для вывода информации о состоянии

парковочного места. Был выбран расширитель портов PCF8574, представленный в форм-

факторе PCF8574P и PCF8574АP.

### 3.5.1.4 Сравнение сенсоров присутствия автомобиля

Ниже в таблице 5 приведено сравнение сенсоров присутствия автомобиля:

Таблица 5 – Сравнение сенсоров присутствия автомобиля

| HC-SR04 | E18-D80NK | US-015 | JSN-SR04T
Тип | Ультразвук-овой | Фотоэлектр-ический | Ультразвук-овой | Ультразвук-овой
Обнаружение прозрачных объектов | + | - | + | +
Невосприимчивость к бликам | + | - | + | +
Работоспособность в условиях недостаточной видимости | + | - | + | +
Дальность обнаружения | 500 см | 80 см | 700 см | 450 см
Нижний порог обнаружения | 3 см | 3 см | 2 см | 25 см
Цена | 90 руб | 280 руб | 160 руб | 730 руб
В результате проведенного сравнения (Таблица 5) В качестве сенсора, следящего за

состоянием парковочного места, был выбран ультразвуковой датчик расстояния HC-SR04, т.к.

данный ультразвуковой датчик имеет следующие преимущества:

- обнаружение прозрачных объектов;
- невосприимчивость к световым вспышкам и бликам;
- работоспособность в сложных условиях (туман, пыль, пар);
- низкая цена.

Подробное описание датчика HC-SR04 смотри п.п. 3.5.1.5.

### 3.5.1.5 Ультразвуковой датчик расстояния HC-SR04

Бесконтактный направленный датчик HC-SR04 [13], используя ультразвуковые волны,

измеряет расстояние до объекта. На плате модуля размещены пьезоизлучатель ультразвука и

воспринимающий отраженную волну микрофон. В отличие от инфракрасных дальномеров на

ультразвуковой датчик HC-SR04 не влияют источники света или цвет препятствия. Внешний

вид данного датчика показан на рисунке 15. На рисунке 16 представлена УГО датчика

расстояния HC-SR04.

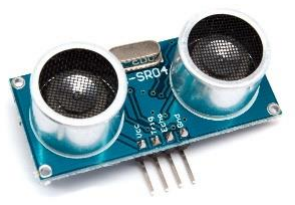
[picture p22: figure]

Рисунок 15 – Внешний вид ультразвукового датчика расстояния HC-SR04

Vcc
Trig
Echo
GND

HC-SR04

2
3
4

Рисунок 16 – УГО ультразвукового датчика расстояния HC-SR04

Ниже в таблице 6 приводится описание выводов данного датчика.

Таблица 6 – Описание выводов ультразвукового датчика расстояния HC-SR04

№ Вывода | Мнемоника | Описание
1 | VCC | Питание +5В
2 | GND | Земля
3 | Trig | Цифровой вход для включения измерения
4 | Echo | Цифровой выход. После завершения измерения, на этот выход будет подана логическая единица на время, пропорциональное расстоянию до объекта

Технические характеристики:

- Напряжение питания 5 В
- Ток потребления в режимах
- ожидания до 2 мА
- работы 15 мА
- Частота ультразвука 40 кГц
- Угол обзора 15 градусов
- Измеряемое расстояние
- от 0,03 до 0,6 м с разрешающей способностью 3 мм
- от 0,6 до 5 м погрешность увеличивается

Принцип работы:

1) Подается импульс продолжительностью 10 мкс, на вывод Trig.
2) Внутри дальномера входной импульс преобразуется в 8 импульсов частотой 40 КГц

и посылается вперед через "T глазик"

3) Дойдя до препятствия, посланные импульсы отражаются и принимаются "R

глазиком" (Рисунок 17). Получаем выходной сигнал на выводе Echo.

4) Непосредственно на стороне контроллера переводим полученный сигнал в

расстояние.

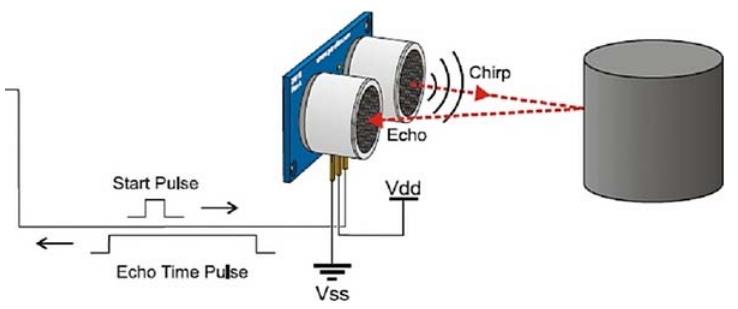
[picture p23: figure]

Рисунок 17 – Принцип работы ультразвукового датчика расстояния HC-SR04

### 3.5.1.6 Часы реального времени DS3231SN

Для постоянного учёта хронометрических данных (дата, время) на микроконтроллере

используются часы реального времени DS3231SN. Внешний вид модуля часов реального

времени представлен на рисунке 18.

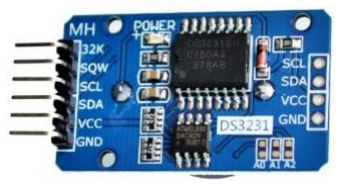
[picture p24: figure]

Рисунок 18 – Внешний вид модуля часов реального времени DS3231SN

На рисунке 19 показано УГО для часов реального времени DS3231SN. В таблице 7

приводится описание выводов часов.

SCL
SDA

VBAT
GND
N.C.
N.C.
N.C.
N.C.

32kHz

VCC
SQW
RST
N.C.
N.C.
N.C.
N.C.

DS3231SN

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
Рисунок 19 – УГО часов реального времени DS3231SN

Таблица 7 – Описание выводов часов реального времени DS3231SN

№ Вывода | Мнемоника | Описание
1 | 32kHz | Тактовый вывод с частотой 32кГц
2 | VCC | Питание +5В
3 | SQW | Программируемый выход Square-Wave сигнала
4 | RST | Сброс
5 – 12 | N.C. | Не соединения
13 | GND | Земля
14 | VBAT | Питание от батареи 3,3В
15 | SDA | Последовательная линия данных
16 | SCL | Последовательная линия синхронизации

Технические характеристики:

- Рабочая температура -40°C ~ 85°C
- Напряжение питания, батареи 2,3 V ~ 5,5 V
- Напряжение питания 2,3 V ~ 5,5 V
- Интерфейс подключения I²C

Микросхема DS3231 представляет собой высокоточные часы реального времени RTC,

которая обладает встроенным кварцевым генератором с температурной компенсацией,

благодаря чему уход времени составляет всего ±2 минуты за год. Дополнительно реализована

функция будильника, также имеется выход прерываний.

Микросхема использует интерфейс передачи данных I2C. Адрес микросхемы (7 бит) на

шине I2C равен 1101000.

### 3.5.2 Описание принципиальной схемы МКПМ

Были спроектированы принципиальные схемы МКПМ на базе PCF8574P и PCF8574АP,

которые представлены на рисунках Е.8 и Д10 соответственно. Данные схемы соответственно

описывают блоки PPCM и PPCM_A, УГО которых изображены на рисунке 20. Данные модули

отличаются от друг драга – модификацией расширителя порта PCF8574, на которой они

построены. Модуль PPCM построен на базе расширителя порта PCF8574P, а PPCM_A – на

базе PCF8574АP. Функциональная схема данных модулей представлена на рисунке Е.5 и была

описана в п.п. 0. В таблице 8 приведено описание выводов МКПМ.

A0
A1
A2
SDA
SCL
Trig
Vcc
GND

PPCM

2
3
4
5
6
7
8

Free
Booked

9
10

A0
A1
A2
SDA
SCL
Trig
Vcc
GND

PPCM_A

2
3
4
5
6
7
8

Free
Booked

9
10

Рисунок 20 – УГО модулей PPCM и PPCM_A

Таблица 8 – Описание выводов модулей PPCM / PPCM_A

№ Вывода | Мнемоника | Описание
1 – 3 | A0 – A2 | Адресные входы
4 | SDA | Последовательная линия данных
5 | SCL | Последовательная линия синхронизации
6 | Trig | Цифровой вход для включения измерения
7 | VCC | Питание +5В
8 | GND | Земля
9 | Free | Выводит сигнал «Free» логическая «1» означает, что данное парковочное место свободно, а «0» – занято
10 | Booked | Выводит сигнал «Booked» логическая «1» означает, что данное парковочное место забронировано, а «0» – нет

За каждым парковочным местом закреплен свой МКПМ, состоящий из расширителя

портов PCF8574 (DD1) и сенсора HC-SR04 (DD2). Расширитель портов осуществляет связь

МК с сенсором и выводит информацию о состоянии парковочного места. К выводам P1 и P2

расширителя соответственно подключены светодиоды VD1 и VD2, которые наглядно

показывают состояние данного парковочного места. Данный расширитель портов

подключены к МК по шине I2C. PCF8574 имеет 3 адресных входа, таким образом, можно

подключить до 8 таких устройств, следовательно, МКПРСПМ может обслуживать до 8

парковочных мест. Модификация PCF8574AP имеет другой базовый адрес, следовательно,

параллельно можно подключить еще 8 устройств PCF8574AP, тогда разрабатываемое

устройство сможет обслуживать до 15 парковочных мест + 1 расширитель для подключения

клавиатуры к МК. В таблице 9 приведено описание ролей выводов расширителя портов

PCF8574 (DD2).

Таблица 9 – Роли выводов расширителя портов PCF8574P / PCF8574AP

Контакт | Роль
1, 2, 3 – A0, A1, A2 | Адресные входы
4 – P0 | Выход на вывод Trig сенсора HC-SR04 для включения измерения
5 – P1 | Выводится логическая «1», в случае если парковочное место свободно, иначе – «0»
6 – P2 | Выводится логическая «1», в случае если парковочное место забронировано, иначе – «0»
8 – Vss | Земля
14 – SCL | Последовательная линия синхронизации
15 - SDA | Последовательная линия данных
16 – Vdd | Питание +5В

Сенсор HC-SR04 (DD2) осуществляет мониторинг занятости данного парковочного

места. Вход Trig сенсора соединен с выводом P0 расширителя портов PCF8574 (DD1). Для

включения измерения сенсора МК подаёт сигнал на вывод P0 соответствующего расширителя

портов. После завершения измерения на выходе Echo сенсора HC-SR04 будет подана

логическая единица на время, пропорциональное расстоянию до объекта. Выход Echo сенсора

соединён с МК через вход PD3. В таблице 10 приведено описание ролей выводов данного

сенсора.

Таблица 10 – Роли выводов сенсора HC-SR04

Контакт | Роль
1 – VCC | Питание +5В
2 – GND | Земля
3 – Echo | Цифровой вход для включения измерения.
4 – Trig | Цифровой выход, после завершения измерения, будет подана логическая единица на время, пропорциональное расстоянию до ТС

Расширители портов PCF8574 (DD1) выдают очень низкий ток 100 мкА, поэтому были

добавлены MOSFET-транзисторы (VT1, VT2) для усиления выходных сигналов «Free» и

«Booked». В цепь затвора транзисторов были добавлены подтягивающие резисторы (R3, R5),

чтобы гарантированно удерживать высокий уровень на затворе мосфета при отсутствии

сигнала низкого уровня от расширителя (DD1). Это исключает самопроизвольное выключение

транзистора. В разрыв цепи затвора также установлены резисторы (R1, R2) номиналом 100

Ом, для предотвращения кратковременных выбросов тока и защиты вывода PCF8574.

### 3.5.3 Описание принципиальной схемы МКПРСПМ

На основе описанной элементной базы (п.п. 3.5.) была разработана принципиальная

схема МКПРСПМ для 15 парковочных мест, которая доступна для ознакомления на

рисунке Е.13.

Модуль RFM95W (DD7), осуществляющий передачу и приём данных по сети LoRa,

подключен к МК ATMEGA328P-PU (DD8) шине SPI. В таблице 11 приведено описание

подключения модуля RFM95W к МК.

Таблица 11 – Подключение модуля RFM95W к МК ATMEGA328P

Контакт RFM95W | Контакт МК | Роль
1, 8, 10 – GND | – | Земля
2 – MISO | 18 – PB4 (MISO) | Приём данных от модуля на МК
3 – MOSI | 17 – PB3 (MOSI) | Передача данных от МК на модуль
4 – SCK | 19 – PB5 (SCK) | Синхронизация передачи данных
5 – NSS | 16 – PB2 (SS) | Выбор подчиненного устройства
6 – RESET | 15 – PB1 | Перезапуск модуля
9 - ANT | – | Вывод на антенну
13 – 3,3V | – | Питание +3,3В
14 – DIO0 | 4 – PD2 (INT0) | Возникновение прерывание на МК при успешном приёме / передачи пакета по сети LoRa

Микроконтроллер Arduino Uno R3 содержит встроенный драйвер USART-USB,

выполненный на ATMEGA16U2 (DD2), необходимый для передачи и приёма данных на

ПЭВМ по последовательному интерфейсу. Таким образом, с помощью данного модуля можно,

как альтернатива модулю RFM95, осуществлять приём / передачу данных.

Для работы шины I2C необходима внешняя подтяжка к питанию, состоящая из двух

резисторов. В данном проекте такими резисторами являются R14 и R15, номинал которых

равен 4,7КОм.

За каждым парковочным местом закреплен свой модуль МКПМ (DD10 – DD24),

которые разделяются на две модификации PPCM (DD11 – DD17) и PPCM_A

(DD10, DD18 – DD24). Данные модули подключаются к МК по шине I2C. PPCM отличается

от PPCM_A только базовым адресом: у PPCM – 0x20, а у PPCM_A – 0x38. Таким образом,

можно подключить до 15 таких устройств, что позволит МКПРСПМ обслуживать 15

парковочных мест. В таблице 12 приведено описание подключения модулей МКПМ к МК.

Таблица 12 – Подключение модуля PPCM / PPCM_A к МК ATMEGA328P

Контакт МКПМ | Контакт МК | Роль
1, 2, 3 – A0, A1, A2 | – | Адресные входы
4 – SDA | 27 – PC4 | Последовательная линия данных
5 – SCL | 28 – PC5 | Последовательная линия синхронизации
6 – Trig | 5 – PD3 | Цифровой вход для включения измерения
7 – VCC | – | Питание +5В
8 – GND | – | Земля
9 – Free | – | Выводит сигнал «Free» логическая «1» означает, что данное парковочное место свободно, а «0» – занято
10 – Booked | – | Выводит сигнал «Booked» логическая «1» означает, что данное парковочное место забронировано, а «0» – нет

Часы реального времени DS3231SN (DD6), используются для учета хронометрических

параметров. Они подключаются к МК по шине I2C. Чтобы при отключении питания

МКПРСПМ время на часах не сбрасывалось, часы дополнительно питаются от

гальванического элемента G1, напряжение питания которого равно +3,3В. В таблице 13

описывается подключение часов к МК.

Таблица 13 – Подключение часов реального времени DS3231SN к МК ATMEGA328P

Контакт DS3231SN | Контакт МК | Роль
2 – VCC | – | Питание +5В
13 – GND | – | Земля
14 – VBAT | – | Питание от батареи +3,3В
15 – SDA | 27 – PC4 | Последовательная линия данных
16 – SCL | 28 – PC5 | Последовательная линия синхронизации

Клавиатура AK-1604-N-WWB (DD5) подключается к МК посредством расширителя

портов PCF8574P (DD4). Строки клавиатуры (ROW0 – ROW3) подключаются к выводам

расширителя P0 – P3, а столбцы (COL0 – COL3) – к выводам P4 – P7. Таким образом, для

подключения клавиатуры используются не 8 выводов МК, а 2, т.е. линии шины I2C. В таблице

14 приводится описание подключения данного расширителя PCF8574P (DD4) к

микроконтроллеру.

Таблица 14 – Подключение расширителя портов PCF8574P, отвечающего за клавиатуру, к

МК ATMEGA328P

Контакт PCF8574P | Контакт МК | Роль
1, 2, 3 – A0, A1, A2 | – | Адресные входы
4, 5, 6, 7 – P0, P1, P2, P3 | – | Выводы для подключения строк клавиатуры
8 – Vss | – | Земля
9, 10, 11, 12 – P4, P5, P6, P7 | – | Выводы для подключения столбцов клавиатуры
14 – SCL | 28 – PC5 | Последовательная линия синхронизации
15 – SDA | 27 – PC4 | Последовательная линия данных
7 – VDD | – | Питание +5В

Дисплей WAVGAT_128x64 (DD9) подключается к МК по шине I2C. Ниже в таблице

приведено описание подключения этого дисплея к МК.

Таблица 15 – Подключение дисплея WAVGAT_128x64 к МК ATMEGA328P

Контакт WAVGAT_128x64 | Контакт МК | Роль
1 – GND | – | Земля
2 – VCC | – | Питание +5В
3 – SCL | 28 – PC5 | Последовательная линия синхронизации
4 – SDA | 27 – PC4 | Последовательная линия данных

В качестве драйвера USB-UART используется микроконтроллер ATMEGA16U2 (DD2),

обеспечивающий связь микроконтроллера с USB-портом ПЭВМ. При подключении к ПК

Arduino UNO определяется как виртуальный COM-порт. Заводская прошивка ATMEGA16U2

использует стандартные драйвера USB-COM — установка внешних драйверов не требуется,

что делает принцип работы микросхемы удобным в эксплуатации. В таблице 12 приведено

описание подключения драйвера к МК.

Таблица 16 – Описание выводов ATMEGA16U2

Контакт ATMEGA16U2 | Мнемоника | Назначение вывода
4 – VCC | – | Питание +5В
3 – GND | – | Земля
32 – AVCC | – | Питание для всех аналоговых устройств
8 – PD2 | 2 – PD0 | Приём данных на МК
8 – PD3 | 3 – PD1 | Передача данных от МК
30 – D- | – | Порт USB с отрицательной обратной связью
29 - D+ | – | Порт USB с положительной обратной связью
28 – UGND | – | USB земля
27 – UCAP | – | USB регулятор выходного напряжения питания
1 – XTAL1 | – | Подключение внешнего резонатора (вход)
2 – XTAL2 | – | Подключение внешнего резонатора (выход)

USB-разъем, помимо предоставления интерфейса для последовательной передачи

данных к ПЭВМ, позволяет использовать компьютер, как источник питания. Для токовой

защиты установлен самовосстанавливающийся предохранитель MF-MSMF050-2 (F1),

защищающий порт USB компьютера от токов короткого замыкания и сверхтоков. Хотя

практически все компьютеры имеют подобную защиту, тем не менее, данный предохранитель

обеспечивает дополнительный барьер. Предохранитель срабатывает при прохождении тока

более 500 мА через USB порт и размыкает цепь до тех пор, пока нормальные значения токов

не будут восстановлены.

### 3.6 Расчет потребляемой мощности

Суммарная мощность, которую потребляет устройство – есть сумма мощностей

элементов, из которых это устройство состоит. Мощность – произведение напряжения

питания и тока, который протекает через микросхему.

Для расчета потребляемой мощности используем информацию из документации

используемых микросхем и других элементов. Информация о токах и соответственно

мощности, потребляемых микросхемами, приведена в таблице 17.

Таблица 17 – Расчет мощности компонентов

Наименование микросхемы | Ток потребления, мА | Напряжение питания | Потребляемая мощность, мВт
ATMEGA328P | 16 | 5 | 80
ATMEGA16U2 | 50 | 5 | 250
LoRa BEE | 10,3 | 3,3 | 40
PCF8574P | 80 | 5 | 400
HC-SR04 | 15 | 5 | 75
DS3231SN | 3 | 5 | 15
WAVGAT_128x64 | 16 | 5 | 80

Используя информацию из таблицы, рассчитаем суммарную потребляемую мощность,

для МКПРСПМ обслуживающего одно парковочное место:

P = 80 + 250 + 40 + 400 + 75 + 400 + 15 + 80 = 1340 мВт

Для МКПРСПМ обслуживающего 15 парковочных мест, потребляющая мощность

будет составлять:

P = 80 + 250 + 40 + (400 + 75) ∗ 15 + 400 + 15 + 80 = 8710 мВт

### 3.7 Описание разработанного программного обеспечения

### 3.7.1 Описание схемы алгоритма

Для реализации указанных в задании функций было разработано программное

обеспечение, обеспечивающее взаимодействие элементов микроконтроллерной системы и

обработку поступающих данных.

Схема алгоритма основной программы представлена на рисунке 21. Первоначально

выполняется настройка и инициализация всех используемых элементов, после чего программа

переходит в бесконечный цикл опроса.

## Начало

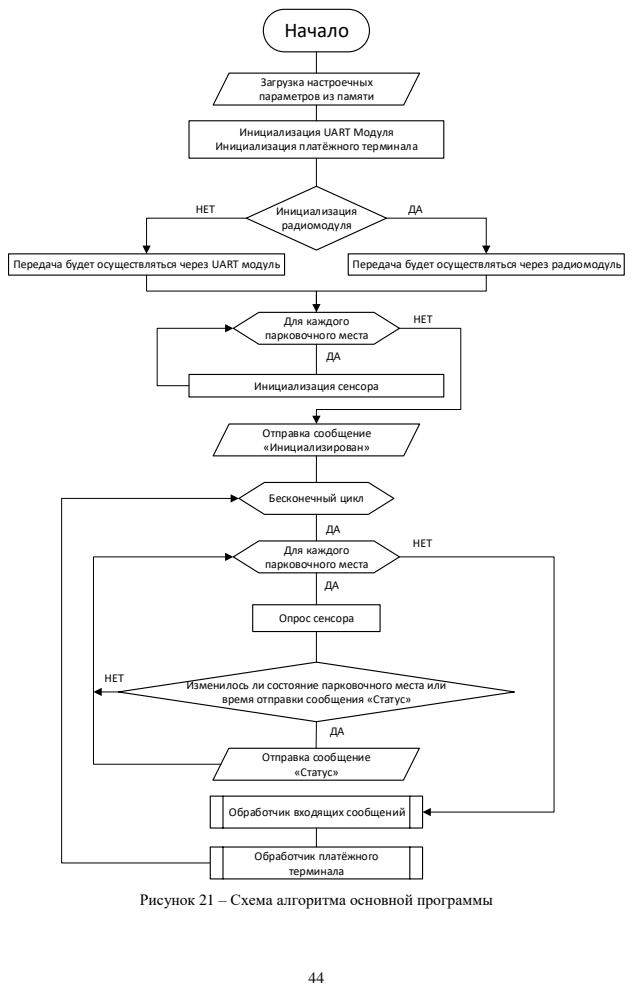
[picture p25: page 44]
Инициализация радиомодуля; Инициализация сенсора; Бесконечный цикл; Отправка сообщение «Инициализирован»; Для каждого парковочного места; Отправка сообщение «Статус»; НЕТ; Опрос сенсора; Обработчик платёжного терминала

Загрузка настроечных
параметров из памяти

Инициализация UART Модуля
Инициализация платёжного терминала

Передача будет осуществляться через UART модуль

Передача будет осуществляться через радиомодуль

Изменилось ли состояние парковочного места или

время отправки сообщения «Статус»

Обработчик входящих сообщений

Рисунок 21 – Схема алгоритма основной программы

Блок «Обработчик входящих сообщений» является составным для компактности

основной блок схемы. Блок схема этой процедуры представлена на рисунке 22.

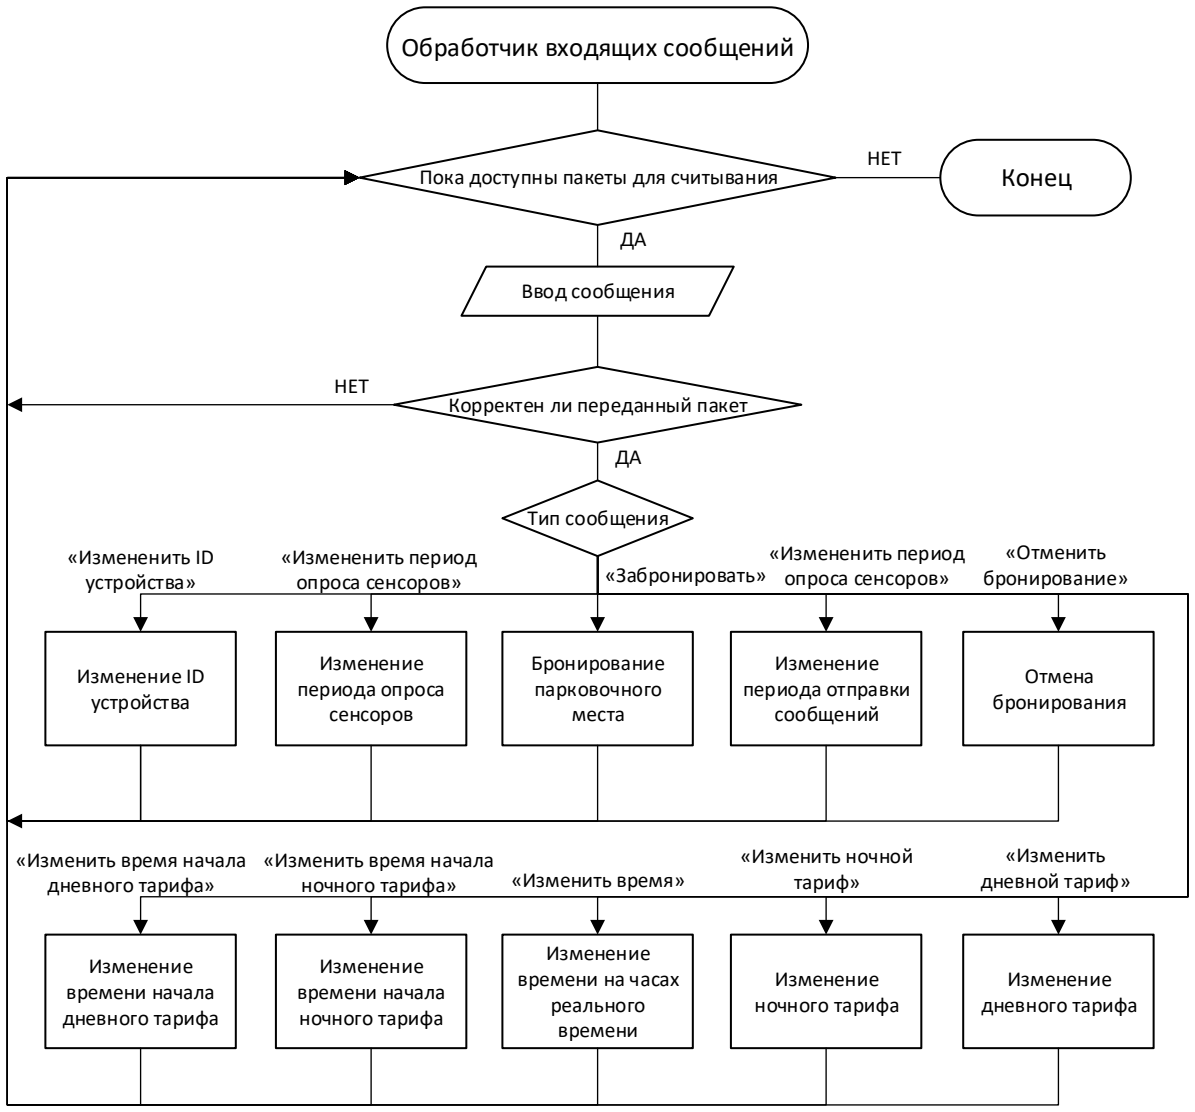
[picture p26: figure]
Обработчик входящих сообщений; Пока доступны пакеты для считывания; Ввод сообщения; Тип сообщения; Корректен ли переданный пакет; Изменение ID устройства; Изменение периода опроса сенсоров; Бронирование парковочного места; Изменение периода отправки сообщений; Отмена бронирования; Конец; «Измененить ID устройства»; «Измененить период опроса сенсоров»; «Отменить бронирование»; НЕТ; «Забронировать»; Изменение времени начала дневного тарифа; Изменение времени начала ночного тарифа; Изменение ночного тарифа; Изменение дневного тарифа; «Изменить время начала дневного тарифа»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

Рисунок 22 – Схема алгоритма процедуры «Обработчик входящих сообщений»

Ниже на рисунке 23 представлена блок схема процедуры «Обработчик платёжного

терминала».

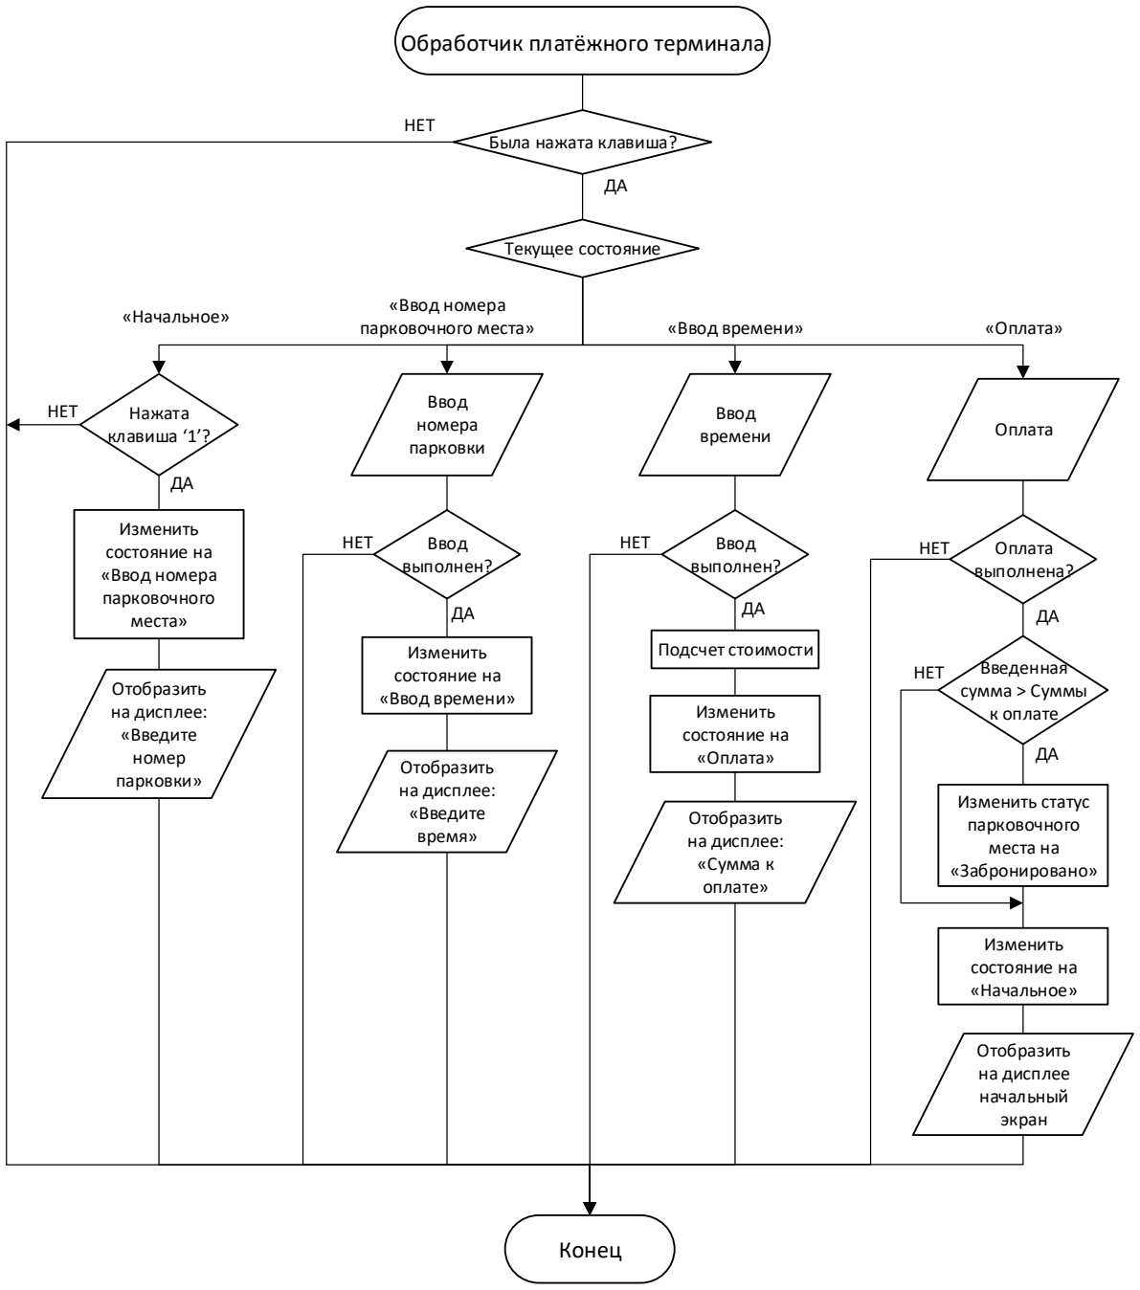
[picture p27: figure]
Обработчик платёжного терминала; Была нажата клавиша?; Текущее состояние; «Начальное»; «Ввод номера; парковочного места»; «Оплата»; НЕТ; «Ввод времени»; Конец; Нажата клавиша 1 ?; Изменить состояние на «Ввод номера парковочного места»; Отобразить на дисплее: «Введите номер парковки»; Ввод номера парковки; Ввод выполнен?; Изменить состояние на «Ввод времени»; Отобразить на дисплее: «Введите время»; Ввод времени; Изменить состояние на «Оплата»; Отобразить на дисплее: «Сумма к оплате»; Оплата; Оплата выполнена?; Изменить состояние на «Начальное»; Отобразить на дисплее начальный экран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

Рисунок 23 – Схема алгоритма процедуры «Обработчик платёжного терминала»

### 3.7.2 Описание диаграммы классов

При разработке программы применялся преимущественно объектный подход, так как

данный подход является наиболее удобным для дальнейшей разработки и поддержки проекта.

На рисунке Е.14 представлена диаграмма классов разработанной программы. Как можно

видеть из диаграммы классов было реализовано два паттерна «Стратегия» и один «Одиночка».

Паттерн | «Стратегия» | позволяет | выбирать | алгоритм | путём | определения

соответствующего класса. Класс «ReceiverTransmitter» является интерфейсом для классов

«RadioModule» и «SerialModule». Это позволило в основной программе реализовать

процедуру выбора драйвера для приёма и передачи данных. В случае отсутствия радиомодуля

LoRa, то в качестве драйвера будет выбран драйвер USB-UART.

При создании объекта класса «ReceiverTransmitter» в конструктор передаётся

обработчик входящих сообщений – объект, принадлежащий абстрактному классу

«AbstractReceiveMessageHandler». Это позволяет задавать различные обработчики входящих

сообщений. Например, операция по изменению ID устройства является небезопасной, и было

принято решение запретить выполнять данную операцию при приёме сообщений по

беспроводной связи, однако при подключении по UART интерфейсу операция разрешена.

Паттерн | «Одиночка» | – | шаблон | проектирования, | гарантирующий, | что | в

однопроцессном приложении будет единственный экземпляр некоторого класса, и

предоставляющий глобальную точку доступа к этому экземпляру. «Одиночкой» является

класс «Parameters», который содержит в себе настроечные параметры, и осуществляющий

запись параметров память EEPROM. Определив этот класс «Одиночкой», позволило иметь

доступ к единственному экземпляру данного класса из любого места программы.

### 3.8 Описание системы сообщений МКПРСПМ

Реализована система сообщений для приёма и передачи информации между

МКПРСПМ и вычислительным хабом. Каждое принимаемое и отправляемое сообщение

состоит из заголовка и тела сообщения.

Структура заголовка:

1) 1 байт – Тип сообщения
2) 4 байта – Идентификатор МКПРСПМ

Далее рассматривается структура тела сообщения для каждого типа сообщений,

отправляемых с МКПРСПМ:

- Инициализация МКПРСПМ:
1) 2 байта – Период опроса датчиков
2) 2 байта – Период отправки сообщений о состоянии парковочного места
3) 2 байта – Дневной тариф
4) 2 байта – Ночной тариф
5) 4 байта – Время начала дневного тарифа
6) 4 байта – Время начала ночного тарифа
- Состояние парковочного места:
1) 1 байт – Идентификатор парковочного места
2) 1 байт – Булевое значение свободно ли парковочное место
- Оплата парковочного места:
1) 1 байт – Идентификатор парковочного места
3) 4 байта – Время бронирования
4) 2 байта – Внесенная сумма
5) 2 байта – Итоговая стоимость

Структура тела сообщения для основных типов принимаемых сообщений:

- Изменить идентификатор МКПРСПМ.
1) 4 байта – Новый идентификатор МКПРСПМ
- Изменить период отправки сообщений о состоянии парковочного места:
1) 2 байт – Период отправки сообщений о состоянии парковочного места
- Изменить время на часах реального времени:
1) 4 байта – Время
- Изменить дневной тариф
1) 2 байта – Стоимость 1 часа в рублях
- Изменить параметры настройки
1) 2 байта – Период опроса датчиков
2) 2 байта – Период отправки сообщений о состоянии парковочного места
3) 2 байта – Дневной тариф
4) 2 байта – Ночной тариф
5) 4 байта – Время начала дневного тарифа
6) 4 байта – Время начала ночного тарифа

- Бронирование парковочного места
1) 1 байт – Идентификатор парковочного места
2) 2 байта – Время бронирования
- Отмена бронирования парковочного места
1) 1 байт – Идентификатор парковочного места

При отправке сообщения через UART интерфейс перед заголовком добавляется еще 1

байт – длина сообщения.

### 4 Разработка вычислительного хаба

### 4.1 Анализ требований

Согласно анализу технического задания, консольное приложение вычислительного

хаба должен реализовывать следующий функционал:

- прием пакетов данных, полученные от датчиков МКПРСПМ по сети LoRaWAN или

через последовательный порт UART и формирование MQTT-пакетов в формате

JSON и передача их на сервер и на другие устройства СМПМ;

- приём MQTT пакетов данных в формате JSON, полученные от сервера и передача

их на МКПРСПМ;

- конфигурационный файл для настройки параметров ПО вычислительного хаба.

Для реализации ПО вычислительного хаба использовались библиотеки фреймворка Qt,

а также библиотека RadioHead для работы с радиомодулем RFM95. Основное преимущество

использования Qt фреймворка – является то, что он является кроссплатформенным, т.е.

разработанное ПО можно будет запускать на различных устройствах и ОС. Таким образом

данное ПО можно будет установить не только на микрокомпьютере Raspberry Pi, но и на

обычном ПК для тестирования или для непосредственного использования данной системы.

Также в Qt имеются такие удобные библиотеки как:

- «QMqttClient» – интерфейс для взаимодействия с MQTT брокером (появилась

только в Qt 5.10);

- «QSerialPort» – интерфейс для взаимодействия с последовательными портами;
- «QSettings» – класс для реализации постоянных платформонезависимых настроек

приложения.

### 4.2 Подключение радиомодуля RFM95

Радиомодуль RFM95 (п.п. 3.5.1.2. Радиочастотный приёмопередатчика RFM95W)

используется для связи вычислительного хаба с датчиками МКПРСПМ по сети LoRaWAN.

Если вычислительный хаб представлен в виде микрокомпьютера Raspberry Pi 3 Model B, то в

таблице 18 приведено подключение радиомодуля к данному микрокомпьютеру:

Таблица 18 – Подключение модуля RFM95W к Raspberry Pi 3 Model B

Контакт RFM95W | Контакт Raspberry Pi 3 Model B | Роль
1, 8, 10 – GND | 20 – GND | Земля
2 – MISO | 21 – SPI0 MISO | Приём данных от модуля на Raspberry
3 – MOSI | 19 – SPI0 MOSI | Передача данных от Raspberry на модуль
4 – SCK | 23 – SPI0 SCLK | Синхронизация передачи данных
5 – NSS | 24 – SPI0 CE0 | Выбор подчиненного устройства
9 - ANT | – | Вывод на антенну
13 – 3,3V | 17 – 3,3V | Питание +3,3В
14 – DIO0 | 22 – GPIO25 | Возникновение прерывание на Raspberry при успешном приёме / передачи пакета по сети LoRa

Ниже на рисунке 24 показано подключение модуля LoRa BEE на базе радиочастотного

приёмопередатчика RFM95W к микрокомпьютеру Raspberry Pi 3 Model B:

Рисунок 24 – Внешний вид подключения модуля LoRa BEE к Raspberry Pi 3 Model B

### 4.3 Описание диаграммы классов

При проектировании ПО для вычислительного хаба использовался объектно-

ориентированный подход, т.к. при таком подходе ускоряется время разработки и

программный продукт легко изменять и добавлять новый функционал. На рисунке Е.15

показана разработанная диаграмма классов.

«Worker» является главным классом, отвечающий за инициализацию, а также

периодическим опросом драйвера (класс «Driver») в методе «run()» для приёма данных с

радиомодуля LoRa или с последовательного порта. С помощью «QTimer» с заданной

периодичностью вызывается метод «run()».

Абстрактный класс «Driver» является базовым классом для «LoRaConnection» и

«SerialConnection» и является интерфейсом для взаимодействия с датчиками МКПРСПМ.

Потомки данного класса реализовывают подключение и приём-передачу данных с

МКПРСПМ, определяя методы «send()», «available()» и «recv()». Таким образом, реализуется

паттерн «Стратегия», тем самым внутри «Worker» в зависимости от настроек выбирается

способ подключения с датчиками МКПРСПМ: радиомодуль LoRa или последовательный порт

UART. Принимая пакет, драйвер определяет тип сообщения и отправляет его на

соответствующий обработчик.

Класс «Server» реализует интерфейс взаимодействия с сервером по протоколу MQTT.

При инициализации он подключается к MQTT брокеру сервера и подписывается на

соответствующие темы. Приняв сообщение от сервера, экземпляр класса по подписке

определяет соответствующий обработчик.

Абстрактный | класс | «AbstractReceiveMessageHandler» | является | обработчиком

входящих сообщений от датчиков МКПРСПМ и сервера. Данный класс реализует потомок

«ReceiveMessageHandler».

### 4.4 Описание файла настроек

При первом запуске приложения генерируется файл настроек «settings.ino», в котором

можно поменять способ подключения к датчикам МКПРСПМ (LoRa или UART), перечислить

список идентификаторов датчиков, настроить подключение к серверам и т.д. Ниже (Листинг

1) приводится пример настроечного файла «settings.ino» с комментариями, в которых описан

каждый параметр:

Листинг 1 – Файл «settings.ino»

[General]
# Способ подключения к датчикам МКПРСПМ (lora, serial) driver=lora

# Частота радиомодуля при подключении по lora frequency=868

# Timeout при отправки данных по lora lora_timeout=1000

# Последовательный порт при подключении serial serial_port=ttyUSB0

# Baud rate для последовотельного порта baud_rate=9600

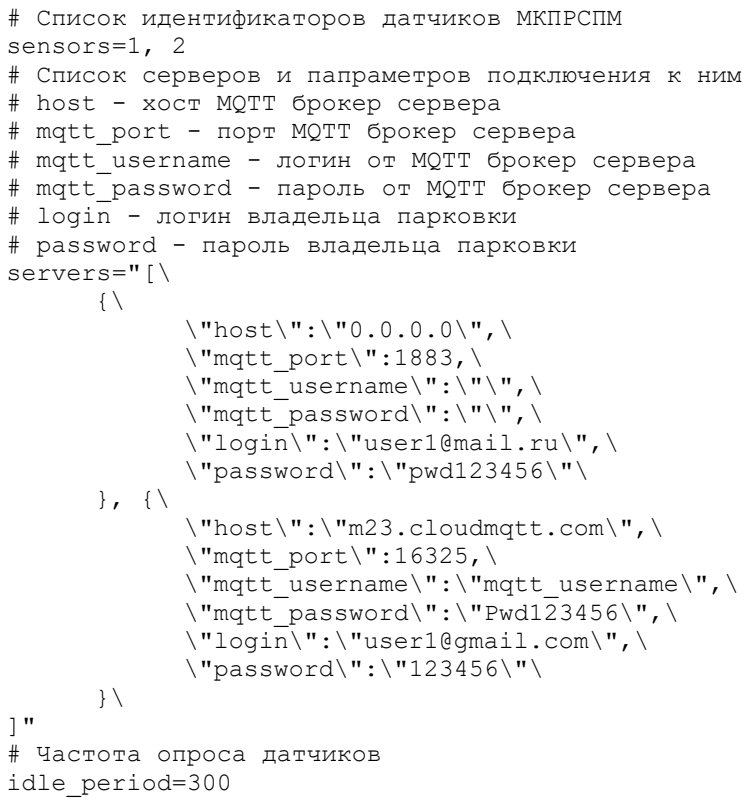
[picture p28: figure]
sensors=1, 2; # host - хост MQTT брокер сервера # mqtt_port - порт MQTT брокер сервера; # login - логин владельца парковки # password - пароль владельца парковки servers="[\ {\; \"host\":\"0.0.0.0\",\ \"mqtt_port\":1883,\ \"mqtt_username\":\"\",\ \"mqtt_password\":\"\",\ \"login\":\"user1@mail.ru\",\ \"password\":\"pwd123456\"\; \"host\":\"m23.cloudmqtt.com\",\ \"mqtt_port\":16325,\ \"mqtt_username\":\"mqtt_username\",\ \"mqtt_password\":\"Pwd123456\",\ \"login\":\"user1@gmail.com\",\ \"password\":\"123456\"\; ]" # Частота опроса датчиков idle_period=300

# Список идентификаторов датчиков МКПРСПМ

# Список серверов и папраметров подключения к ним

# mqtt_username - логин от MQTT брокер сервера # mqtt_password - пароль от MQTT брокер сервера

Обратите внимание, что параметр «servers» описывается в виде массива, таким

образом, можно подключить несколько MQTT брокер серверов, и от каждого из них хаб будет

принимать команды и отправлять каждому данные от датчиков МКПРСПМ.

### 5 Разработка сервера

### 5.1 Анализ задания и выбор технологий

Как показал анализ технического задания, ПО на серверной стороне должен

реализовывать следующий функционал:

- отображение на карте местоположения стоянок и парковочных мест;
- выдача актуальных данных о ПМ;
- бронирование парковочного места;
- добавление датчиков МКПРСПМ;
- удалённая настройка датчиков МКПРСПМ;
- | регистрирование | стоянок | и | парковочных | мест | с | указанием

местоположения на карте;

- изменение данных о стоянках и парковочных местах;

- приём MQTT пакетов данных о состоянии ПМ, полученные от вычислительного

хаба;

- сохранение данных об изменении состоянии ПМ в БД;
- регистрация и авторизация пользователей.

Для создания данного ПО для серверной части был использован полноценный,

многоуровневый фреймворк, использующий базы данных, Ruby on Rails, который основан

на архитектуре | Модель-Представление-Контроллер | (Model-View-Controller, | MVC).

Обработка запросов и выдача данных в контроллерах, предметная область, отраженная в базе

данных, – для всего этого Rails предоставляет однородную среду разработки на Ruby.

Основным преимуществом языка программирования Ruby и фреймворка Ruby on Rails

считается скорость разработки. Практика показывает, что скорость разработки проектов на

RoR увеличивается на 30 – 40 процентов по отношению к любому другому языку

программирования или фреймворку. В первую очередь прирост скорости разработки

определяется обширным набором готовых к работе штатных инструментов RoR,

колоссальным набором готовых решений в сообществе, языком Ruby и простоте

программирования на нем. Кроме того, в отличие от других фреймворков, в составе RoR есть

отличные средства автоматизированного тестирования, что ускоряет переход проекта от

стадии «программа написана» к стадии «программа работает без ошибок». Так же следует

отметить, что Ruby on Rails обеспечивает лучшую безопасность проекта. При использовании

инструментов RoR исключены SQL-инъекции и XSS-атаки, все входные параметры

экранируется по умолчанию, выводимые переменные в шаблонах также экранируются.

Согласно анализу требований, на серверной стороне используется следующее ПО:

- Разработанное веб-приложение на фреймворке Ruby on Rails.
- Frontend-сервер Nginx, который осуществляет раздачу статических файлов и

проксирование запросов на веб-сервер Puma, взаимодействующий с веб-

приложением на Ruby on Rails.

- MQTT-брокер Mosquitto необходим для реализации MQTT протокола. На брокера

приходят данные с вычислительных хабов, а веб-приложение их считывает.

- Сервис кэширования Memcached используется веб-приложением для кэширования

данных.

- СУБД PostgreSQL используется для хранения данных.
- СУБД Redis необходим для работы Action Cable, позволяющий взаимодействовать

с веб-клиентами по WebSocket.

- Фреймворк Bootstrap v4.1 – это инструментарий с открытым исходным кодом для

разработки с помощью HTML, CSS и JS. С помощью него создаётся адаптивный и

интерактивный веб-дизайн.

- Google Maps APIs для реализации карты парковок.

### 5.2 Анализ способа хранения данных

Существует | несколько | технологий | позволяющих | хранить | и | упорядочивать

информацию. Существует множество систем управления базой данных (СУБД),

проанализировав их, я пришёл к выводу, что наиболее лучшим вариантом будет

использование PostgreSQL, т.к. оно обладает следующими преимуществами: поддержка БД

неограниченного размера, мощные и надёжные механизмы транзакций и репликации,

расширяемая система встроенных языков программирования, наследование, легкая

расширяемость. Также для работы с картографическими данными имеется расширение

PostGIS.

На рисунке Е.16 показана разработанная схема базы данных. В таблице «users»

находятся зарегистрированные пользователи системы.

В таблице «parkings» хранятся стоянки. В поле «area» находится массив координат

полигона, который образует территория стоянки. Это необходимо для отрисовки на карте

синего | полигона, | обозначающего | территорию | стоянки | (Рисунок | 25). | Поле

«parking_places_count» добавлено с целью оптимизации выдачи количества парковочных

мест, принадлежащих данной стоянке.

Таблица «sensors» хранит добавленные датчики регистрации свободных парковочных

мест. При добавлении нового датчика для него генерируется уникальный идентификатор «id»,

который необходимо будет указать самому физическому датчику.

В таблице «parking_places» находятся парковочные места. Поля «booked», «free» и

«connected» отвечают за текущее состояние ПМ. Поле «can_book» отвечает за возможность

онлайн бронирования этого ПМ.

В таблице «parking_states» хранится история изменения состояний парковочного места.

Таблица служит для сбора статистических данных. При приходе одинокого состояния с

прошлым новая запись не добавляется, а обновляется поле «updated_at».

Таблица «orders» служит для хранения совершенных заказов пользователей на

бронирование парковочного места. В поле «cost» хранится суммарная стоимость заказа, в поле

«payment» – внесенная сумма пользователем. Поле «booked_time» хранит время в секундах на

сколько было забронировано ПМ, а «end_time» – время окончания брони. При добавлении нового заказа поле «active» по умолчанию устанавливается в значение TRUE, что означает,

что заказ в данный момент активен, а после окончании брони поле «active» устанавливается в

значение FALSE.

### 5.3 Формы интерфейса

Для верстки страниц веб-приложения применялся фреймворк Bootstrap v4.0. Данный

фреймворк имеет множество стилей для множества компонентов, с помощью которых можно

быстро реализовать адаптивный, интерактивный дизайн проекта. Таким образом, используя

данный фреймворк обеспечивается правильное отображение веб-страниц на различных

устройствах.

Также для реализации карты, отображающей парковки, использовался Google Maps

APIs. Данное API очень удобное, имеет хорошую документацию и позволяет реализовывать

интерактивные карты, которые хорошо будут отображаться на различных устройствах.

На рисунке 25 показана главная странице «/», на которой пользователю

предоставляется карта с указанием местоположений парковок в данной области. На карте

синими областями показана территория стоянки, а красными маркерами – парковочные места.

В правой части находится кнопка «Меню» при нажатии на которую выдвигается боковая

панель с элементами управления для фильтрации содержимого карты. Более подробнее о

формах интерфейсов смотри приложение Б.

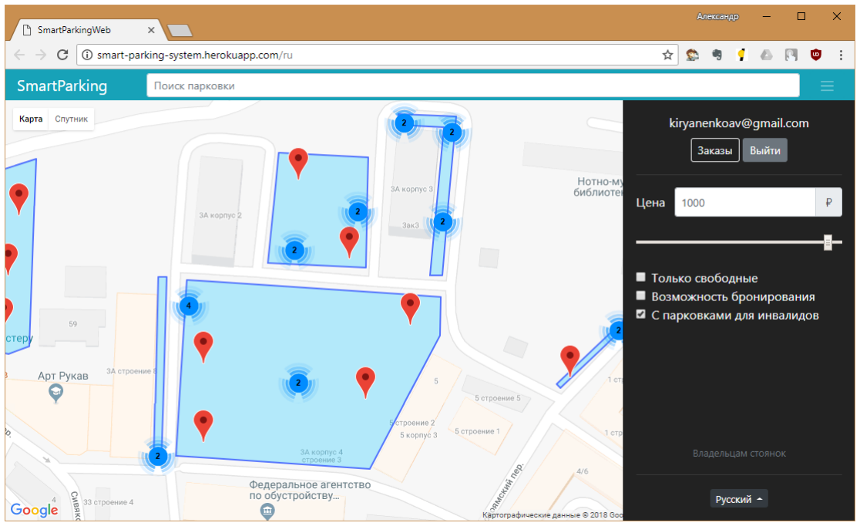
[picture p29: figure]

Рисунок 25 – Главная страница

### 5.4 Алгоритм выдачи парковочных мест

В Ruby on Rails механизм Action Cable с легкостью интегрирует WebSockets с

остальными частями веб-приложения. Он позволяет писать функциональность реального

времени и является производительным и масштабируемым. Он представляет полный стек,

включая клиентский фреймворк на JavaScript и серверный фреймворк на Ruby. Этот механизм

использовался для реализации выдачи в реальном времени состояний парковочных мест на

главной странице «/» веб-приложения.

Веб-клиент на главной странице «/» создаёт WebSocket соединение и подключается к

каналу «MapChannel» и для выдачи парковочных мест в заданной области передаёт

следующие параметры запроса: координаты местоположения, радиус и список фильтров

поиска. Сервер нового клиента подписывает на соответствующий поток (stream), по которому

периодически высылаются состояния парковочных в заданной области.

В БД для оптимизации поиска в таблицах на всех полях, по которым осуществляется

поиск были навешаны соответствующие BTREE индексы. А также для пространственных

координат в таблицах парковочных мест и стоянок были созданы GIST индексы.

Также для оптимизации производительности карта была поделена на взаимно

пересекающиеся квадраты. Число точек, по которым могут быть построены квадраты,

ограничено и размеры самих квадрат также ограничены и определяются, исходя из масштаба,

определяемого по переданному радиусу. Таким образом, количество таких квадратов

ограничено и, следовательно, исчезает уникальность в запросах пользователей, клиентов

можно подписывать на общие потоки и появляется возможность кэширования запросов.

Масштаб s вычисляется по формуле:

s = ceil (log2

2 ∗ rисх

amin

) , | (1)
где, | rисх – радиус из параметра запроса:
| amin – константа, минимальная сторона квадрата, равная 0,01.
| Сторона квадрата a определяется формулой:

a = amin ∗ 2

s
, | (2)

Для расчета координат центра квадрата потребуются промежуточное вычисление xa и

ya – координаты с шагом равным стороне:
{

xa = floor (

xисх
0,5 ∗ a

)

ya = floor (

yисх
0,5 ∗ a

)

, | (3)
где, | xисх и yисх – координаты местоположения из параметра запроса.
| Далее находятся координаты четырёх квадратов xкв, xкв ′ и yкв, yкв

′
вокруг исходных

координат xисх и yисх. И требуется определить координаты x и y квадрата ближайшего к

исходным координатам:

{

x = [
xкв =

a ∗ xa
2

xкв

′ =

a ∗ (xa + 1)
2
y = [
yкв =

a ∗ ya
2

yкв

′ =

a ∗ (ya + 1)
2

(4)

На рисунке 26 приводится схема алгоритма подключения нового клиента к каналу

«MapChannel» для периодической выдачи в реальном времени актуальных данных о

состоянии парковочных мест.

Было проведено нагрузочное тестирование для данного алгоритма: при заполненной

БД (13582 записи) RPS составил 846 запросов в секунду (более подробнее см. Приложение В).

После формирования подписки клиента заданный квадрат добавляется в список

обслуживаемых квадратов. Отдельный поток в бесконечном цикле для каждого квадрата

получает данные о состоянии парковочных мест и рассылает их в соответствующем потоке

(stream). В листинге 2 приводится класса «MapService», который осуществляет данное

действие.

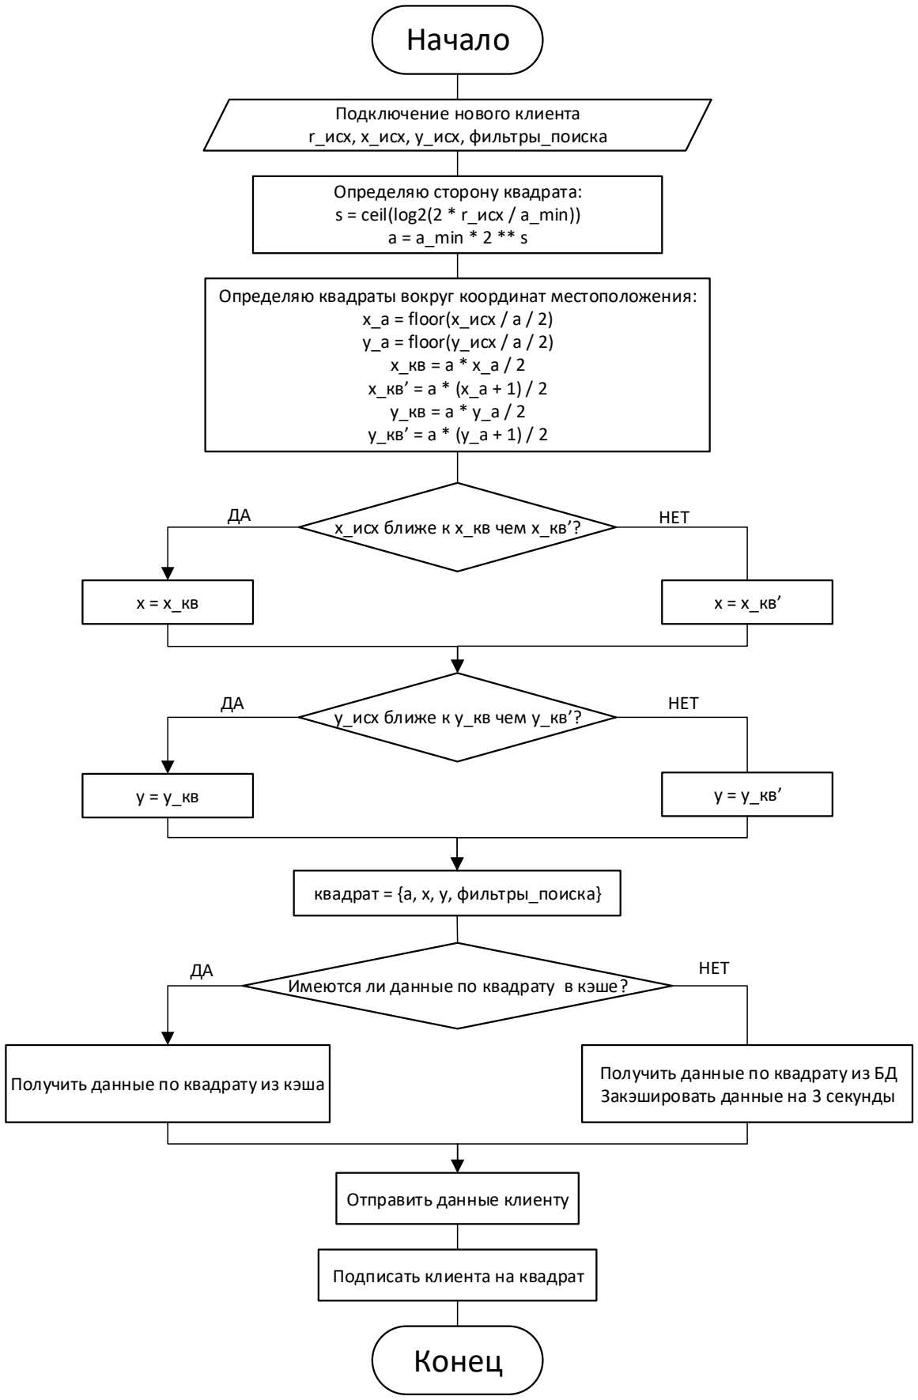
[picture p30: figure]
Начало; Определяю сторону квадрата: s = ceil(log2(2 * r_исх / a_min)) a = a_min * 2 ** s; Подключение нового клиента r_исх, x_исх, y_исх, фильтры_поиска; НЕТ; Определяю квадраты вокруг координат местоположения: x_a = floor(x_исх / a / 2) y_a = floor(y_исх / a / 2) x_кв = a * x_a / 2 x_кв = a * (x_a + 1) / 2 y_кв = a * y_a / 2 y_кв = a * (y_a + 1) / 2; x_исх ближе к x_кв чем x_кв ?; y_исх ближе к y_кв чем y_кв ?; квадрат = {a, x, y, фильтры_поиска}; Имеются ли данные по квадрату в кэше?; Закэшировать данные на 3 секунды; Отправить данные клиенту; Подписать клиента на квадрат; Конец

Получить данные по квадрату из кэша | Получить данные по квадрату из БД

Рисунок 26 – Схема алгоритма подключения нового клиента к каналу «MapChannel»

Листинг 2 – Файл «/app/services/map_service.rb»

require 'singleton'

class MapService
include Singleton

def initialize
@map_clients = Hash.new
@squares = Hash.new
@squares_m = Mutex.new
run
end

def add_square(square)
@squares_m.synchronize do
if @squares.has_key? square.stream sq = @squares[square.stream]
sq[:count] += 1
else
@squares[square.stream] = {square: square, count: 1} end
end
end

def remove_square(square)
@squares_m.synchronize do
sq = @squares[square.stream] sq[:count] -= 1
if sq[:count] <= 0
@squares.delete square.stream end
end
end

private
def run
Thread.new do
loop do
before = Time.now

begin
values = []
@squares_m.synchronize { values = @squares.values.dup } values.each do |value|
value[:square].broadcast
end
ParkingPlace.unset_changed rescue Exception => e
Rails.logger.error e.message Rails.logger.error e.backtrace
end

sleep_time = Rails.configuration.map_sending_period - (Time.now -before)
sleep sleep_time if sleep_time > 0
end
end
end
end

### 5.5 Автоматизация развертывания серверного ПО

Для автоматизации развертывания ПО на боевых серверах используется среда

виртуализации Docker, а также Docker-compose – инструмент для запуска многоконтейнерных

приложений. Docker позволяет «упаковать» приложение со всем его окружением и

зависимостями в контейнер, который может быть перенесён на любую Linux -систему, а также

предоставляет среду по управлению контейнерами. Таким образом, для разворачивания

серверного ПО достаточно чтобы на сервере с ОС семейства Linux были установлены среда

Docker и инструмент Docker-compose.

Ниже (Листинг 3) представлен Dockerfile – файл с инструкцией по разворачиванию

Docker-контейнера веб-приложения Ruby on Rails:

Листинг 3 – Файл «Dockerfile»

FROM ruby:2.3
MAINTAINER Kiryanenko Alexander <KiryanenkoAV@gmail.com>

RUN apt-get update &&\
apt-get install -y \
build-essential \
nodejs \
npm \
postgresql-contrib \
git &&\
npm install yarn -g

RUN mkdir /app
WORKDIR /app

COPY Gemfile ./
RUN bundle install --jobs 20

COPY . .

# Setting env up

ENV RAILS_ENV 'production'
ENV RAKE_ENV 'production'
ENV SECRET_KEY_BASE $(rake secret)

RUN bundle exec rake assets:precompile

EXPOSE 3000

CMD rails db:migrate && bundle exec puma -C config/puma.rb

В файле «docker-compose.yml» (Листинг 4) описываются запускаемые контейнеры: веб-

приложения, СУБД PostgreSQL, СУБД Redis, MQTT-брокера Mosquitto, сервис Memcached и

сервера Nginx.

Листинг 4 – Файл «docker-compose.yml»

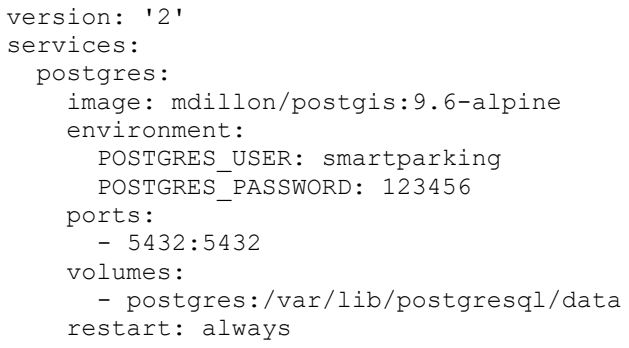
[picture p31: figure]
version: '2' services: postgres: image: mdillon/postgis:9.6-alpine environment: POSTGRES_USER: smartparking POSTGRES_PASSWORD: 123456 ports: - 5432:5432 volumes: - postgres:/var/lib/postgresql/data; restart: always

redis:
image: redis
command: redis-server
ports:
- 6379:6379
volumes:
- redis:/data
restart: always

mqtt:
image: ansi/mosquitto
ports:
- 1883:1883
restart: always

memcached:
image: memcached:alpine
ports:
- 11211:11211

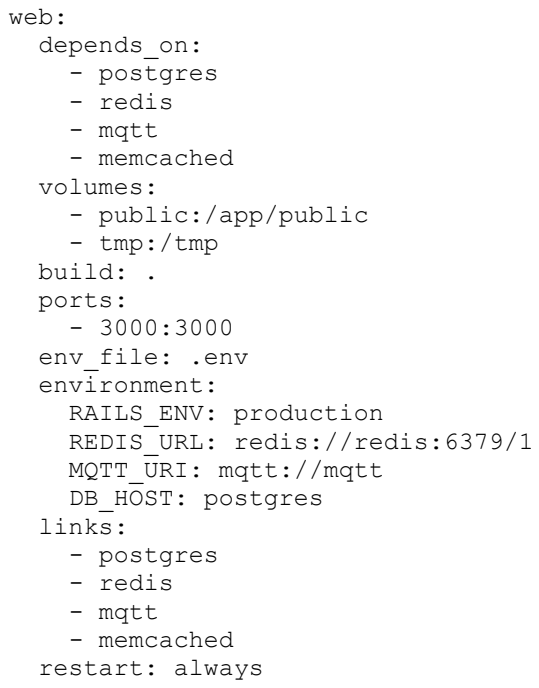
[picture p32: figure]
web: depends_on: - postgres - redis - mqtt - memcached volumes: - public:/app/public - tmp:/tmp build: . ports: - 3000:3000 env_file: .env environment: RAILS_ENV: production REDIS_URL: redis://redis:6379/1 MQTT_URI: mqtt://mqtt; DB_HOST: postgres links: - postgres - redis - mqtt - memcached restart: always

nginx:
image: nginx:alpine
volumes_from:
- web

volumes:
- ./config/nginx.conf.erb:/etc/nginx/nginx.conf
- nginx_logs:/etc/nginx/logs/nginx
depends_on:
- web
ports:
- 80:80
links:
- web
restart: always

volumes:
redis:
postgres:
public:
tmp:
nginx_logs:

Для развертывания серверного ПО достаточно вбить следующую команду:

$ docker-compose up
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

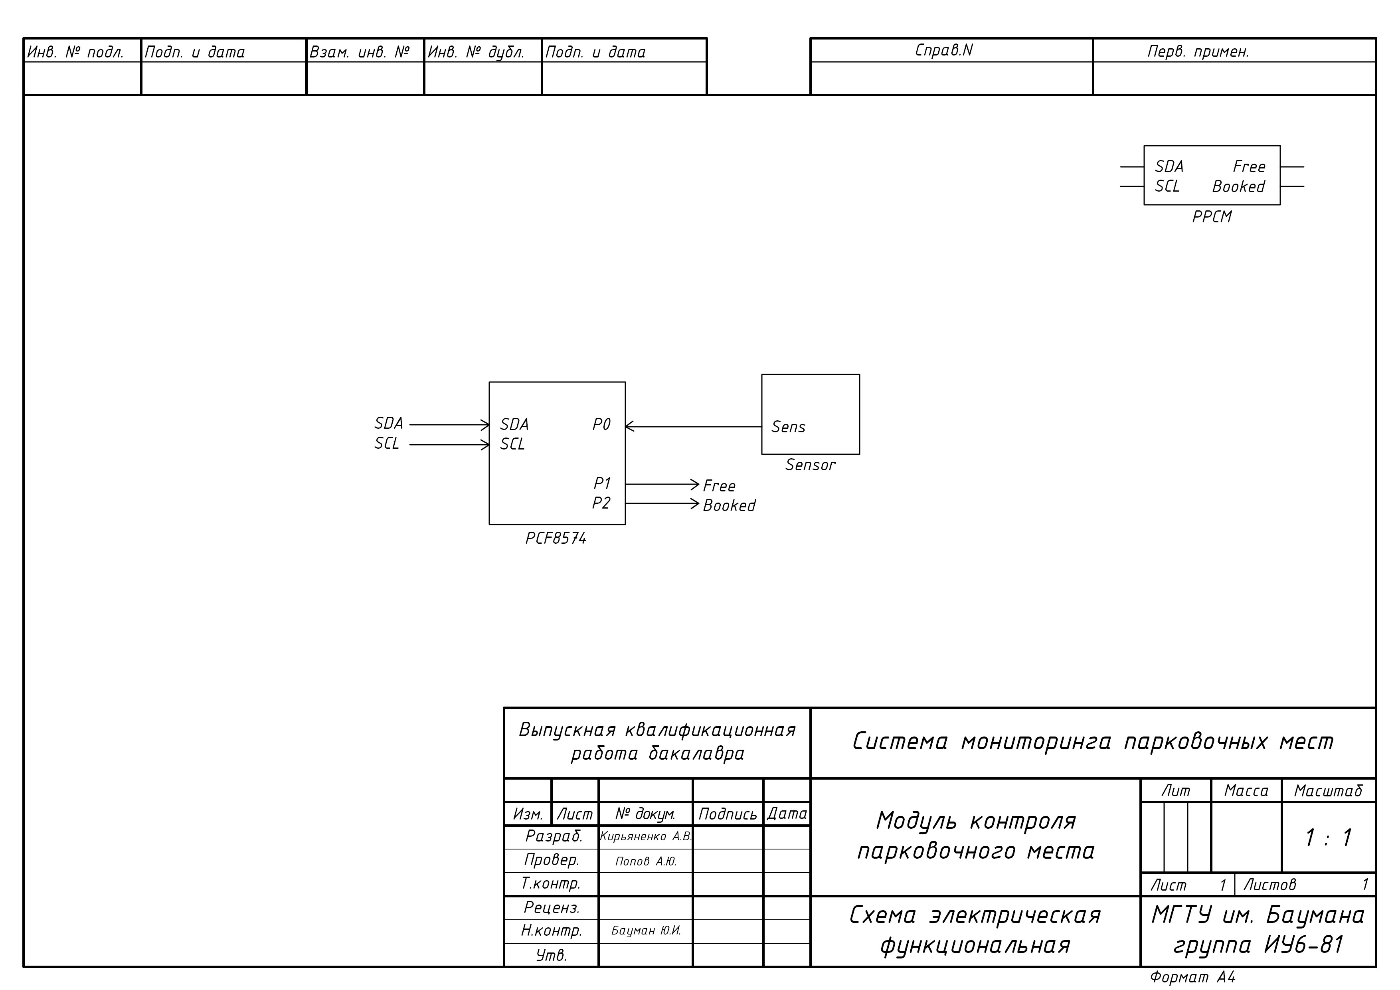
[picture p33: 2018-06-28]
docs/Приложение Е.5. Функциональная схема МКПМ.jpg

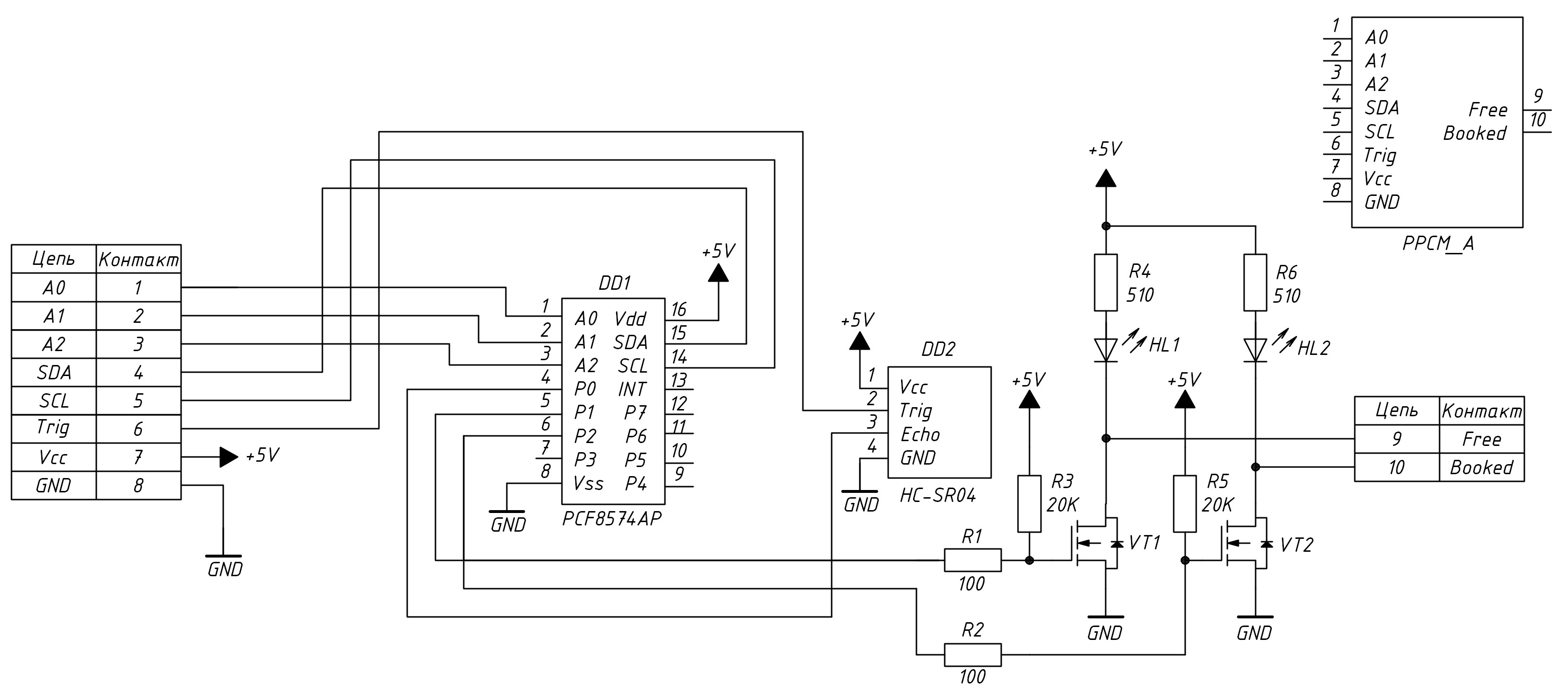
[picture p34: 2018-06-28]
docs/Приложение Е.10. Принципиальная МКПМ_А.jpg

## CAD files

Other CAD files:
docs/Приложение Е.5. Функциональная схема МКПМ.dwg
docs/Приложение Е.13. Принципиальная схема МКПРСПМ.dwg
docs/Приложение Е.6. Функциональная схема МКПРСПМ.dwg
docs/Приложение Е.8. Принципиальная МКПМ.dwg
docs/Приложение Е.10. Принципиальная МКПМ_А.dwg

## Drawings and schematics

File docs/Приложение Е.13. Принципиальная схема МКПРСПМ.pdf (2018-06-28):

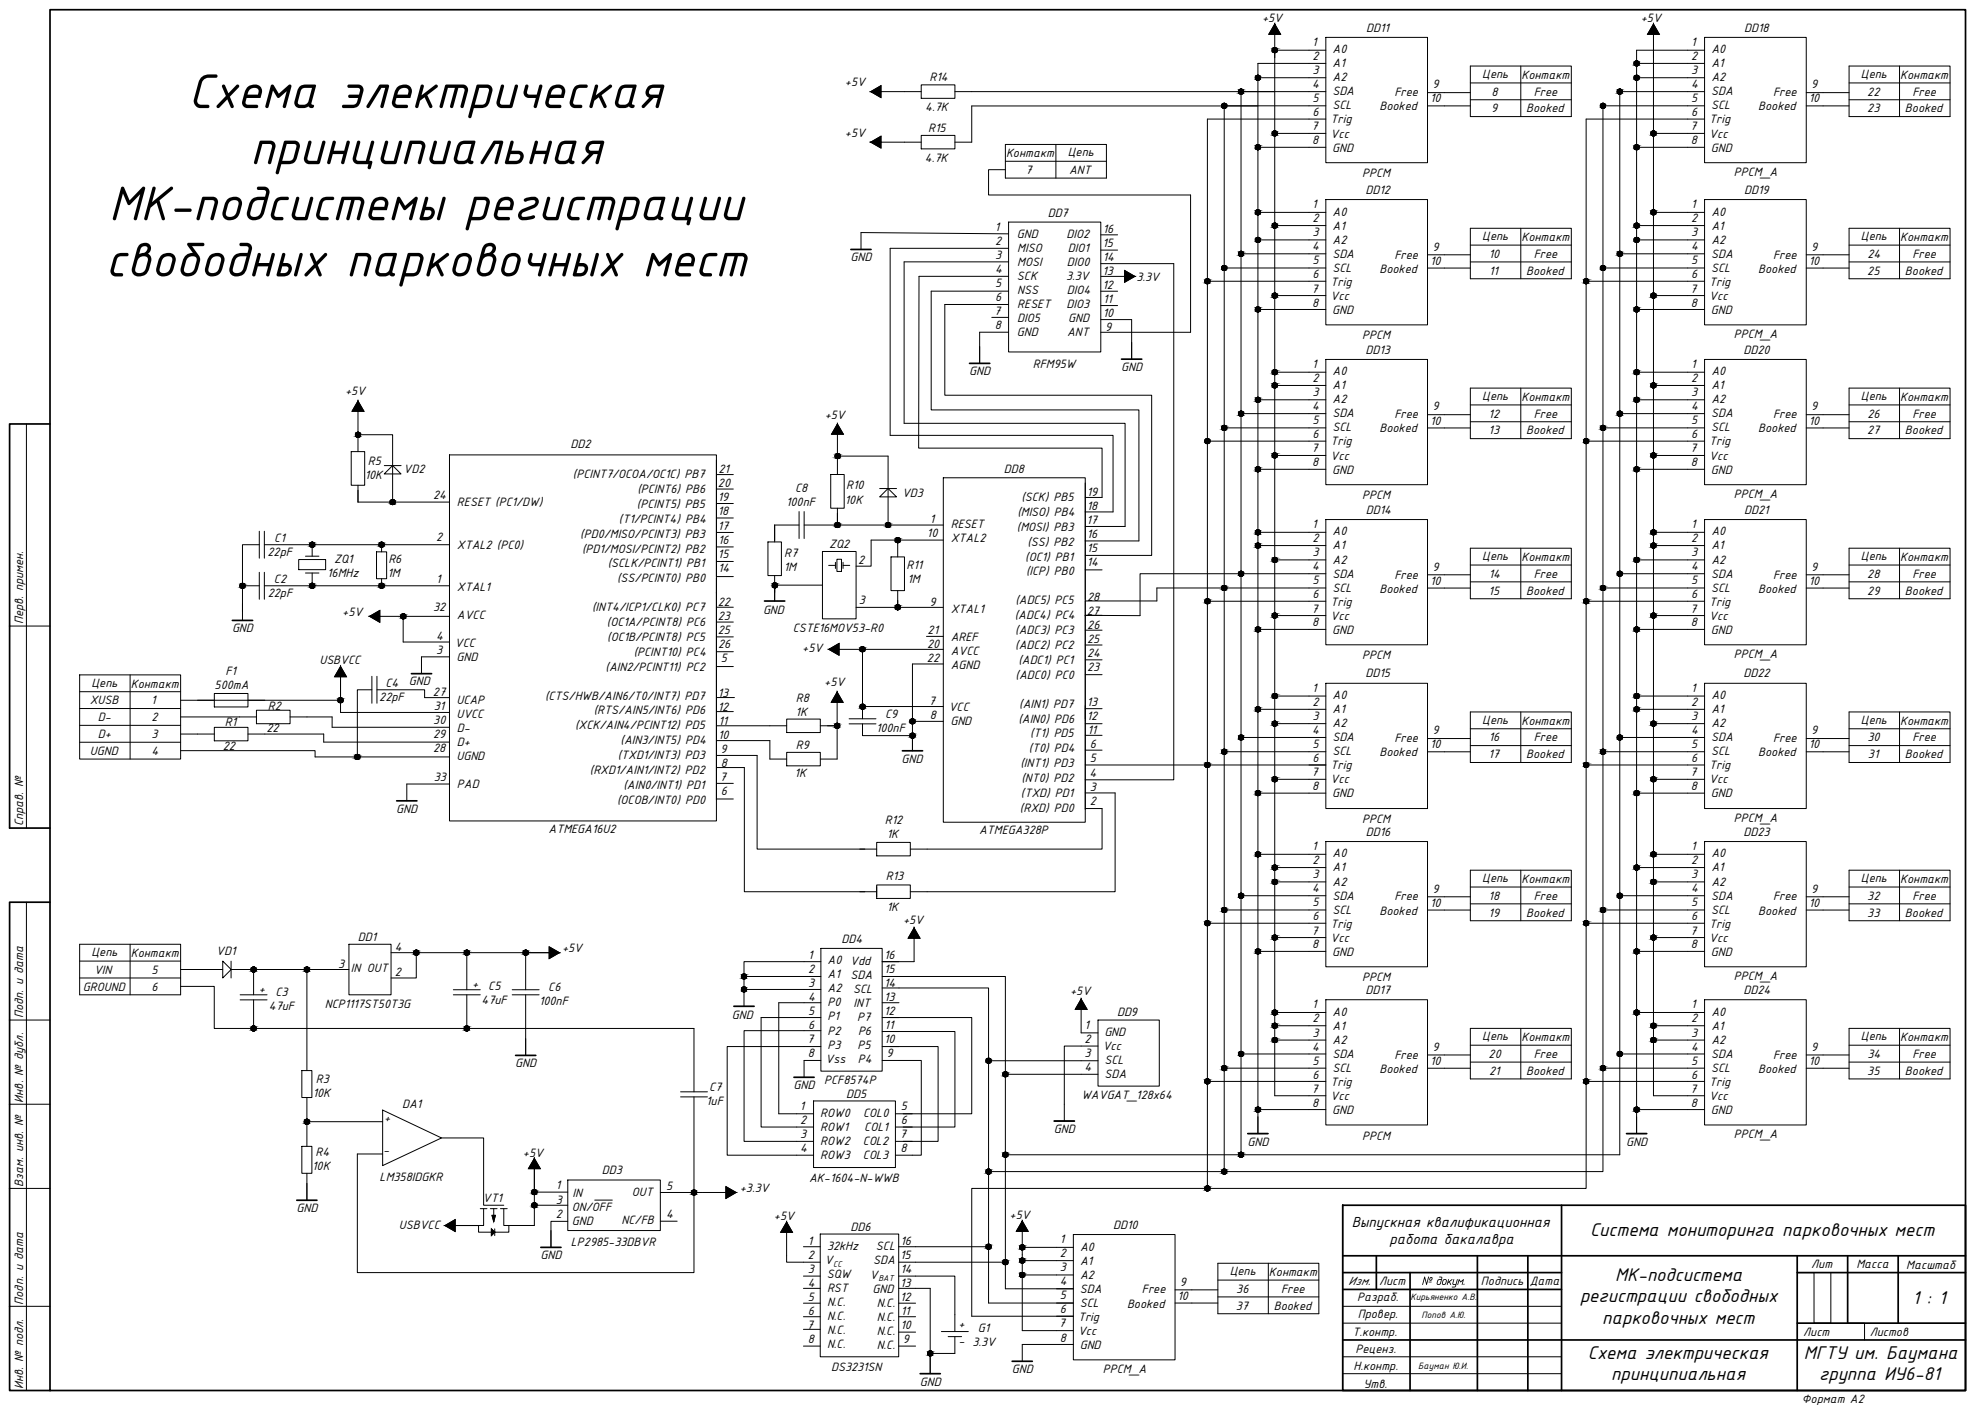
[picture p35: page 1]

Контакт | Цепь

2 | 15
3 | 14

5 | NSS DIO4
6 | RESET DIO3 | 11
7 | DIO5 GND GND ANT | 10

(MISO) PB4 | 18

1 | RESET (MOSI) PB3 | 17

GND Инв. № подл. Подп. и дата Взам. инв. № Инв. № дубл. Подп. и дата Справ. № Перв. примен.

Система мониторинга парковочных мест

36 | Free
37 | | Booked

Т.контр. | | | Лист | Листов
Реценз. | | Схема электрическая принципиальная | МГТУ им. Баумана группа ИУ6-81
Н.контр. | Бауман Ю.И.
Утв.

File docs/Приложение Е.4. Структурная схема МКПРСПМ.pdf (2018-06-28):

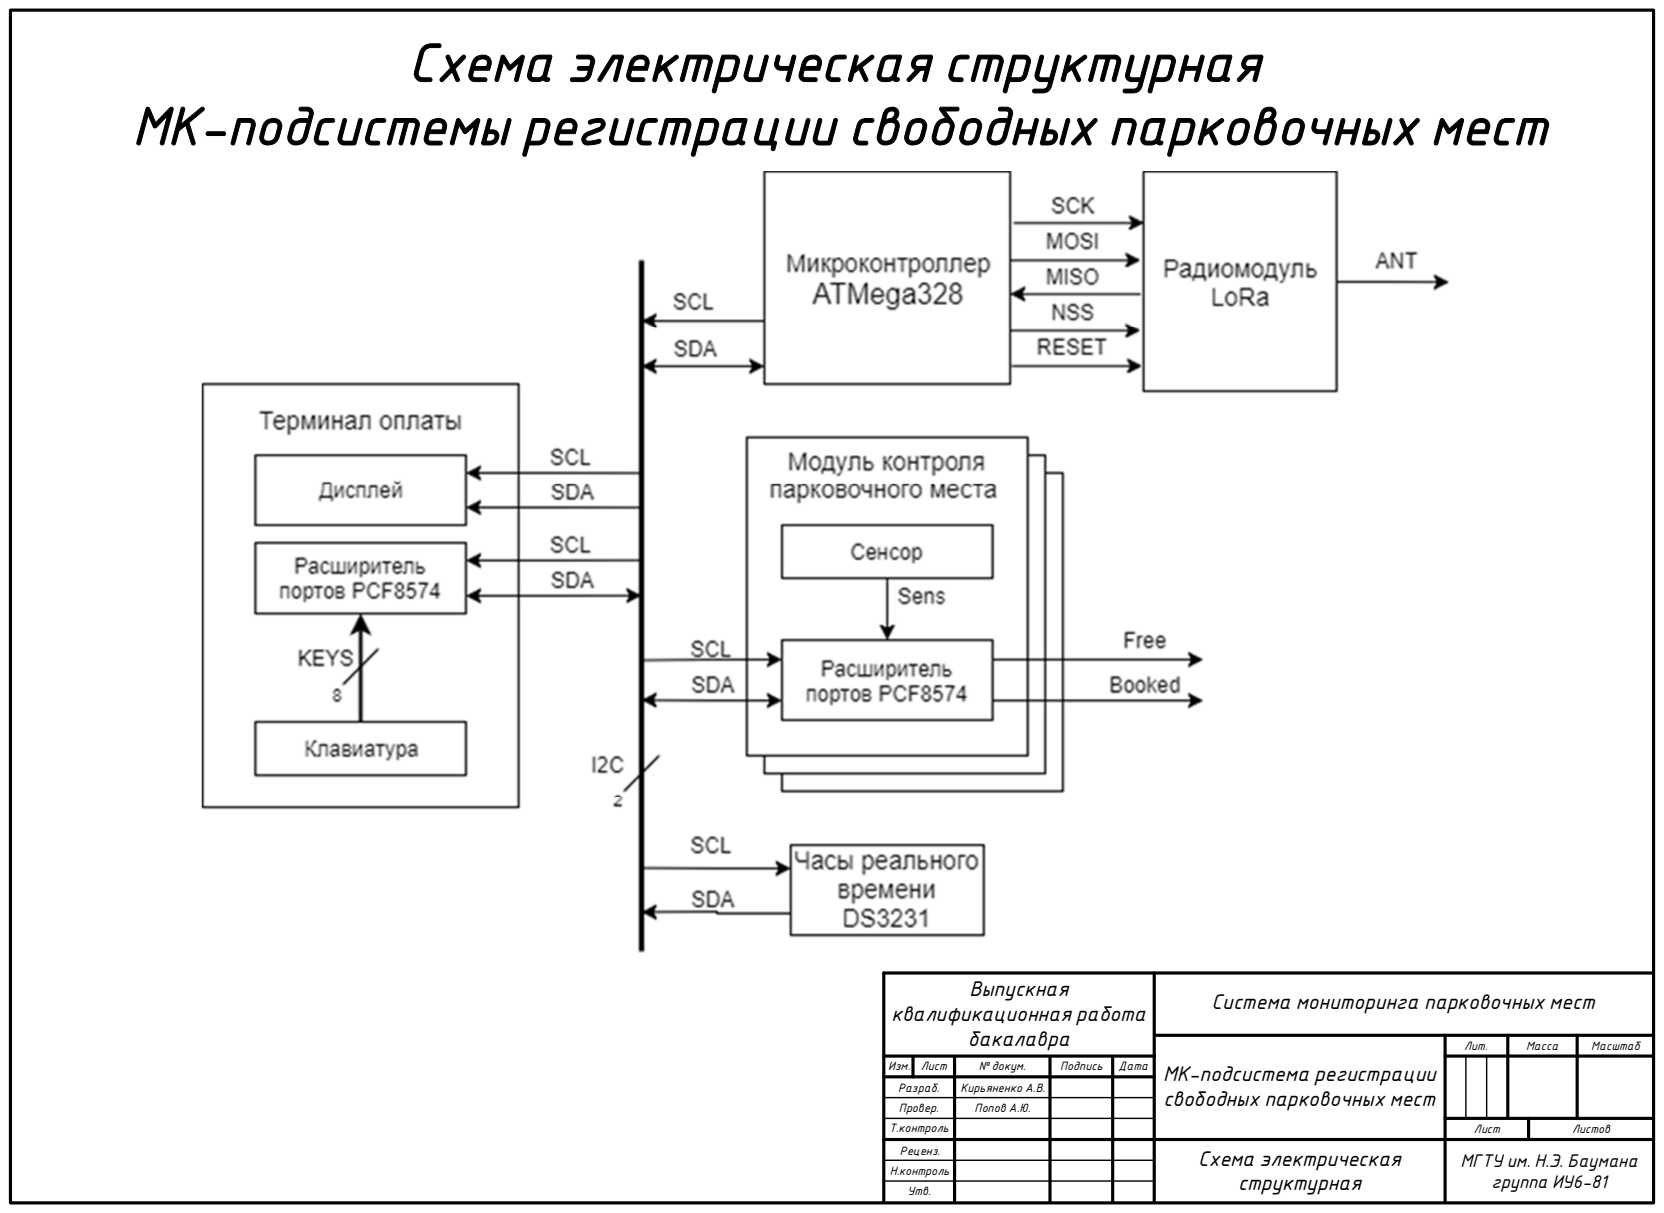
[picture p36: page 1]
Утв.; Лит.; Масса; Масштаб; Листов Лист; Выпускная квалификационная работа бакалавра; Реценз.; МГТУ им. Н.Э. Баумана; группа ИУ6-81; Схема электрическая структурная

Система мониторинга парковочных мест

Изм. | Лист | № докум. | Подпись | Дата

МК-подсистема регистрации
свободных парковочных мест

Разраб. | | Кирьяненко А.В.
Провер. | | Попов А.Ю.
Т.контроль

Н.контроль

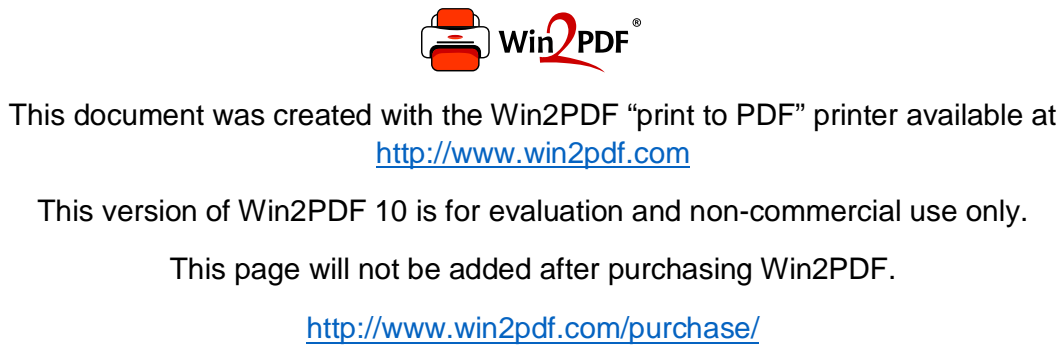
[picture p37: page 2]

This document was created with the Win2PDF “print to PDF” printer available at

http://www.win2pdf.com

This version of Win2PDF 10 is for evaluation and non-commercial use only.

This page will not be added after purchasing Win2PDF.

http://www.win2pdf.com/purchase/

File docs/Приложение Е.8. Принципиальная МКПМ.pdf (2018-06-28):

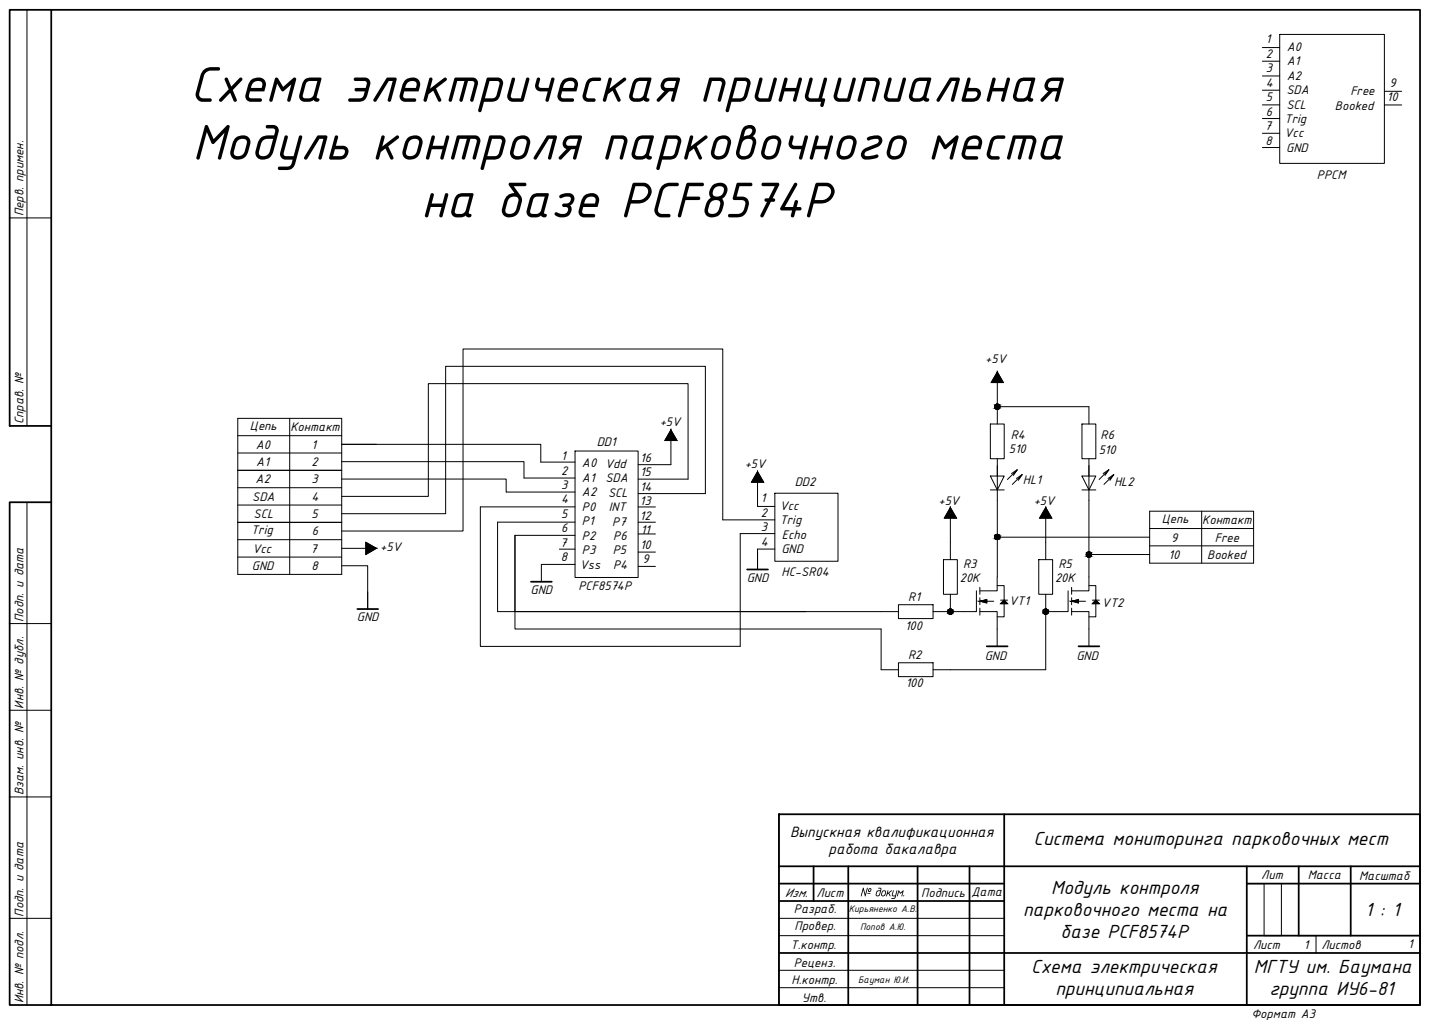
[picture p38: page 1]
Изм.; Лист; № докум.; Подпись; Дата; Лит; Листов Разраб. Провер.; Кирьяненко А.В. Попов А.Ю.; Система мониторинга парковочных мест Схема электрическая принципиальная; Масса; Масштаб 1 : 1 Лист; 1 МГТУ им. Баумана группа ИУ6-81 GND; Vdd SDA SCL INTP7P6P5P4 A0A1 A2 P0P1 P2P3 Vss PCF8574P 12345678; Vcc Trig Echo GND HC-SR04 1234 +5V GND DD1; Цепь 910; Booked Free Контакт +5V; R6 510HL2 R4 510HL1 Цепь; 21 Контакт A0A1 A2; 543 SDA SCL Trig; 876 Vcc GND; GND+5V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

Инв. № подл. Подп. и дата Взам. инв. № Инв. № дубл. Подп. и дата Справ. № Перв. примен. Ф2.104-1а. Формат А3 Схема электрическая принципиальная Модуль контроля парковочного места на базе PCF8574P

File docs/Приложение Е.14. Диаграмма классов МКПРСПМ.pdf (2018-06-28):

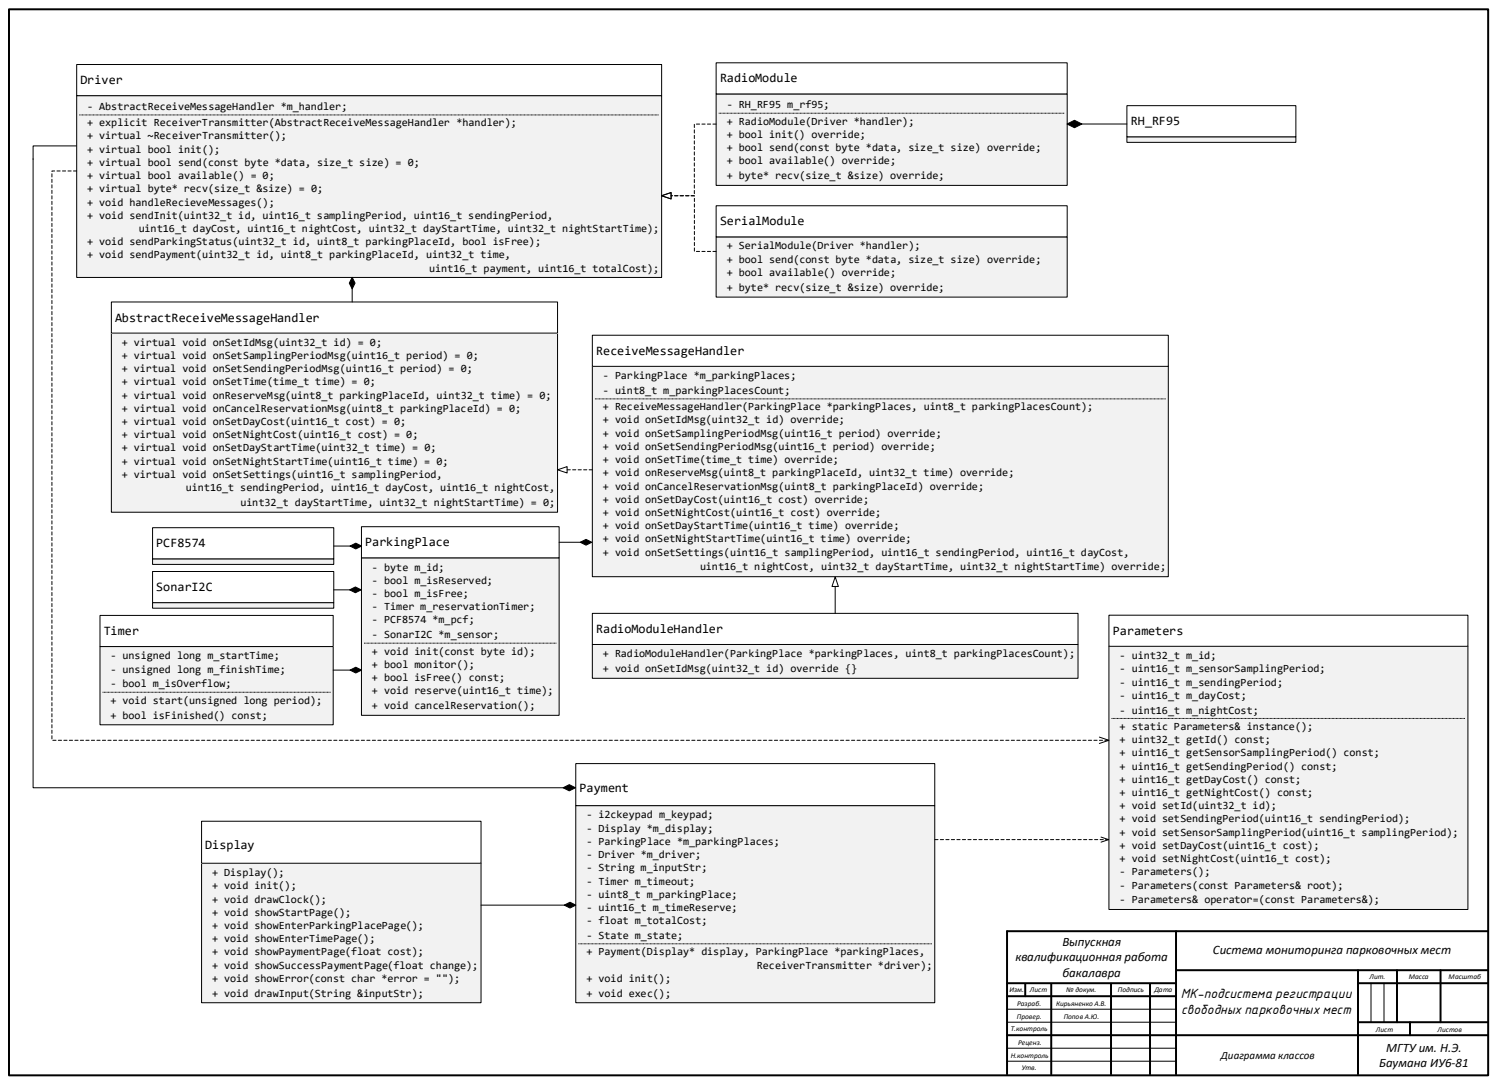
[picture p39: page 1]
Driver; uint16_t payment, uint16_t totalCost);; AbstractReceiveMessageHandler; uint32_t dayStartTime, uint32_t nightStartTime) = 0;; RadioModule; SerialModule; ReceiveMessageHandler; RadioModuleHandler; ParkingPlace; Timer; PCF8574; SonarI2C; Parameters; Payment; - i2ckeypad m_keypad; - Display *m_display; - ParkingPlace *m_parkingPlaces; - Driver *m_driver; - String m_inputStr; - Timer m_timeout; - uint8_t m_parkingPlace; - uint16_t m_timeReserve; - float m_totalCost; - State m_state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

- AbstractReceiveMessageHandler *m_handler;
+ explicit ReceiverTransmitter(AbstractReceiveMessageHandler *handler);
+ virtual ~ReceiverTransmitter();
+ virtual bool init();
+ virtual bool send(const byte *data, size_t size) = 0;
+ virtual bool available() = 0;
+ virtual byte* recv(size_t &size) = 0;
+ void handleRecieveMessages();
+ void sendInit(uint32_t id, uint16_t samplingPeriod, uint16_t sendingPeriod,

+ RadioModule(Driver *handler);
+ bool init() override;
+ bool send(const byte *data, size_t size) override;
+ bool available() override;
+ byte* recv(size_t &size) override;

uint16_t dayCost, uint16_t nightCost, uint32_t dayStartTime, uint32_t nightStartTime);

+ void sendParkingStatus(uint32_t id, uint8_t parkingPlaceId, bool isFree);
+ void sendPayment(uint32_t id, uint8_t parkingPlaceId, uint32_t time,

+ SerialModule(Driver *handler);

+ virtual void onSetIdMsg(uint32_t id) = 0;
+ virtual void onSetSamplingPeriodMsg(uint16_t period) = 0;
+ virtual void onSetSendingPeriodMsg(uint16_t period) = 0;
+ virtual void onSetTime(time_t time) = 0;
+ virtual void onReserveMsg(uint8_t parkingPlaceId, uint32_t time) = 0;
+ virtual void onCancelReservationMsg(uint8_t parkingPlaceId) = 0;
+ virtual void onSetDayCost(uint16_t cost) = 0;
+ virtual void onSetNightCost(uint16_t cost) = 0;
+ virtual void onSetDayStartTime(uint32_t time) = 0;
+ virtual void onSetNightStartTime(uint16_t time) = 0;
+ virtual void onSetSettings(uint16_t samplingPeriod,

- ParkingPlace *m_parkingPlaces;
- uint8_t m_parkingPlacesCount;
+ ReceiveMessageHandler(ParkingPlace *parkingPlaces, uint8_t parkingPlacesCount);
+ void onSetIdMsg(uint32_t id) override;
+ void onSetSamplingPeriodMsg(uint16_t period) override;
+ void onSetSendingPeriodMsg(uint16_t period) override;
+ void onSetTime(time_t time) override;
+ void onReserveMsg(uint8_t parkingPlaceId, uint32_t time) override;
+ void onCancelReservationMsg(uint8_t parkingPlaceId) override;
+ void onSetDayCost(uint16_t cost) override;
+ void onSetNightCost(uint16_t cost) override;
+ void onSetDayStartTime(uint16_t time) override;
+ void onSetNightStartTime(uint16_t time) override;
+ void onSetSettings(uint16_t samplingPeriod, uint16_t sendingPeriod, uint16_t dayCost,

uint16_t sendingPeriod, uint16_t dayCost, uint16_t nightCost,

- byte m_id;
- bool m_isReserved;
- bool m_isFree;
- Timer m_reservationTimer;
- PCF8574 *m_pcf;
- SonarI2C *m_sensor;
+ void init(const byte id);
+ bool monitor();
+ bool isFree() const;
+ void reserve(uint16_t time);
+ void cancelReservation();

uint16_t nightCost, uint32_t dayStartTime, uint32_t nightStartTime) override;

- unsigned long m_startTime;
- unsigned long m_finishTime;
- bool m_isOverflow;
+ void start(unsigned long period);
+ bool isFinished() const;

+ RadioModuleHandler(ParkingPlace *parkingPlaces, uint8_t parkingPlacesCount);
+ void onSetIdMsg(uint32_t id) override {}

- uint32_t m_id;
- uint16_t m_sensorSamplingPeriod;
- uint16_t m_sendingPeriod;
- uint16_t m_dayCost;
- uint16_t m_nightCost;
+ static Parameters& instance();
+ uint32_t getId() const;
+ uint16_t getSensorSamplingPeriod() const;
+ uint16_t getSendingPeriod() const;
+ uint16_t getDayCost() const;
+ uint16_t getNightCost() const;
+ void setId(uint32_t id);
+ void setSendingPeriod(uint16_t sendingPeriod);
+ void setSensorSamplingPeriod(uint16_t samplingPeriod);
+ void setDayCost(uint16_t cost);
+ void setNightCost(uint16_t cost);
- Parameters();
- Parameters(const Parameters& root);
- Parameters& operator=(const Parameters&);

+ Display();
+ void init();
+ void drawClock();
+ void showStartPage();
+ void showEnterParkingPlacePage();
+ void showEnterTimePage();
+ void showPaymentPage(float cost);
+ void showSuccessPaymentPage(float change);
+ void showError(const char *error = "");
+ void drawInput(String &inputStr);

Система мониторинга парковочных мест

Изм. | Лист | докум. | Подпись | Дата
Разраб. | | Кирьяненко А.В.
Провер. | | Попов А.Ю.
Т.контроль
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

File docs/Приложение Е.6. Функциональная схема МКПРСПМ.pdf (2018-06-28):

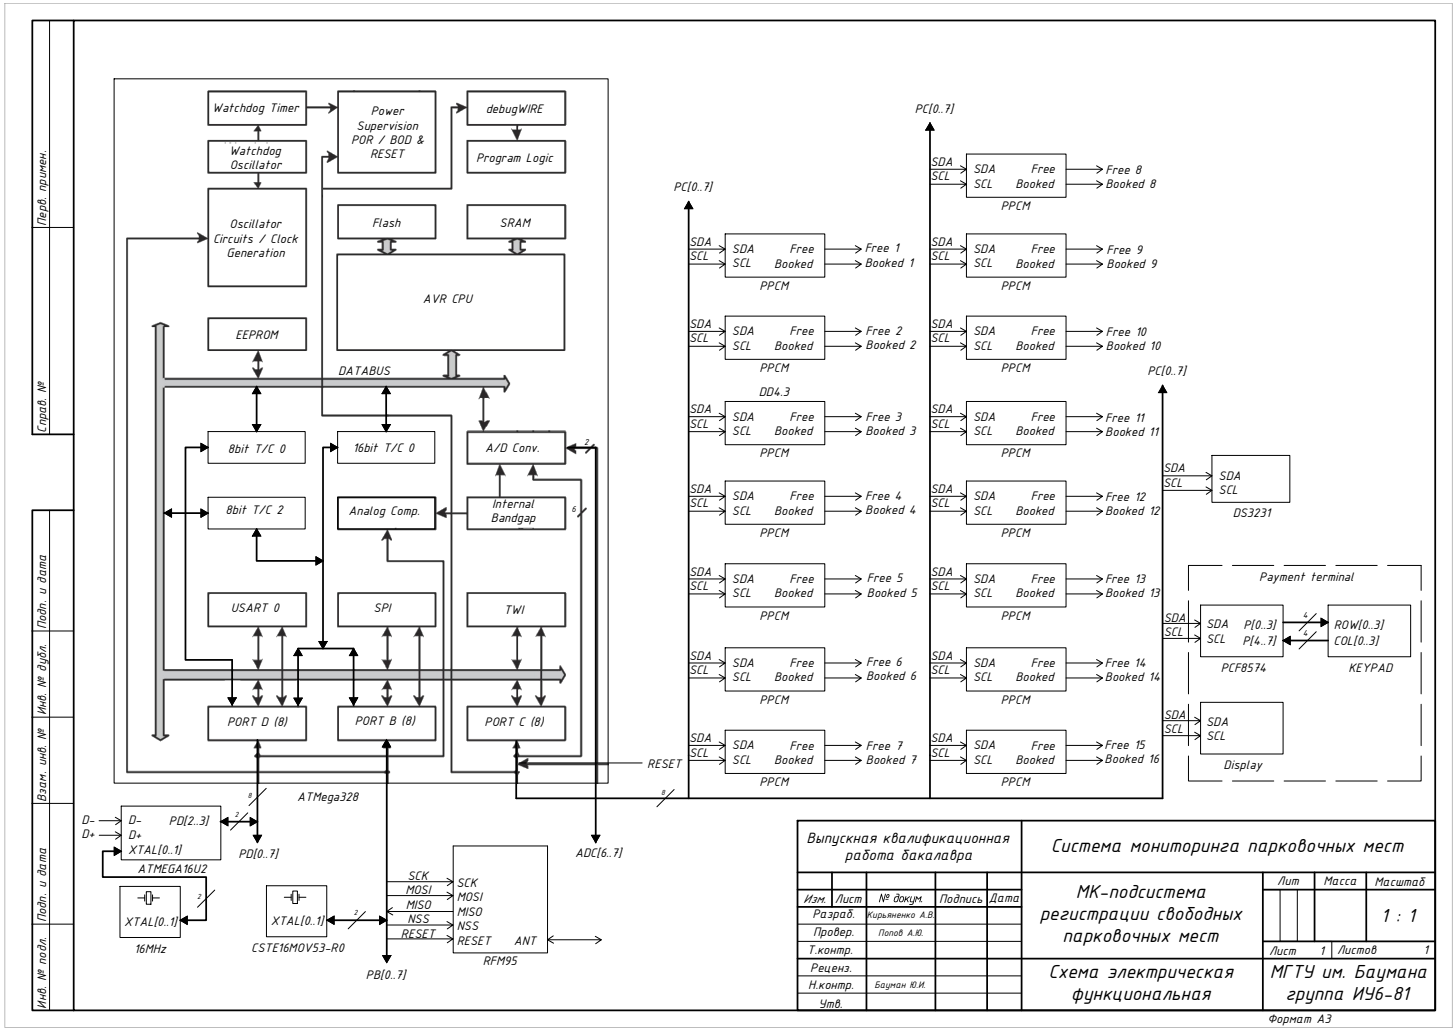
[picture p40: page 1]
Изм.; Лист; № докум.; Подпись; Дата; Лит; Листов Разраб. Провер.; Кирьяненко А.В. Попов А.Ю.; Схема электрическая функциональная; Масса; Масштаб 1 : 1 Лист; 1 МГТУ им. Баумана группа ИУ6-81 ANT SCK MOSI MISO NSS RESETRFM95 Watchdog Timer Watchdog Oscillator Oscillator Circuits / Clock Generation; Power Supervision POR / BOD & RESET; debugWIRE Program Logic Flash; SRAM AVR CPU EEPROM 8bit T/C 0; 16bit T/C 0; A/D Conv. 8bit T/C 2; Analog Comp.; Internal Bandgap USART 0; SPI; TWI PORT D (8)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

Инв. № подл. Подп. и дата Взам. инв. № Инв. № дубл. Подп. и дата Справ. № Перв. примен. А4 А2 А1 А0 Ф2.104-1а. Free Booked SDA SCL PPCM SDA SCL Free Booked SDA SCL PPCM SDA SCL Free Booked SDA SCL PPCM SDA SCL Free Booked SDA SCL DD4.3 PPCM SDA SCL Free Booked SDA SCL PPCM SDA SCL Free Booked SDA SCL PPCM SDA SCL PС[0..7] Free Booked SDA SCL PPCM SDA SCL Free Booked SDA SCL PPCM SDA SCL Free Booked SDA SCL PPCM SDA SCL Free Booked SDA SCL PPCM SDA SCL Free Booked SDA SCL PPCM SDA SCL Free Booked SDA SCL PPCM SDA SCL Free Booked SDA SCL PPCM SDA SCL Free Booked SDA SCL PPCM SDA SCL PС[0..7] SDA SCL SDA SCL SDA SCL SDA SCL KEYPAD ROW[0..3] COL[0..3] 4 8 2 2 8 DATABUS D-D+ Free 7 Booked 7 Free 6 Booked 6 Free 5 Booked 5 Free 4 Booked 4 Free 3 Booked 3 Free 2 Booked 2 Free 1 Booked 1 Free 15 Booked 16 Free 14 Booked 14 Free 13 Booked 13 Free 12 Booked 12 Free 11 Booked 11 Free 10 Booked 10 Free 9 Booked 9 Free 8 Booked 8 МК-подсистема регистрации свободных парковочных мест Система мониторинга парковочных мест XTAL[0..1] 16MHz 2 Т.контр. Н.контр. Утв. Бауман Ю.И. Выпускная квалификационная работа бакалавра Формат А3 Реценз.

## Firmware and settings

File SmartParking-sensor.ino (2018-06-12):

#include <Wire.h>
#include <PCF8574.h>
#include <SonarI2C.h>
#include <SPI.h>
#include <RadioHead\RH_RF95.h>
#include <Arduino-EEPROMEx\EEPROMex.h>
#include <Time\TimeLib.h>
#include <Time.h>
#include <DS3232RTC.h>
#include <i2ckeypad.h>
#include <ASOLED.h>
#include <DS3232RTC.h>
#include "MemUtils.h"
#include "ParkingPlace.h"
#include "Driver.h"
#include "SerialModule.h"
#include "RadioModule.h"
#include "Parameters.h"
#include "ReceiveMessageHandler.h"
#include "RadioModuleHandler.h"
#include "Display.h"
#include "Payment.h"


// Singleton instances
Driver *driver;
ParkingPlace parkingPalces[PARKING_PLACES_COUNT];
Parameters &parameters = Parameters::instance();
SerialModule serialModule(new ReceiveMessageHandler(parkingPalces, PARKING_PLACES_COUNT));
Display display;
Payment *payment;


void setup()
{
	Serial.begin(9600);

#ifdef DEBUG
	// Установка параметров и запись их в память
	parameters.setId(1);
	parameters.setSendingPeriod(2000);
	parameters.setSensorSamplingPeriod(200);

    parameters.setDayCost(200);
    parameters.setNightCost(100);
    parameters.setDayStartTime(21600);      // 06:00
    parameters.setNightStartTime(82800);    // 23:00
#endif

/* #ifdef DEBUG
    // Установка даты и времени
    tmElements_t tm;
    tm.Year = CalendarYrToTm(2017);
    tm.Month = 12;
    tm.Day = 27;
    tm.Hour = 0;
    tm.Minute = 33;
    tm.Second = 0;
    RTC.set(makeTime(tm));
#endif // DEBUG */

    setSyncProvider(RTC.get);

	RadioModule *radioModule = new RadioModule(
		PIN_RESET_LORA, 
		parameters.getSendingPeriod() / PARKING_PLACES_COUNT, 
		new RadioModuleHandler(parkingPalces, PARKING_PLACES_COUNT)
	);
	if (radioModule->init()) {
		driver = radioModule;
		Serial.println(F("[INFO] RF95 init success!"));
	} else {
		Serial.println(F("[WARN] RF95 init failed!"));
		delete radioModule;
		driver = &serialModule;
		Serial.println(F("[INFO] Serial module init success!"));
	}
	
	SonarI2C::begin(PIN_INT_SONAR);
	for (int i = 0; i < PARKING_PLACES_COUNT; ++i) {
		parkingPalces[i].init(i + 1);
	}

    display.init();

    payment = new Payment(&display, parkingPalces, driver);
    payment->init();

	delay(300);
	driver->sendInit(
        parameters.getId(),
        parameters.getSensorSamplingPeriod(),
        parameters.getSendingPeriod(),
        parameters.getDayCost(),
        parameters.getNightCost(),
        parameters.getDayStartTime(),
        parameters.getNightStartTime()
    );
}

void loop()
{
	SonarI2C::doSonar();  // call every cycle, SonarI2C handles the spacing
	static Timer sendingPeriod;
	for (byte i = 0; i < PARKING_PLACES_COUNT; ++i) {
		if (parkingPalces[i].monitor() || sendingPeriod.isFinished()) {
            sendingPeriod.start(parameters.getSendingPeriod());
			driver->sendParkingStatus(parameters.getId(), i + 1, parkingPalces[i].isFree());
		}
	}
	driver->handleRecieveMessages();
	serialModule.handleRecieveMessages();

    payment->exec();
    
    static Timer sec;
    if (sec.isFinished()) {
        sec.start(1000);
        display.drawClock();
    }

	delay(parameters.getSensorSamplingPeriod());
}

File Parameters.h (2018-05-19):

#pragma once

#include <Arduino-EEPROMEx\EEPROMex.h>

#define PARKING_PLACES_COUNT 1
#define PIN_RESET_LORA 9
#define PIN_INT_SONAR 3

#define KEYPAD_I2C_ADDR 0x20
#define KEYPAD_ROWS 4
#define KEYPAD_COLS 4

#define TIMEOUT 120000
#define MSG_SHOW_TIME 5000

#define DEBUG


class Parameters
{
    uint32_t m_id; // Идентификатор устройства
    uint16_t m_sensorSamplingPeriod; // Период опроса датчиков
    uint16_t m_sendingPeriod; // Период отправки сообщений

    uint16_t m_dayCost; // Дневная тариф
    uint16_t m_nightCost; // Ночная ториф
    uint32_t m_dayStartTime; // Время (количество сек с 00:00) со скольки включается дневной тариф
    uint32_t m_nightStartTime; // Время (количество сек с 00:00) со скольки включается ночной тариф

    const int adress_id = 0;
    const int adress_sensor_sampling_period = adress_id + sizeof(m_id);
    const int adress_sending_period = adress_sensor_sampling_period + sizeof(m_sensorSamplingPeriod);

    const int adress_day_cost = adress_sending_period + sizeof(m_sendingPeriod);
    const int adress_night_cost = adress_day_cost + sizeof(m_dayCost);
    const int adress_day_start_time = adress_night_cost + sizeof(m_nightCost);
    const int adress_night_start_time = adress_day_start_time + sizeof(m_dayStartTime);

public:
    static Parameters& instance();

    uint32_t getId() const;
    uint16_t getSensorSamplingPeriod() const;
    uint16_t getSendingPeriod() const;

    uint16_t getDayCost() const;
    uint16_t getNightCost() const;
    uint32_t getDayStartTime() const;
    uint32_t getNightStartTime() const;

    void setId(uint32_t id);
    void setSendingPeriod(uint16_t sendingPeriod);
    void setSensorSamplingPeriod(uint16_t samplingPeriod);

    void setDayCost(uint16_t cost);
    void setNightCost(uint16_t cost);
    void setDayStartTime(uint32_t time);
    void setNightStartTime(uint32_t time);

private:
    Parameters();
    Parameters(const Parameters& root);
    Parameters& operator=(const Parameters&);

    template <typename T>
    void save(T &field, const T &data, int adress);
};

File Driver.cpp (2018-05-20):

#include "Driver.h"
#include "MemUtils.h"
#include "Parameters.h"

Driver::Driver(AbstractReceiveMessageHandler *handler)
{
	m_handler = handler;
}


Driver::~Driver()
{
}

bool Driver::init()
{
	return true;
}


void Driver::handleRecieveMessages()
{
	while (available()) {
		size_t msgSize;
		const byte *msg = recv(msgSize);
		if (msg) {
#ifdef DEBUG
			Serial.print(F("[DEBUG] Recv msg[")); Serial.print(msgSize); Serial.print(F("]: "));
			for (size_t i = 0; i < msgSize; ++i) {
				Serial.print(msg[i]);
				Serial.print(' ');
			}
			Serial.println();
#endif
            const auto type = msg[0];
			const auto id = getReverseData<uint32_t>(msg + sizeof type);
			if (id == Parameters::instance().getId()) {
				size_t headerSize = sizeof id + sizeof type;
				size_t bodySize = msgSize - headerSize;
				auto body = msg + headerSize;

#ifdef DEBUG
				Serial.print(F("[DEBUG] Recv msg type = "));
				Serial.print(type);
				Serial.print(F("; bodySize = "));
				Serial.println(bodySize);
#endif

				if (type == type_of_recv_msg_set_id) {
					handleRecvMsgSetId(body, bodySize);
				} else if (type == type_of_recv_msg_set_sensor_sampling_period) {
					handleRecvMsgSetSamplingPeriod(body, bodySize);
				} else if (type == type_of_recv_msg_set_sending_period) {
					handleRecvMsgSetSendingPeriod(body, bodySize);
                } else if (type == type_of_recv_msg_set_time) {
                    handleRecvMsgSetTime(body, bodySize);
				} else if (type == type_of_recv_msg_reserve) {
					handleRecvMsgReserve(body, bodySize);
				} else if (type == type_of_recv_msg_cancel_reservation) {
					handleRecvMsgCancelReservation(body, bodySize);
				} else if (type == type_of_recv_msg_set_day_cost) {
					handleRecvMsgSetDayCost(body, bodySize);
				} else if (type == type_of_recv_msg_set_night_cost) {
					handleRecvMsgSetNightCost(body, bodySize);
				} else if (type == type_of_recv_msg_set_day_start_time) {
                    handleRecvMsgSetDayStartTime(body, bodySize);
				} else if (type == type_of_recv_msg_set_night_start_time) {
                    handleRecvMsgSetNightStartTime(body, bodySize);
				} else if (type == type_of_recv_msg_set_settings) {
                    handleRecvMsgSetSettings(body, bodySize);
				} else {
#ifdef DEBUG
                    Serial.print(F("[ERROR] Undefined msg type: "));
                    Serial.println(type);
#endif				
				}

                if (type == type_of_recv_msg_set_sensor_sampling_period ||
                    type == type_of_recv_msg_set_sending_period ||
                    type == type_of_recv_msg_set_time ||
                    type == type_of_recv_msg_set_day_cost ||
                    type == type_of_recv_msg_set_night_cost ||
                    type == type_of_recv_msg_set_day_start_time ||
                    type == type_of_recv_msg_set_night_start_time ||
                    type == type_of_recv_msg_set_settings) {
                    auto& parameters = Parameters::instance();
                    sendInit(
                        parameters.getId(),
                        parameters.getSensorSamplingPeriod(),
                        parameters.getSendingPeriod(),
                        parameters.getDayCost(),
                        parameters.getNightCost(),
                        parameters.getDayStartTime(),
                        parameters.getNightStartTime()
                    );
                }
			} else {
#ifdef DEBUG
				Serial.print(F("[DEBUG] Msg for other sensor with id = "));
				Serial.println(id);
#endif
			}
			delete[] msg;
		}
	}
}


void Driver::sendInit(
    const uint32_t id,
    const uint16_t samplingPeriod,
    const uint16_t sendingPeriod,
    const uint16_t dayCost,
    const uint16_t nightCost,
    const uint32_t dayStartTime,
    const uint32_t nightStartTime)
{
#ifdef DEBUG
	Serial.print(F("[SEND] "));
	Serial.print(type_of_send_msg_init); Serial.print(' ');
    Serial.print(id); Serial.print(' ');
    Serial.print(samplingPeriod); Serial.print(' ');
    Serial.print(sendingPeriod); Serial.print(' ');
    Serial.print(dayCost); Serial.print(' ');
    Serial.print(nightCost); Serial.print(' ');
    Serial.print(dayStartTime); Serial.print(' ');
	Serial.println(nightStartTime);
#endif

	size_t bufSize;
	const auto data = dataToSendInit(
        id, 
        samplingPeriod,
        sendingPeriod,
        dayCost,
        nightCost,
        dayStartTime,
        nightStartTime,
        bufSize);
	send(data, bufSize);
	delete[] data;
}


void Driver::sendParkingStatus(const uint32_t id, const uint8_t parkingPlaceId, const bool isFree)
{
#ifdef DEBUG
	Serial.print(F("[SEND] "));
	Serial.print(type_of_send_msg_parking_status);
	Serial.print(' ');
	Serial.print(id);
	Serial.print(' ');
	Serial.print(parkingPlaceId);
	Serial.print(' ');
	Serial.println(isFree);
#endif

	size_t bufSize;
	const auto data = dataToSendParkingStatus(id, parkingPlaceId, isFree, bufSize);
	send(data, bufSize);
	delete[] data;
}

void Driver::sendPayment(
    const uint32_t id, 
    const uint8_t parkingPlaceId, 
    const uint32_t time,
    const uint16_t payment,
    const uint16_t totalCost)
{
#ifdef DEBUG
    Serial.print(F("[SEND] "));
    Serial.print(type_of_send_msg_payment);
    Serial.print(' ');
    Serial.print(id);
    Serial.print(' ');
    Serial.print(parkingPlaceId);
    Serial.print(' ');
    Serial.println(time);
    Serial.print(' ');
    Serial.println(totalCost);
#endif

    size_t bufSize;
    const auto data = dataToSendPayment(id, parkingPlaceId, time, payment, totalCost,  bufSize);
    send(data, bufSize);
    delete[] data;
}


const byte* Driver::dataToSendInit(
    const uint32_t id,
    const uint16_t samplingPeriod,
    const uint16_t sendingPeriod,
    const uint16_t dayCost,
    const uint16_t nightCost,
    const uint32_t dayStartTime,
    const uint32_t nightStartTime, 
    size_t &bufSize) const
{
	bufSize = 1 + 4 + 2 + 2 + 2 + 2 + 4 + 4;
	const auto dataToSend = new byte[bufSize];
	cpyReverseData(dataToSend, type_of_send_msg_init);
	cpyReverseData(dataToSend + 1, id);
    cpyReverseData(dataToSend + 1 + 4, samplingPeriod);
    cpyReverseData(dataToSend + 1 + 4 + 2, sendingPeriod);
    cpyReverseData(dataToSend + 1 + 4 + 2 + 2, dayCost);
    cpyReverseData(dataToSend + 1 + 4 + 2 + 2 + 2, nightCost);
    cpyReverseData(dataToSend + 1 + 4 + 2 + 2 + 2 + 2, dayStartTime);
    cpyReverseData(dataToSend + 1 + 4 + 2 + 2 + 2 + 2 + 4, nightStartTime);
	return dataToSend;
}

const byte* Driver::dataToSendParkingStatus(
    const uint32_t id, 
    const uint8_t parkingPlaceId, 
    const bool isFree,
    size_t& bufSize) const
{
	bufSize = 1 + 4 + 1 + 1;
	const auto dataToSend = new byte[bufSize];
	cpyReverseData(dataToSend, type_of_send_msg_parking_status);
	cpyReverseData(dataToSend + 1, id);
	cpyReverseData(dataToSend + 1 + 4, parkingPlaceId);
	cpyReverseData(dataToSend + 1 + 4 + 1, isFree);
	return dataToSend;
}
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

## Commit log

2017-11-10 Добавил RadioModule
2017-11-12 Реализовано считываение данных с датчиков
2017-12-18 Add Timer
2017-12-18 Fix in Timer
2017-12-25 Fix method as parameter
    [Payment.cpp]
2018-01-18 Fix send parking id
    [SmartParking-sensor.ino]
2018-05-20 Fix recv from LoRa
    [Driver.cpp, RadioModule.cpp, ReceiveMessageHandler.cpp]
2018-05-28 Fix reservation time in seconds
    [ParkingPlace.cpp, Payment.cpp, SmartParking-sensor.ino]
2018-06-12 Fix time in payment
    [Payment.cpp, SmartParking-sensor.ino]
2018-06-28 Add docs
    [Приложение Е.10. Принципиальная МКПМ_А.dwg, Приложение Е.13. Принципиальная схема МКПРСПМ.dwg, Приложение Е.5. Функциональная схема МКПМ.dwg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]
